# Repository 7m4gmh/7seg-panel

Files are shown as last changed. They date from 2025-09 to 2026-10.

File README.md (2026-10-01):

# 7-Segment LED Panel Video Player

A series of tools for playing videos on a custom display panel composed of I2C-connected 7-segment LED modules.

i2cで駆動する自作の7セグメントLEDパネルで、動画を再生するプロジェクト。

---

Note (platform): Developed and tested primarily on Raspberry Pi 3 and Radxa ROCK 5B. It also works on Raspberry Pi 4/5 if I2C is enabled and dependencies are installed (bus numbers/device names may differ).

**macOS Support**: The project includes emulator mode for macOS development and testing. Physical LED panels are automatically simulated with accurate segment rendering and audio synchronization.

注記（プラットフォーム）: 本プロジェクトは主に Raspberry Pi 3 および Radxa ROCK 5B 向けに作成・検証しています。I2C を有効化し依存関係を整えれば Raspberry Pi 4/5 でも動作します（バス番号やデバイス名が異なる場合があります）。

**macOS対応**: 本プロジェクトはmacOSでの開発・テスト用にエミュレータモードを搭載しています。物理的なLEDパネルを自動的にシミュレートし、正確なセグメント描画と音声同期を実現します。

**Languages:**

[**English**](README.en.md) | [**日本語**](README.ja.md) | [**繁體中文**](README.zh-TW.md)

---

**Module Mapping (モジュールマッピング)**

You can define per-module physical mappings in `config.json` to accommodate different wiring or digit order of hardware modules. Use a simple column-reversal flag (`module_column_reverse`) or an explicit logical→physical index map (`module_index_map`). See `docs/module-mapping.md` for details and examples.

ハードウェア毎に桁順や配線が異なる場合、`config.json` でモジュール単位のマッピングを定義できます。簡易的に列方向を反転する `module_column_reverse`（真偽値）を使うか、論理インデックス（左上から行優先）からモジュール内の物理インデックスへ明示的に変換する `module_index_map`（配列）を定義してください。優先順位は `module_index_map` → `module_column_reverse` → 既定順（row-major）です。詳しい書き方とテスト手順は `docs/module-mapping.md` を参照してください。

実機縮退モデルでのデモ動画

実機縮退モデルでのデモ動画 (https://www.instagram.com/reel/DOIo3QTEZs0/?utm_source=ig_web_button_share_sheet)

[エミュレータでの実行例](https://x.com/HijiriUmemoto/status/2095140881489899897?s=20)

---

## Hardware (KiCad)

- PCB projects live under `hardware/`. See: [hardware/README.md](hardware/README.md)
- Current folders (subject to change):
	- `hardware/7seg-led` — LED panel PCB
	- `hardware/7seg-control` — main controller PCB
	- `hardware/7seg-hat` — Raspberry Pi HAT
	- `hardware/7seg-power` — power board
	- Shared libs: `hardware/lib`
	- Legacy/migration folders may also exist (e.g., `hardware/led-panel`, `controller`, `rpi-hat`, `power`).

---
## Build

Prerequisites
- C++17-capable compiler (g++)
- make
- OpenCV 4 (dev package)
- SDL2 (dev package)
- GStreamer 1.0 (for RTP/HTTP streaming tools)

How to build
- By default, running `make` without arguments shows help and does not build anything.
- Use the grouped targets below as needed.

Common targets

```bash

# Show available targets (default)

make core

# GStreamer-based tools: http-streamer / rtp-player
make gst

# Individual targets
make rtp        # 7seg-rtp-player
# (http-streamerは削除済み)

# Everything
make all

# Cleanup
### macOS Emulator Support
The project includes macOS emulator support for development and testing without physical hardware:
- Automatically detects macOS and uses emulator mode
- Physical LED panel simulation with accurate segment shapes
- Optimized performance with pre-cached layouts
- Audio synchronization for smooth playback

**macOSでのビルド:**
```bash
# OpenCVのインストール
brew install opencv

# ビルド
make core

# エミュレータでのテスト
./7seg-file-player test.mp4 emulator-24x4
```

## Recent changes (video scaling behavior)

This project recently received fixes and improvements to the video scaling modes so behavior is consistent across orientations (horizontal/vertical) and between the real-device and emulator playback paths.

- FIT (default): the entire video is scaled to fit inside the display's physical aspect ratio. Black padding (letterboxing/pillarboxing) will be added on the shorter axis. Internally we compute a display-shaped ROI based on the configured module layout and physical character dimensions, scale the source to fit into that ROI, and pass only the ROI downstream for sampling. This prevents accidental cropping or distortion.

- CROP: the video is center-cropped to match the display's physical aspect ratio while preserving the source aspect ratio. After cropping the ROI is passed downstream without forcing a full W×H canvas resize, so the sampled region keeps correct proportions.

- STRETCH: the video is resized non-uniformly to fill the display-shaped ROI (i.e. aspect ratio is not preserved). This intentionally distorts the video to use the full display area.

These changes make the three modes behave predictably for combinations like horizontal video on vertical displays (FIT will letterbox, CROP will center-crop, STRETCH will distort to fill).

## Debug logging

A new runtime flag is available to enable extra debug output for scaling and ROI calculation.

Usage:
```bash
# Enable debug output
./bin/darwin-arm64/7seg-file-player <video> <config> --fit --debug

# Short form
./bin/darwin-arm64/7seg-file-player <video> <config> --fit -d
```

When enabled the player prints per-frame messages like:

- [FIT] source_aspect=... display_aspect=... roi=(x,y,w,h) dst=(w,h)
- [STRETCH] source_aspect=... display_aspect=... roi=(x,y,w,h)

The debug flag is off by default so normal runs are quiet.

## Notes for reviewers / maintainers

- The playback code now avoids forcing a W×H resize for FIT/CROP/STRETCH; we pass an appropriately-shaped ROI to the sampling logic so `frame_to_grid` sees the correct proportions.
- Debug prints are gated by the `--debug`/`-d` switch.
- Some small cleanups were applied (unused variables removed, minor refactor of logging points).

Tip
- For streaming, we recommend the net player with OBS via FLV/TCP:
	- [README.en.md](README.en.md) → "Send directly from OBS (FLV/TCP)"
	- [README.ja.md](README.ja.md) → 「OBSから直接送信（FLV/TCP）」
	- [README.zh-TW.md](README.zh-TW.md) → 「從 OBS 直接傳送（FLV/TCP）」
- Alternatively, the RTP player is available. See usage and sender examples:
	- [README.en.md](README.en.md) → "RTP Player (Recommended)"
	- [README.ja.md](README.ja.md) → 「RTPプレイヤー（推奨）」
	- [README.zh-TW.md](README.zh-TW.md) → 「RTP 播放器（建議）」
- macOS camera sender script included: `send_rtp_cam_gst.sh`
 - For browser-based control and uploads, use the HTTP player/streamer. See:
	 - [README.en.md](README.en.md) → "HTTP Player"
	 - [README.ja.md](README.ja.md) → 「HTTPプレイヤー」
	 - [README.zh-TW.md](README.zh-TW.md) → 「HTTP 播放器」
 - To play a local video file quickly, use the File Player. See:
	 - [README.en.md](README.en.md) → "File Player"
	 - [README.ja.md](README.ja.md) → 「ファイルプレイヤー」
	 - [README.zh-TW.md](README.zh-TW.md) → 「檔案播放器」

- **macOS Emulator**: For testing and development on macOS without physical hardware. See:
	 - [README.emulator.md](README.emulator.md) → "7-Segment LED Panel Emulator"
	 - 物理的なLEDパネルの正確なシミュレーション
	 - 動画ファイルからの再生と音声同期

- Tetris on the LED panel (Python):
	- [README.tetris.en.md](README.tetris.en.md)
	- [README.tetris.md](README.tetris.md)（日本語）
	- [README.tetris.zh-TW.md](README.tetris.zh-TW.md)

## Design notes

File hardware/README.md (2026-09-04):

# Hardware projects

基板ごとに独立した KiCad プロジェクトとして、世代・構成別のフォルダに配置しています。

This folder contains independent KiCad projects grouped by hardware generation and configuration.

## Directory structure

### 040 series

- `040/`
    - `7seg-panel-control-040/`
    - `7seg-panel-control-040-dual/`
    - `7seg-panel-control-040-single/`
    - `7seg-panel-control-04in/`
    - `7seg-panel-display-040-dual/`
    - `7seg-panel-display-040-dual-24x16/`
    - `7seg-panel-expand-040/`
    - `7seg-panel-power-040/`
    - `7seg-panel-single-04in/`
- `040-sparse/`
    - `7seg-panel-040-display-dual-wide/`
    - `7seg-panel-040-dual-combined-sparse/`

### 056 series

- `056/`
    - `7seg-control/`
    - `7seg-led/`
    - `7seg-panel-4digit/`
    - `7seg-panel-single-digit/`
    - `7seg-power/`
- `056-sparse/`
    - `7-seg-panel-0560dual combined-sparse/`
    - `7seg-panel-056-display-wide/`
    - `7seg-panel-056-single-combined-sparse/`
- `056-HT1635D/`
    - `056-ht1635d-driver/`

### Raspberry Pi HAT

- `7seg-hat/`
    - `7seg-hat.kicad_pro`, `7seg-hat.kicad_sch`, `7seg-hat.kicad_pcb`
    - `7seg-hat-backups/`
    - `20250729-7seg-led-panel-hat-backups/`
    - `20250815-7seg-led-panel-hat-backups/`
    - `bom/`
    - `production/`

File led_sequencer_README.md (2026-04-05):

# led_sequencer

`led_sequencer.py` はリポジトリ内の `config.json` を読み、7セグメント表示の点灯シーケンスを実行する簡易スクリプトです。

## 概要
- 各桁について、セグメント A → G を順に 0.5 秒おきに点灯します。
- その後、各桁ごとにその桁のみ全セグメントを 0.5 秒間点灯（他桁は消灯）します。
- 最後の桁が終わると最初に戻り、ループします。

## 必要条件
- Python 3.8+（型注釈の互換性のため）
- `config.json` がスクリプトと同じディレクトリに配置されていること（本リポジトリのルート `7seg-panel/config.json` を参照します）。

## 使い方

```bash
# デフォルト（delay=0.5s, 自動でエミュレータ構成を選択）
python3 led_sequencer.py

# レイアウトを指定する例（config.json のキー名を指定）
python3 led_sequencer.py --layout emulator-24x4

# ディレイを変更する例（秒単位）
python3 led_sequencer.py --delay 0.3
```

## 出力
- 実行中は標準出力にどの桁／セグメントを点灯したかがタイムスタンプ付きで表示されます。実機やエミュレータに接続する場合は、この部分を適宜置き換えてハード制御コードを追加してください。

## 統合のヒント
- エミュレータや実機制御が既にある場合、`print()` 部分をハードウェア駆動 API の呼び出しに差し替えてください。
- 複数プロセスや非同期での制御を行う場合は `asyncio` やスレッドを検討してください。

## ファイル
- スクリプト: `led_sequencer.py`
- 設定: `config.json` (同ディレクトリ)

---
作成者: リポジトリ補助スクリプト（自動生成）

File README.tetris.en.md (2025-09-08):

# Tetris (tetris.py) Run Guide

Instructions to prepare the environment and run the Python script `tetris.py` that drives the 7‑segment LED panel.

## Overview
- Operate the game in your terminal (curses) while rendering the board on an I2C 7‑segment LED panel.
- Supports both a setup with the TCA9548A I2C multiplexer and a direct (no‑mux) setup. See `config.json`.

## Requirements
- OS: Linux
- Python 3.8+
- pip (Python package manager)
- I2C enabled and a device node present (e.g., `/dev/i2c-0` or `/dev/i2c-1`)
- Python package: `smbus2`
- (Optional) I2C tools: `i2c-tools` (`i2cdetect` to verify devices)

## Enable and verify I2C
1) Enable I2C (use your board's config tool / device tree as appropriate)
2) Check device nodes
   ```bash
   ls -l /dev/i2c*
   # e.g. if /dev/i2c-0 exists use bus=0, if /dev/i2c-1 exists use bus=1
   ```
3) (Optional) I2C scan
   ```bash
   sudo apt-get update
   sudo apt-get install -y i2c-tools
   i2cdetect -l           # list available buses
   i2cdetect -y 0         # scan bus 0 (change number to your bus)
   ```

> Note: `tetris.py` uses I2C bus 0 by default (`SMBus(0)`). If your system uses `/dev/i2c-1`, change `SMBus(0)` to `SMBus(1)` in `tetris.py`.

## Setup (recommended: virtualenv)
```bash
# From repo root
python3 -m venv venv
source venv/bin/activate
pip install --upgrade pip
pip install smbus2
```

Permissions
- If you cannot access `/dev/i2c-*`, either:
  - Run with sudo temporarily, or
  - Add your user to the `i2c` group and re‑login:
    ```bash
    sudo usermod -aG i2c $USER
    # log out and back in to apply
    ```

## How to run
- Basic:
  ```bash
  python tetris.py --config 16x12
  ```
- `--config` is one of the names under `configurations` in `config.json`.
  - Examples: `24x4`, `12x8`, `16x8`, `16x12`, `48x4`, `12x8-direct`
- The board size is defined by the chosen config (e.g., `16x12` → 16×12 digits).

## Controls
- Left / Right: move horizontally
- Down: soft‑drop one cell (resets auto‑drop timer)
- Up or Space: rotate
- q: quit

## Config file (config.json) notes
- Pick a configuration name from `configurations` and pass it via `--config`.
- Addresses are hex strings (e.g., `"0x70"`) and are converted to integers in the script.
- With TCA9548A, set `tca9548a_address` to a hex string (e.g., `"0x77"`).
- For direct setups, set `tca9548a_address: null` and use `-1` as the key in `channel_grids`.
- Example: `16x12` uses 4×4‑digit modules arranged 4 (wide) × 3 (high) → total 16×12 digits.

## Troubleshooting
- I2C bus not found (`I2C bus device not found`)
  - Check that `/dev/i2c-*` exists. If your bus is 1, change to `SMBus(1)`.
  - Ensure I2C is enabled in the system.
- I/O errors (`I2C Write Error` or init failures)
  - Verify wiring, power, addresses (with `i2cdetect`), and TCA9548A channel selection.
  - Ensure `channel_grids` in `config.json` matches the actual wiring.
- Terminal issues (black/garbled output)
  - Ensure the terminal has enough width; otherwise visible ASCII render will wrap.
- Display not cleared on exit
  - In rare exceptions cleanup may fail; running the script again typically clears the display.

## Notes
- Auto‑drop speed increases with score (see constants near the top of the file to tune).
- Board rendering uses `'*'` and `'#'` (mapping to 7‑segment via `digit_map`).

---
Minimal example (16x12, bus 0)
```bash
# First‑time deps
python3 -m venv venv
source venv/bin/activate
pip install smbus2

# Run
python tetris.py --config 16x12
```

Bus 1 environment (requires code edit)
```text
# In tetris.py
- bus = SMBus(0)
+ bus = SMBus(1)
```

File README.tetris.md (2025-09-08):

# テトリス（tetris.py）実行ガイド

7セグパネル上でテトリスを動かす Python スクリプト `tetris.py` の環境整備と実行手順です。

## 概要
- 端末（curses）で操作しつつ、I2C接続の7セグパネルに盤面を描画します。
- I2Cマルチプレクサ TCA9548A を使う構成／使わない直結構成の両方に対応します（`config.json` 参照）。

## 必要環境
- OS: Linux
- Python 3.8+
- pip（Pythonパッケージ管理）
- I2Cが有効化されたカーネルとデバイスノード（例: `/dev/i2c-0` もしくは `/dev/i2c-1`）
- Pythonパッケージ: `smbus2`
- (任意) I2Cツール: `i2c-tools`（`i2cdetect` でデバイス確認）

## I2Cの有効化と確認
1) I2Cを有効化（ボードごとの手順に従って設定ツールやDTを有効化）
2) デバイスノード確認
   ```bash
   ls -l /dev/i2c*
   # 例: /dev/i2c-0 があれば bus=0、/dev/i2c-1 があれば bus=1
   ```
3) (任意) I2Cスキャナ
   ```bash
   sudo apt-get update
   sudo apt-get install -y i2c-tools
   i2cdetect -l           # 利用可能なバス一覧
   i2cdetect -y 0         # 0番バスのデバイスを走査（環境に合わせて番号変更）
   ```

> 注意: `tetris.py` は既定で I2C バス番号 0 を使用します（`SMBus(0)`）。環境が `/dev/i2c-1` の場合は、`tetris.py` 内の `SMBus(0)` を `SMBus(1)` に変更してください。

## セットアップ手順（推奨: 仮想環境）
```bash
# リポジトリ直下で
python3 -m venv venv
source venv/bin/activate
pip install --upgrade pip
pip install smbus2
```

権限まわり
- `/dev/i2c-*` へアクセスできない場合は、次のいずれかを実施
  - 一時的に sudo で実行する
  - ユーザーを `i2c` グループへ追加し、再ログイン
    ```bash
    sudo usermod -aG i2c $USER
    # 反映のため一度ログアウト/ログイン
    ```

## 実行方法
- 基本:
  ```bash
  python tetris.py --config 16x12
  ```
- `--config` は `config.json` の `configurations` に定義された名前を指定します。
  - 例: `24x4`, `12x8`, `16x8`, `16x12`, `48x4`, `12x8-direct`
- 盤面サイズは設定により決まります（例: `16x12` は 16桁×12桁）。

## 操作方法（キーバインド）
- ← / →: 水平移動
- ↓: 1マス落下（自動落下タイマーをリセット）
- ↑ または Space: 回転
- q: 終了

## 設定ファイル（config.json）の要点
- `configurations` から構成名を選びます（`--config` で指定）。
- アドレス表記は 16進文字列（例: `"0x70"`）。スクリプト側で数値へ変換されます。
- TCA9548A を使う場合は `tca9548a_address` に 16進文字列（例: `"0x77"`）を設定。
- 直結構成は `tca9548a_address: null` とし、`channel_grids` のキーに `-1` を用います。
- 例: `16x12` 構成は 4桁×4桁モジュールを横4×縦3で合計 16×12 桁。

## トラブルシューティング
- I2C バスが見つからない（`I2C bus device not found`）
  - `/dev/i2c-*` の存在を確認。バス番号が 1 なら `SMBus(1)` に変更。
  - I2C を有効化したか確認。
- I/O エラー（`I2C Write Error` や 初期化失敗）
  - 配線、電源、アドレス（`i2cdetect` で確認）、TCA9548A のチャンネル切替を確認。
  - `config.json` の `channel_grids` と実配線が一致しているか確認。
- 端末が真っ黒／文字化け
  - リモート端末の幅が狭いと可視表示が折り返すことがあります。端末幅を確保。
- 終了時に表示が消えない
  - 例外時に消去できないケースがあります。再実行すると最終化処理で消去されます。

## 補足
- 既定の落下速度はスコアに応じて速くなります（ファイル先頭の定数で調整可能）。
- 描画は `'*'` と `'#'` を使っています（7セグ表示器へのマッピングは `digit_map` に定義）。

---
最小構成の実行例（16x12, バスが 0 の場合）
```bash
# 依存インストール（初回のみ）
python3 -m venv venv
source venv/bin/activate
pip install smbus2

# 実行
python tetris.py --config 16x12
```

バスが 1 の環境例（コード修正の必要あり）
```text
# tetris.py の該当行
- bus = SMBus(0)
+ bus = SMBus(1)
```

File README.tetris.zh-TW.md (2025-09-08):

# 俄羅斯方塊（tetris.py）執行指南

本文件說明如何準備環境並執行 `tetris.py`，在 7 段顯示器 LED 面板上運行俄羅斯方塊。

## 概述
- 透過終端機（curses）操作，同步在 I2C 連接的 7 段顯示器面板上繪製棋盤。
- 同時支援使用 TCA9548A I2C 多工器的組態與不使用多工器的直連組態（見 `config.json`）。

## 系統需求
- OS: Linux
- Python 3.8+
- pip（Python 套件管理）
- 已啟用 I2C 並存在裝置節點（例如 `/dev/i2c-0` 或 `/dev/i2c-1`）
- Python 套件：`smbus2`
- （選用）I2C 工具：`i2c-tools`（用 `i2cdetect` 驗證裝置）

## 啟用並確認 I2C
1) 啟用 I2C（依您的開發板設定工具 / DT 流程）
2) 檢查裝置節點
   ```bash
   ls -l /dev/i2c*
   # 範例：若存在 /dev/i2c-0 則 bus=0；若存在 /dev/i2c-1 則 bus=1
   ```
3) （選用）I2C 掃描
   ```bash
   sudo apt-get update
   sudo apt-get install -y i2c-tools
   i2cdetect -l           # 列出可用的匯流排
   i2cdetect -y 0         # 掃描 0 號匯流排（依環境修改編號）
   ```

> 注意：`tetris.py` 預設使用 I2C 匯流排 0（`SMBus(0)`）。若系統使用 `/dev/i2c-1`，請將 `tetris.py` 內的 `SMBus(0)` 改為 `SMBus(1)`。

## 安裝步驟（建議：虛擬環境）
```bash
# 於倉庫根目錄
python3 -m venv venv
source venv/bin/activate
pip install --upgrade pip
pip install smbus2
```

權限
- 若無法存取 `/dev/i2c-*`，請：
  - 暫時以 sudo 執行，或
  - 將使用者加入 `i2c` 群組並重新登入：
    ```bash
    sudo usermod -aG i2c $USER
    # 重新登入以套用
    ```

## 執行方式
- 基本：
  ```bash
  python tetris.py --config 16x12
  ```
- `--config` 需為 `config.json` 之 `configurations` 下的名稱。
  - 範例：`24x4`, `12x8`, `16x8`, `16x12`, `48x4`, `12x8-direct`
- 棋盤尺寸由設定決定（例如 `16x12` → 16×12 位數）。

## 操作方式（快捷鍵）
- ← / →：水平移動
- ↓：下降一格（重設自動下落計時）
- ↑ 或 Space：旋轉
- q：結束

## 設定檔（config.json）重點
- 從 `configurations` 中選擇組態名稱，並以 `--config` 指定。
- 位址以十六進位字串表示（例如 `"0x70"`），腳本內會轉為數值。
- 使用 TCA9548A 時，`tca9548a_address` 請填十六進位字串（例如 `"0x77"`）。
- 直連組態請設 `tca9548a_address: null`，並在 `channel_grids` 中使用 `-1` 作為鍵。
- 例：`16x12` 使用 4×4 位數模組，橫向 4、縱向 3，合計 16×12 位數。

## 疑難排解
- 找不到 I2C 匯流排（`I2C bus device not found`）
  - 確認 `/dev/i2c-*` 存在。若為匯流排 1，請改成 `SMBus(1)`。
  - 確認系統已啟用 I2C。
- I/O 錯誤（`I2C Write Error` 或初始化失敗）
  - 檢查接線、電源、位址（用 `i2cdetect`）、TCA9548A 通道切換。
  - `config.json` 的 `channel_grids` 是否與實際接線相符。
- 終端機畫面全黑或亂碼
  - 若寬度不足，ASCII 繪圖會換行；請確保足夠寬度。
- 結束時面板未清除
  - 少數例外狀況清理可能失敗；再次執行通常會清除。

## 補充
- 自動下落速度會隨分數提升（可於檔案開頭的常數調整）。
- 棋盤繪圖使用 `'*'` 與 `'#'`（對應 7 段顯示器的 `digit_map`）。

---
最小範例（16x12，匯流排 0）
```bash
# 第一次安裝依賴
python3 -m venv venv
source venv/bin/activate
pip install smbus2

# 執行
python tetris.py --config 16x12
```

匯流排 1（需修改程式碼）
```text
# 於 tetris.py
- bus = SMBus(0)
+ bus = SMBus(1)
```

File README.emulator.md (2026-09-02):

# 7-Segment LED Panel Emulator

macOS上で7セグメントLEDパネルの動作をエミュレートするソフトウェアです。物理的なLEDパネルの正確な外観と動作をシミュレートします。

## 概要

このエミュレータは、i2cで動作する物理的な7セグメントLEDパネルを、macOS環境で視覚的に再現するためのツールです。OpenCVを使用して物理的なLEDの形状、傾き、配置を正確にシミュレートします。

## 主な特徴

### 🎯 正確な物理シミュレーション
- **7セグメントLED**: 物理的な7セグメントLEDの形状を正確に再現
- **スケール調整**: 8倍スケールで視認性を確保しつつ物理比率を維持

### ⚡ 高性能最適化
- **プリキャッシュ**: 起動時に全セグメントの座標を計算してメモリに格納
- **音声同期**: 動画再生時の音声との同期を最適化

### 🎮 使いやすいインターフェース
- **自動モード検出**: config.jsonから自動的にエミュレータモードを検出
- **リアルタイム表示**: OpenCVウィンドウでリアルタイムにLED表示
- **キーボード制御**: ESCキーで再生停止

## 必要条件

### システム要件
- **macOS** (10.15以上推奨)
- **C++17** 対応コンパイラ
- **OpenCV 4** (Homebrewでインストール)

### 依存関係のインストール
```bash
# HomebrewでOpenCVをインストール
brew install opencv

# SDL2もインストール（音声再生用）
brew install sdl2
```

## ビルド方法

### 完全ビルド
```bash
# すべてのターゲットをビルド
make all
```

### エミュレータ専用ビルド
```bash
# コアプレイヤーのみビルド（エミュレータを含む）
make core
```

## 使用方法

### 基本的な使い方

1. **設定ファイルの準備**
   ```json
   {
     "type": "emulator",
     "total_width": 24,
     "total_height": 4,
     "configurations": {
       "emulator-24x4": {
         "total_width": 24,
         "total_height": 4
       }
     }
   }
   ```

2. **動画ファイルの再生**
   ```bash
   # 設定ファイルで指定した構成で再生
   ./7seg-file-player video.mp4 emulator-24x4

   # または直接設定
   ./7seg-file-player video.mp4 emulator-20x20

  # 設定ファイルのパスを明示的に指定
  ./7seg-file-player video.mp4 emulator-36x16 --config-file ./config.json
   ```

### 設定オプション

#### ディスプレイサイズ
- `emulator-24x4`: 24桁 × 4行（標準サイズ）
- `emulator-20x20`: 20桁 × 20行（大画面）
- カスタムサイズも指定可能

#### 設定ファイル (config.json)
```json
{
  "type": "emulator",
  "total_width": 24,
  "total_height": 4,
  "configurations": {
    "emulator-24x4": {
      "total_width": 24,
      "total_height": 4
    }
  }
}
```

### 再生制御

- **ESCキー**: 再生停止
- **Ctrl+C**: プログラム終了

### MP4への録画

エミュレータ画面をそのまま MP4 に保存できます。録画時は音声も同時に記録され、通常のエミュレータ再生と同じ同期ロジックで出力されます。

```bash
./7seg-file-player video.mp4 emulator-24x4 --record-mp4 output.mp4
```

設定ファイルを別パスに置いている場合は、`--config-file` を併用できます。

```bash
./7seg-file-player video.mp4 emulator-36x16 --config-file ./config.json --record-mp4 output.mp4
```

録画先を指定すると、表示されるエミュレータ画面をそのまま書き出します。

## アーキテクチャ

### セグメント描画アルゴリズム

エミュレータは物理的な7セグメントLEDの正確な形状を再現するために、以下の計算を行っています：

1. **六角形セグメント生成**
   ```cpp
   // 横セグメントの六角形形状
   std::vector<cv::Point> horizontal_segment(double x, double y) {
       // 六角形の頂点座標を計算
   }
   ```

2. **縦セグメントの回転**
   ```cpp
   // 横セグメントを90±10度回転
   std::vector<cv::Point> vertical_segment(double x, double y, double tilt_deg)
   ```

3. **レイアウト計算**
   ```cpp
   // 全セグメントの最終位置を計算
   SegmentLayout make_layout(int digit_idx, double package_center_x, double package_center_y)
   ```

### パフォーマンス最適化

#### プリキャッシュシステム
```cpp
struct CachedDisplayLayout {
    std::vector<std::vector<std::vector<cv::Point>>> all_segs; // 全桁のセグメント
    std::vector<cv::Point> all_dp_centers; // 小数点位置
    std::vector<int> all_dp_radii; // 小数点半径
    std::vector<std::pair<double, double>> package_centers; // パッケージ中心座標
};
```

#### 音声同期
- 動画フレームの理想タイミングを計算
- 遅延が発生した場合のフレームスキップ処理
- 音声再生との同期維持

## 技術仕様

### 物理パラメータ
- **パッケージ幅**: 12.7mm
- **パッケージ高**: 19.05mm
- **セグメント長**: 6.0mm
- **セグメント幅**: 2.0mm
- **傾き角度**: 10度
- **表示スケール**: 8倍

### 色設定
- **点灯セグメント**: 赤 (BGR: 0, 0, 255)
- **消灯セグメント**: 灰色 (BGR: 80, 80, 80)
- **背景**: 黒 (BGR: 0, 0, 0)

## トラブルシューティング

### ビルドエラー
```bash
# OpenCVが見つからない場合
brew install opencv

# パスが通っていない場合
export PKG_CONFIG_PATH="/opt/homebrew/lib/pkgconfig:$PKG_CONFIG_PATH"
```

### 実行時エラー
```bash
# 動画ファイルが見つからない
ls -la video.mp4

# 設定ファイルの確認
cat config.json
```

### パフォーマンス問題
- **遅延が大きい**: ディスプレイサイズを小さくする
- **CPU使用率が高い**: より高性能なマシンを使用
- **メモリ不足**: ディスプレイサイズを調整

## 開発情報

### ソースコード構造
```
src/
├── playback.cpp          # メイン再生ロジック
├── emulator_display.cpp  # エミュレータ表示クラス（オリジナル）
└── common.h             # 共通定義
```

### 主要関数
- `play_video_stream_emulator()`: エミュレータ再生メイン関数
- `create_cached_layout()`: レイアウトプリキャッシュ関数
- `make_layout()`: 個別セグメントレイアウト計算
- `horizontal_segment()`: 横セグメント形状生成
- `vertical_segment()`: 縦セグメント形状生成

## 関連リンク

- [メインREADME](README.md)
- [英語版README](README.en.md)
- [日本語版README](README.ja.md)
- [テトリス版README](README.tetris.md)

## ライセンス

ライセンスについては考え中。ひとまず留保します。個人的に使っていただく分には自由です。

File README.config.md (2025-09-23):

# config.json の説明

## 概要

`config.json` は、7seg-panel のディスプレイ構成を定義する設定ファイルです。このファイルでは、LED パネルの物理的な接続構成を JSON 形式で記述します。主に TCA9548A I2C マルチプレクサを使用した複雑な接続をサポートしています。

## 基本構造

```json
{
  "comment_char_dimensions": "LED character dimensions in mm",
  "char_width_mm": 12.7,
  "char_height_mm": 19.2,

  "comment_configs": "Display panel configurations",
  "configurations": {
    "config_name": {
      "name": "Display Name",
      "buses": {
        "bus_id": {
          "tca9548as": [
            {
              "address": "0x77",
              "channels": {
                "channel_id": [
                  ["0x70", "0x71"],
                  ["0x72", "0x73"]
                ]
              }
            }
          ]
        }
      },
      "module_digits_width": 4,
      "module_digits_height": 4,
      "total_width": 8,
      "total_height": 8
    }
  }
}
```

## フィールドの詳細

### ルートレベル

- `char_width_mm`: 7セグメントLEDのパッケージの幅 (mm)
- `char_height_mm`: L7セグメントLEDのパッケージの高さ (mm)
- `configurations`: 各構成の定義

### configurations の各エントリ

- `name`: 構成の表示名
- `type`: 構成のタイプ ("physical" または "emulator") - オプション、デフォルトは "physical"
- `buses`: Bus の定義 (オブジェクト)
- `module_digits_width`: 各モジュールの桁数 (幅)
- `module_digits_height`: 各モジュールの桁数 (高さ)
- `total_width`: 全体の桁数 (幅)
- `total_height`: 全体の桁数 (高さ)

### buses

Bus ID をキーとするオブジェクト。各 Bus は以下の構造を持ちます：

- `tca9548as`: TCA9548A の配列

### tca9548as の各エントリ

- `address`: TCA9548A の I2C アドレス (16進数文字列、例: "0x77") または null (直接接続)
- `channels`: チャンネルの定義 (オブジェクト)
- `rows`: 行ベースのレイアウト定義 (オブジェクト、オプション)

### channels

チャンネル ID をキーとするオブジェクト。各チャンネルは LED モジュールのグリッド (2D 配列) を値とします。

- グリッドは行の配列
- 各行はモジュールアドレスの配列 (16進数文字列)

### rows (48x8 構成用)

行 ID をキーとするオブジェクト。各行は以下の構造を持ちます：

- `channel`: 使用する TCA9548A チャンネル ID
- `row_offset`: 行のオフセット (桁単位)
- `col_offset`: 列のオフセット (桁単位)

この設定は、異なるチャンネルが同じ行に配置される複雑なレイアウトで使用します。

## 例

### 単純な構成 (24x4)

```json
{
  "configurations": {
    "24x4": {
      "name": "24x4 Horizontal",
      "buses": {
        "0": {
          "tca9548as": [
            {
              "address": "0x77",
              "channels": {
                "0": [
                  ["0x70", "0x71", "0x72", "0x73", "0x74", "0x75"]
                ]
              }
            }
          ]
        }
      },
      "module_digits_width": 4,
      "module_digits_height": 4,
      "total_width": 24,
      "total_height": 4
    }
  }
}
```

### 複数の TCA9548A を使用した構成

```json
{
  "configurations": {
    "12x8": {
      "name": "12x8 Expanded",
      "buses": {
        "0": {
          "tca9548as": [
            {
              "address": "0x77",
              "channels": {
                "0": [
                  ["0x70", "0x71", "0x72"]
                ]
              }
            },
            {
              "address": "0x76",
              "channels": {
                "0": [
                  ["0x70", "0x71", "0x72"]
                ]
              }
            }
          ]
        }
      },
      "module_digits_width": 4,
      "module_digits_height": 4,
      "total_width": 12,
      "total_height": 8
    }
  }
}
```

### 直接接続の構成

```json
{
  "configurations": {
    "12x8-direct": {
      "name": "12x8 Direct",
      "buses": {
        "0": {
          "tca9548as": [
            {
              "address": null,
              "channels": {
                "-1": [
                  ["0x70", "0x71", "0x72"],
                  ["0x73", "0x74", "0x75"]
                ]
              }
            }
          ]
        }
      },
      "module_digits_width": 4,
      "module_digits_height": 4,
      "total_width": 12,
      "total_height": 8
    }
  }
}
```

### 48x8 行ベース構成 (rows 使用)

```json
{
  "configurations": {
    "48x8": {
      "name": "48x8 Expanded (4 channels with row-based layout)",
      "buses": {
        "1": {
          "tca9548as": [
            {
              "address": "0x77",
              "channels": {
                "0": [
                  ["0x70", "0x71", "0x72", "0x73", "0x74", "0x75"]
                ],
                "1": [
                  ["0x70", "0x71", "0x72", "0x73", "0x74", "0x75"]
                ],
                "2": [
                  ["0x70", "0x71", "0x72", "0x73", "0x74", "0x75"]
                ],
                "3": [
                  ["0x70", "0x71", "0x72", "0x73", "0x74", "0x75"]
                ]
              },
              "rows": {
                "0": {"channel": 0, "row_offset": 0, "col_offset": 0},
                "1": {"channel": 2, "row_offset": 0, "col_offset": 24},
                "2": {"channel": 1, "row_offset": 4, "col_offset": 0},
                "3": {"channel": 3, "row_offset": 4, "col_offset": 24}
              }
            }
          ]
        }
      },
      "module_digits_width": 4,
      "module_digits_height": 4,
      "total_width": 48,
      "total_height": 8
    }
  }
}
```

この構成では、4つの TCA9548A チャンネルが使用され、rows 設定により異なるチャンネルが同じ行に配置されます：
- 行0: チャンネル0 (左半分) と チャンネル2 (右半分) が同じ行に配置
- 行1: チャンネル1 (左半分) と チャンネル3 (右半分) が同じ行に配置

## 注意点

- アドレスは 16進数文字列で指定 (例: "0x70")
- 直接接続の場合、`address` を `null` に設定し、`channels` のキーを "-1" にする
- エミュレータの場合、`buses` を空オブジェクト `{}` に設定
- グリッドのサイズは `total_width` と `total_height` と一致するようにする
- TCA9548A のチャンネルは 0-7 の範囲を使用可能 (8チャンネル対応)

## 変更履歴

- 初期バージョン: 古い `tca9548a_address` と `channel_grids` 構造
- 現在のバージョン: `buses` 構造で複数の TCA9548A と Bus をサポート
- 48x8 対応: `rows` 構造で異なるチャンネルが同じ行に配置されるレイアウトをサポート</content>
<parameter name="filePath">/home/hijiri/7seg-panel/README.config.md

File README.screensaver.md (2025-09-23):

# LED Screensaver

7セグメントLEDパネル用のスクリーンセーバープログラムです。複数のアニメーションモードを備えています。

## 機能

- **IPアドレス表示**: 現在のIPアドレスをセンタリングして表示
- **Breakoutゲーム**: パドルでボールを跳ね返し、ブロックを破壊するゲーム
- **Invadersゲーム**: 砲台から弾を発射して敵を倒すゲーム
- **Miyajimaモード**: カウントアップアニメーション
- **Miyajima2モード**: カウントアップ + スクロールアニメーション
- **Clockモード**: 現在の時刻を表示

## インストール

依存パッケージのインストール:
```bash
pip install smbus2
```

## 実行方法

基本的な実行:
```bash
python screensaver.py
```

### コマンドラインオプション

- `--config CONFIG`: 設定ファイルの名前 (デフォルト: 16x12)
- `--mode MODE`: 固定モードで実行 (ip, breakout, invaders, miyajima, miyajima2, clock)
- `--test`: テスト表示モード

### 使用例

特定のモードで実行:
```bash
python screensaver.py --mode breakout
```

設定ファイルを指定:
```bash
python screensaver.py --config 48x8 --mode clock
```

テスト表示:
```bash
python screensaver.py --test
```

## 各モードの説明

### IPモード
現在のネットワークIPアドレスを取得して、ディスプレイの中央に表示します。

### Breakoutモード
古典的なブロック崩しゲームです：
- パドルが自動で左右に移動
- ボールが跳ね返る
- ブロックをすべて壊すとリセット

### Invadersモード
インベーダーゲーム風：
- 上部に敵が配置
- 下部に砲台があり、自動で弾を発射
- 敵をすべて倒すとリセット

### Miyajimaモード
カウントアップアニメーションを表示します。

### Miyajima2モード
カウントアップとスクロールアニメーションを組み合わせた表示です。

### Clockモード
現在の時刻をHH:MM:SS形式で表示します。

## 設定

`config.json`ファイルでディスプレイの構成を定義します。設定名を`--config`オプションで指定してください。

## システム要件

- Python 3.x
- smbus2ライブラリ
- I2C対応の7セグメントLEDパネル
- Raspberry PiなどのLinux環境

## ライセンス

このプロジェクトのライセンス情報を確認してください。

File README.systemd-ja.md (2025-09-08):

# 7seg-net-player を systemd サービスとして動かす手順

本書は 7seg-net-player（FLV/TCP または TS/UDP の受信再生）を systemd サービスとして常時運用するためのセットアップ手順です。

## 前提
- 本リポジトリを /home/radxa/7seg-panel に配置
- バイナリをビルド済み
  - `make net`
- 受信モード:
  - FLV/TCP: `./7seg-net-player flv <config> <port>`
  - TS/UDP : `./7seg-net-player ts  <config> <port>`
- デフォルト動作は EOS/ERROR で即終了（EXIT_ON_EOF=1 相当）

## 導入手順（root 権限）
1. ユニットと環境ファイルを配置
```bash
sudo install -m 644 systemd/7seg-net-player.service /etc/systemd/system/7seg-net-player.service
sudo install -m 644 systemd/7seg-net-player.env /etc/default/7seg-net-player
```

2. 環境ファイルを編集（モード/解像度/ポート等）
```bash
sudo editor /etc/default/7seg-net-player
# 例:
# WORKDIR=/home/radxa/7seg-panel
# MODE=flv
# CONFIG=16x12
# PORT=5004
# EXIT_ON_EOF=1
```

3. 起動・有効化
```bash
sudo systemctl daemon-reload
sudo systemctl enable --now 7seg-net-player.service
```

4. 状態/ログ
```bash
systemctl status 7seg-net-player.service
journalctl -u 7seg-net-player -f
```

## OBS/送信側の設定（FLV/TCP）
- OBS: 録画 → カスタム出力(FFmpeg)
  - コンテナ: flv
  - 出力URL: `tcp://<受信機IP>:<PORT>`
  - 映像: H.264 / 音声: AAC

## 運用メモ
- 本体は EOS/ERROR で即終了 → systemd が自動再起動し、常に待ち受けに戻ります。
- 終了させたくない場合は `/etc/default/7seg-net-player` の `EXIT_ON_EOF=0` に設定してください。
- `User`/`Group` は環境に合わせて `/etc/systemd/system/7seg-net-player.service` を編集してください。
- TS/UDP 運用に切替える場合は `MODE=ts` とし、送信側は MPEG-TS(UDP) を指定してください。

## アンインストール
```bash
sudo systemctl disable --now 7seg-net-player.service
sudo rm -f /etc/systemd/system/7seg-net-player.service
sudo rm -f /etc/default/7seg-net-player
sudo systemctl daemon-reload
```

---
補足: リポジトリ内の `stream.sh` でも同等の起動が可能です（常駐運用には systemd を推奨）。

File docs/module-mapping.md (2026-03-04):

**Module Mapping (モジュールマッピング)**

簡潔: パネルごとの物理的な桁・セグメント配置を `config.json` で定義できます。

**サマリ**:
- **目的**: ハードウェアごとに桁順や配線が違う場合に、プログラムを修正せず設定だけで対応する。
- **形式**: `module_column_reverse`（真偽値）または `module_index_map`（明示的なインデックス配列）を使用します。

**設定場所**:
- ファイル: [config.json](config.json)

**優先順位（フォールバック）**:
1. `module_index_map` が存在すればそれを使用（論理 -> 物理インデックスの完全マップ）
2. `module_column_reverse` が true なら列（横方向）を反転して適用
3. 上記が無ければ既定の行優先（row-major）順序を使用

**キーのルール**:
- モジュールのアドレスは文字列で指定します（例: `"0x70"`）。
- `module_index_map` の配列長は `module_digits_width * module_digits_height` と一致させてください。

**例: 列反転 (簡易)**
```
"module_column_reverse": {
  "0x70": true,
  "0x71": true
}
```

この場合、該当モジュール内の列順が左右反転されます（モジュールが左右逆に配線されているときに有効）。

**例: 明示的なインデックスマップ（推奨・柔軟）**
```
"module_index_map": {
  "0x70": [6,7,4,5,2,3,0,1,14,15,12,13,10,11,8,9],
  "0x71": [6,7,4,5,2,3,0,1,14,15,12,13,10,11,8,9]
}
```
配列インデックスの意味: 配列の位置 `i` が「論理インデックス」（左上から行優先で i=0..N-1）で、配列の値 `module_index_map[ i ]` がその論理位置に書き込むべき物理インデックス（モジュール内部の配線インデックス）です。

具体例: `module_digits_width=8, module_digits_height=2` の場合、論理インデックスは
```
 0 1 2 3 4 5 6 7
 8 9 A B C D E F
```
で表され、上記マップは各論理位置がどの物理位置に当たるかを指定します。

**コード側の振る舞い（参照用）**
- JSON 読み込み: [src/config_loader.hpp](src/config_loader.hpp) で `module_column_reverse` / `module_index_map` を読み込みます。
- マッピング適用: [src/led.cpp](src/led.cpp) の表示更新処理が、`module_index_map` を最優先で使い、無ければ `module_column_reverse` を参照します。

**テスト方法**
- 既存のテスト設定を使う:
  - `8x2-direct-map` / `8x4-direct-rev` はサンプルです。
- ビルドと起動:
```
make core
sudo ./bin/*/7seg-udp-player 5000 8x4-direct-rev
```
- マッピング確認用スクリプト:
  - `scripts/test_mapping.py --name <config> --live` で各文字位置を順に点灯できます（`smbus2` が必要）。

**実践的なアドバイス**
- まず `module_index_map` を作って小さな範囲で試すと確実です。
- モジュールごとに異なる配線がある場合は、各アドレスに対して個別に `module_index_map` を指定します。

**参考ファイル**:
- JSON 読み込み: [src/config_loader.hpp](src/config_loader.hpp)
- マッピング適用: [src/led.cpp](src/led.cpp)
- 例設定: [config.json](config.json)

---

必要があればこのドキュメントに図や追加例（4x4 の例、8x2 の物理配線図）を追加します。どの例を足しましょうか？

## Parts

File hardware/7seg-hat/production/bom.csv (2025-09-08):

Designator | Footprint | Quantity | Value | LCSC Part #
C101 | CP_EIA-3528-21_Kemet-B | 1 | 22uF
C103 | 0603 | 1 | 22uF 6V
J101, J104 | JST_XH_S2B-XH-A-1_1x02_P2.50mm_Horizontal | 2 | i2c
J102 | RPI_Hat_B+ | 1 | Raspberry_Pi_4
J103 | JST_XH_S2B-XH-A-1_1x02_P2.50mm_Horizontal | 1 | GND-VDD
Q101, Q102 | SOT-23_Handsoldering | 2 | BSS138
R101, R102, R103, R104 | 0603 | 4 | 4k7R
U101 | TO-220-3_Vertical | 1 | K7805M-2000

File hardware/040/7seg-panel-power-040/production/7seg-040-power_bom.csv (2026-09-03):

Designator | Footprint | Quantity | Value | LCSC Part #
C101 | CP_EIA-3528-21_Kemet-B | 1 | 22uF
C102 | 0805 | 1 | 4700pF (472)
C104 | 0603 | 1 | 22uF 6V
C106 | CP_Radial_D6.3mm_P2.50mm | 1 | 220uF
C108 | 0805 | 1 | 1uF
F102 | 2920 | 1 | Polyfuse 4A
J101, J104 | Generic_XH_S2B-XH-A-1_1x02_P2.50mm_Horizontal | 2 | +35V GND
J102 | USB_C_Receptacle_HRO_TYPE-C-31-M-17 | 1 | USB_C_Receptacle_PowerOnly_6P
J103 | Generic_XH_S2B-XH-A-1_1x02_P2.50mm_Horizontal | 1 | +5V GND
J201, J202 | BarrelJack_Singatron_2DC-0415D200-SMT_Horizontal | 2 | Barrel_Jack_Switch
R104 | 0805 | 1 | 1MR
R105, R106 | 0805 | 2 | 5k1R
R107 | 0805 | 1 | 200kR
R108 | 1210 | 1 | 1kR
U101 | TO-220-3_Vertical | 1 | K7805M-2000
U103 | TSOT-23-6_HandSoldering | 1 | CH221K

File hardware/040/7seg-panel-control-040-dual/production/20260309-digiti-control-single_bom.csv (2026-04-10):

Designator | Footprint | Quantity | Value | LCSC Part #
C102, C105 | 0603 | 2 | 22uF
C104, C107 | 0603 | 2 | 0.1uF
D102, D103 | D_SOD-123 | 2 | 1N4148W
J102, J105, J108, J112, J115, J118 | PinSocket_2x04_P2.54mm_Vertical | 6 | Conn_02x04_Odd_Even
J107, J117 | Generic_XH_S2B-XH-A-1_1x02_P2.50mm_Horizontal | 2 | I2C
J110, J120 | PinHeader_2x03_P2.54mm_Vertical | 2 | Conn_02x03_Odd_Even
J113, J114 | Generic_XH_S2B-XH-A-1_1x02_P2.50mm_Horizontal | 2 | +5V
R102, R103, R104, R105, R106, R107 | 0603 | 6 | 39kR
U102, U103 | SOP-28_8.4x18.16mm_P1.27mm | 2 | HT16K33-28-SOPA

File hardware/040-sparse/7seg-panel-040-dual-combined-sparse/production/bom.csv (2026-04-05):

Designator | Footprint | Quantity | Value | LCSC Part #
C103 | 0603 | 1 | 22uF
C106, C107 | 0603 | 2 | 0.1uF
D102, D103 | D_SOD-123 | 2 | 1N4148W
J114, J115 | JST_XH_B2B-XH-AM_1x02_P2.50mm_Vertical | 2 | +5V
J116, J117 | PinHeader_2x03_P2.54mm_Vertical | 2 | Conn_02x03_Odd_Even
J118, J121 | JST_XH_B2B-XH-AM_1x02_P2.50mm_Vertical | 2 | I2C
R124, R125, R126, R127, R128, R129 | 0603 | 6 | 39kR
U100, U101, U102, U103, U104, U105, U106, U107, U108, U109, U110, U111, U112, U113, U114, U115 | YH-2E20402-12P | 16 | YH-2E20402-IK
U116, U117 | SSOP-28_3.9x9.9mm_P0.635mm | 2 | HT16K33-28-SSOPA

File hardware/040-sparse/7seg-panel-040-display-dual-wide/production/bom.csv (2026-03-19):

Designator | Footprint | Quantity | Value | LCSC Part #
J100, J101, J102, J103, J104, J105 | PinHeader_2x04_P2.54mm_Vertical | 6 | Conn_02x04_Odd_Even
U100, U101, U102, U103, U104, U105, U106, U107, U108, U109, U110, U111, U112, U113, U114, U115 | YH-2E20402-12P | 16 | YH-2E20402-IK

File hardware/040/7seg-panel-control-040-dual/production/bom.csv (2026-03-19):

Designator | Footprint | Quantity | Value | LCSC Part #
C103 | 0603 | 1 | 22uF
C106 | 0603 | 1 | 0.1uF
D102 | D_SOD-123 | 1 | 1N4148W
J108, J110, J112 | PinSocket_2x04_P2.54mm_Vertical | 3 | Conn_02x04_Odd_Even
J114, J115 | JST_XH_S2B-XH-A_1x02_P2.50mm_Horizontal | 2 | +5V
J116 | PinHeader_2x03_P2.54mm_Vertical | 1 | Conn_02x03_Odd_Even
J118, J121 | JST_XH_S2B-XH-A_1x02_P2.50mm_Horizontal | 2 | I2C
R124, R125, R126 | 0603 | 3 | 39kR
U103 | SOP-28_8.4x18.16mm_P1.27mm | 1 | HT16K33-28-SOPA

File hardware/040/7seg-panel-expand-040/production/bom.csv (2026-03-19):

Designator | Footprint | Quantity | Value | LCSC Part #
C102 | 0603 | 1 | 22uF
C105 | 0603 | 1 | 0.1uF
J101 | Generic_XH_S2B-XH-A-1_1x02_P2.50mm_Horizontal | 1 | CH1
J102, J104 | JST_XH_B2B-XH-AM_1x02_P2.50mm_Vertical | 2 | I2C
J103 | Generic_XH_S2B-XH-A-1_1x02_P2.50mm_Horizontal | 1 | CH2
J105 | Generic_XH_S2B-XH-A-1_1x02_P2.50mm_Horizontal | 1 | CH3
J106 | Generic_XH_S2B-XH-A-1_1x02_P2.50mm_Horizontal | 1 | CH4
J107 | Generic_XH_S2B-XH-A-1_1x02_P2.50mm_Horizontal | 1 | CH6
J109 | Generic_XH_S2B-XH-A-1_1x02_P2.50mm_Horizontal | 1 | CH7
J111 | Generic_XH_S2B-XH-A-1_1x02_P2.50mm_Horizontal | 1 | CH8
J113 | Generic_XH_S2B-XH-A-1_1x02_P2.50mm_Horizontal | 1 | CH5
J117 | PinHeader_2x03_P2.54mm_Vertical | 1 | Conn_02x03_Odd_Even
J119, J120 | JST_XH_B2B-XH-AM_1x02_P2.50mm_Vertical | 2 | +5V
JP101 | PinHeader_1x03_P2.54mm_Vertical | 1 | A2
R107, R108, R109, R110, R111, R112, R113, R114, R115, R116, R117, R118, R119, R120, R121, R122, R123 | 0603 | 17 | 4.7kR
U102 | TSSOP-24_4.4x7.8mm_P0.65mm | 1 | TCA9548APWR

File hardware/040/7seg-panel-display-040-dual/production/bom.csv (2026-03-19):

Designator | Footprint | Quantity | Value | LCSC Part #
J100_12, J100_11, J100_10, J100_9, J100_8, J100_7, J100_6, J100_5, J100_4, J100_3, J100_2, J100, J101_12, J101_11, J101_10, J101_9, J101_8, J101_7, J101_6, J101_5, J101_4, J101_3, J101_2, J101, J102_12, J102_11, J102_10, J102_9, J102_8, J102_7, J102_6, J102_5, J102_4, J102_3, J102_2, J102, J103_12, J103_11, J103_10, J103_9, J103_8, J103_7, J103_6, J103_5, J103_4, J103_3, J103_2, J103, J104_12, J104_11, J104_10, J104_9, J104_8, J104_7, J104_6, J104_5, J104_4, J104_3, J104_2, J104, J105_12, J105_11, J105_10, J105_9, J105_8, J105_7, J105_6, J105_5, J105_4, J105_3, J105_2, J105 | PinHeader_2x04_P2.54mm_Vertical | 72 | Conn_02x04_Odd_Even
U100_12, U100_11, U100_10, U100_9, U100_8, U100_7, U100_6, U100_5, U100_4, U100_3, U100_2, U100, U101_12, U101_11, U101_10, U101_9, U101_8, U101_7, U101_6, U101_5, U101_4, U101_3, U101_2, U101, U102_12, U102_11, U102_10, U102_9, U102_8, U102_7, U102_6, U102_5, U102_4, U102_3, U102_2, U102, U103_12, U103_11, U103_10, U103_9, U103_8, U103_7, U103_6, U103_5, U103_4, U103_3, U103_2, U103, U104_12, U104_11, U104_10, U104_9, U104_8, U104_7, U104_6, U104_5, U104_4, U104_3, U104_2, U104, U105_12, U105_11, U105_10, U105_9, U105_8, U105_7, U105_6, U105_5, U105_4, U105_3, U105_2, U105, U106_12, U106_11, U106_10, U106_9, U106_8, U106_7, U106_6, U106_5, U106_4, U106_3, U106_2, U106, U107_12, U107_11, U107_10, U107_9, U107_8, U107_7, U107_6, U107_5, U107_4, U107_3, U107_2, U107, U108_12, U108_11, U108_10, U108_9, U108_8, U108_7, U108_6, U108_5, U108_4, U108_3, U108_2, U108, U109_12, U109_11, U109_10, U109_9, U109_8, U109_7, U109_6, U109_5, U109_4, U109_3, U109_2, U109, U110_12, U110_11, U110_10, U110_9, U110_8, U110_7, U110_6, U110_5, U110_4, U110_3, U110_2, U110, U111_12, U111_11, U111_10, U111_9, U111_8, U111_7, U111_6, U111_5, U111_4, U111_3, U111_2, U111, U112_12, U112_11, U112_10, U112_9, U112_8, U112_7, U112_6, U112_5, U112_4, U112_3, U112_2, U112, U113_12, U113_11, U113_10, U113_9, U113_8, U113_7, U113_6, U113_5, U113_4, U113_3, U113_2, U113, U114_12, U114_11, U114_10, U114_9, U114_8, U114_7, U114_6, U114_5, U114_4, U114_3, U114_2, U114, U115_12, U115_11, U115_10, U115_9, U115_8, 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 | YH02E20402-12P | 192 | YH-2E20402-IK

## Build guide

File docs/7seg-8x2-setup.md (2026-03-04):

# 7セグLEDパネル（横8桁×縦2桁）設定ガイド

このドキュメントは、横8桁×縦2桁（合計16桁）の7セグLEDパネルを動作させるための設定手順・配線例・config.json のサンプル・テスト方法をまとめたものです。

## 概要
- パネル構成: 横8桁 × 縦2桁（合計16桁）
- 表示方式: ドライバ（MAX7219, HT16K33 等）を使うか、GPIOによるマルチプレックスで直接駆動するか

## 基本ルール
- セグメントビット順は統一する（例: `a,b,c,d,e,f,g,dp` を bit0..bit7 に割当）
- 桁インデックスは row-major（上段左→右: 0..7、下段左→右: 8..15）を推奨

## ハードウェア選択の指針
- MAX7219 (SPI): 複数デバイスをチェーン可能。扱いやすく小規模7セグに最適。
- HT16K33 (I2C): I2Cバスで複数アドレスを扱える。
- GPIO マルチプレックス: 外部トランジスタ等で16桁のコモン駆動が必要。制御は高頻度スキャン（例: 500–1000Hz）。

## 配線要点（代表例）

### MAX7219（SPI）
- `DIN` → MCU `MOSI`
- `CLK` → MCU `SCLK`
- `CS`  → MCU `CE`（/CS）
- VCC/GND を共通に。MCUが3.3VでMAX7219が5Vの場合はレベル変換が必要。

### HT16K33（I2C）
- `SDA`, `SCL` を I2C バスへ接続（プルアップ抵抗を確認）
- 電源・GNDを共通に

### GPIO（マルチプレックス）
- セグメントライン（a..g, dp）を全桁で共通接続（8本）
- 各桁のコモン（digit select）を個別トランジスタで駆動（16本）
- トランジスタのベースに現在制限抵抗、コモン側に電源を正しく接続
- スキャン周波数（refresh_hz）を 500–1000Hz 程度に設定

## 推奨 `config.json` フィールド
- `panel`:
  - `cols`: 8
  - `rows`: 2
  - `digits`: 16（自動計算でも可）
  - `orientation`: 0 | 90 | 180 | 270
- `driver`:
  - `type`: "max7219" | "ht16k33" | "gpio"
  - ドライバ固有の設定項目（下記サンプル参照）
- `segment_map`（オプション）: セグメントビットのマップ
- `scan_order`: "row-major"（または "col-major"）

## 設定例 — MAX7219 用
```json
{
  "panel": { "cols": 8, "rows": 2, "digits": 16, "orientation": 0 },
  "driver": {
    "type": "max7219",
    "spi_bus": 0,
    "cs_pin": 0,
    "num_devices": 2,
    "brightness": 8
  },
  "segment_map": { "bit_order": ["a","b","c","d","e","f","g","dp"] },
  "scan_order": "row-major"
}
```

### 設定例 — GPIO（マルチプレックス）概念
```json
{
  "panel": { "cols": 8, "rows": 2, "digits": 16 },
  "driver": {
    "type": "gpio",
    "segment_pins": [17,18,27,22,23,24,25,4],
    "digit_pins": [5,6,13,19,26,12,16,20,21,7,8,9,10,11,14,15],
    "active_low": true,
    "refresh_hz": 800
  },
  "segment_map": { "bit_order": ["a","b","c","d","e","f","g","dp"] }
}
```

> 注: ピン番号はサンプルです。実際は使用するボード（Raspberry Pi 等）のGPIO番号に合わせてください。

## セグメントビットマップ（推奨）
- 1バイト（8ビット）で1桁を表現する方式を推奨
  - bit0 = a
  - bit1 = b
  - bit2 = c
  - bit3 = d
  - bit4 = e
  - bit5 = f
  - bit6 = g
  - bit7 = dp

- 例: 数字 0 = a+b+c+d+e+f -> 0b00111111 (0x3F)

## 桁インデックス割当（row-major）
- 上段（row 0）: index 0..7（左→右）
- 下段（row 1）: index 8..15（左→右）

視覚イメージ:

上段: [0] [1] [2] [3] [4] [5] [6] [7]

下段: [8] [9] [10] [11] [12] [13] [14] [15]

## テスト手順（簡易）
1. ドライバ接続確認
   - MAX7219: SPI が通っているか確認（`spidev` 等）
   - HT16K33: `i2cdetect -y 1` でアドレス確認
2. エミュレータで表示確認
   - リポジトリに含まれる `7seg_emulator.py` を使って表示を確認できます。
   - 例:
```bash
python3 7seg_emulator.py --config config.json
```
  （スクリプトの引数は実装に依存します。`--help` を参照してください）
3. 実機での段階的チェック
   - 全セグ点灯パターン（0xFF）を各桁に出力し、配線・短絡の確認
   - 各桁に 0..9 の数字を順に表示させる

## トラブルシューティング
- 片桁だけ点灯しない: 桁選択（コモン）配線やトランジスタを確認
- 全桁同一パターン: セグメント共通配線の短絡を疑う
- ちらつき・点滅: `refresh_hz` を上げる／ソフトウェア側でのスキャンタイミングを見直す
- 文字順がずれる: `orientation` や `scan_order`、`segment_map` を確認

## リポジトリ内の参考ファイル
- エミュレータ: `7seg_emulator.py`
- 既存設定: `config.json`

## 次の推奨作業
- 実際にお使いのハード（MAX7219 / HT16K33 / GPIO）を指定してください。指定いただければ具体的な配線図（GPIO番号）と `config.json` の実機向けサンプルを作成します。

## 物理配線と I2C（Raspberry Pi 向け注意点）
以下は `8x2` を TCA/エクスパンダなしで **直接 I2C モジュール（アドレス 0x70）** として接続する場合の注意点と配線例です。

- 電源: モジュールの VCC が **3.3V** か **5V** かを確認してください。Raspberry Pi の I2C は 3.3V ロジックなので、モジュールが5Vロジックならレベルシフタを必須で使用してください。
- SDA/SCL: モジュールの `SDA` を Pi の `SDA`、`SCL` を Pi の `SCL` に接続します（Raspberry Pi の GPIO ピンはモデルにより異なりますが、一般的にはピン3=SDA, ピン5=SCL）。
- GND: Pi とモジュールの GND を必ず共通接続してください。
- プルアップ: 多くの I2C モジュールは基板上にプルアップ抵抗を搭載しています。ない場合は 3.3V 側に 2.2k–10kΩ のプルアップ抵抗を追加してください。
- アドレス確認: 接続後に Pi で `i2cdetect -y 1` を実行して `0x70` が見えることを確認してください。

配線例（Raspberry Pi GPIO ヘッダ、3.3V ロジック）:

- Pi 3.3V (pin 1) -> モジュール VCC (if module requires 3.3V)
- Pi GND (pin 6) -> モジュール GND
- Pi SDA (pin 3, GPIO2) -> モジュール SDA
- Pi SCL (pin 5, GPIO3) -> モジュール SCL

チェックリスト（トラブルシュート順）:
- `i2cdetect -y 1` で `0x70` が表示されない場合:
  - 配線の向き（SDA/SCL/GND/VCC）を再確認
  - 電源電圧がモジュール仕様に合っているか確認
  - 別の I2C バス（`/dev/i2c-0` など）を試す（Pi の機種や設定でバス番号が異なることがある）
  - モジュールに 3.3V プルアップがない場合は手動で追加
- 初期化エラーが出る場合（`initialize_displays` が失敗）:
  - `config.json` の該当エントリに `"buses": { "0": { ... } }` が正しく設定されているか
  - モジュールアドレスを 0x70 として `"0x70"` で指定しているか（JSON 内は文字列で16進表記）

実行例（エミュレータではなく実機で動かす）:
```bash
./7seg-file-player ./videos/my_video.mp4 8x2-direct
```

注: 実機で動かす際は `config.json` の `8x2-direct` の `buses` が適切な I2C バス番号（通常 `0` または `1`）を指しているかを確認してください。

---
作成者: 7seg-panel ドキュメント自動生成

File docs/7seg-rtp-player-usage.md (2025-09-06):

# 7seg-rtp-player の使い方

## 1. ビルド（ワンライナー）
既存の Makefile を触らず試験する場合は、以下のコマンドで `7seg-rtp-player` をビルドできます。

```bash
g++ -std=c++17 -O2 \
  -Iinclude -Isrc \
  src/rtp_player.cpp src/common.cpp src/led.cpp src/video.cpp src/audio.cpp src/playback.cpp \
  -o 7seg-rtp-player \
  $(pkg-config --cflags --libs gstreamer-1.0 gstreamer-app-1.0 opencv4 sdl2)
```

- 依存が足りない場合（例: `pkg-config` エラー）は `libgstreamer1.0-dev gstreamer1.0-plugins-base libgstreamer-plugins-base1.0-dev libopencv-dev libsdl2-dev` 等を導入してください。

## 2. 起動
```bash
# 例: config.json 内の 16x16_expanded を使い、Video:5004, Audio:5006 を受信
./7seg-rtp-player 16x16_expanded 5004 5006
```

## 3. 送信テスト
別マシン、または同一マシンから以下を実行して映像/音声を送信してください。

### テストパターン（カラーバー + 440Hz）
```bash
chmod +x tools/send_rtp_test_gst.sh
./tools/send_rtp_test_gst.sh <RECEIVER_IP> 5004 5006
```

### 動画ファイル送出
```bash
chmod +x tools/send_rtp_from_file_gst.sh
./tools/send_rtp_from_file_gst.sh <RECEIVER_IP> ./video.mp4 5004 5006
```

## 4. チューニング
- `rtpjitterbuffer latency` を 30–120ms で調整（Wi‑Fi では大きめ）
- `x264enc` の `bitrate` と `key-int-max`（キーフレーム間隔）を環境に合わせて調整
- LED 側の画素に合わせて、受信後のリサイズや減色は `video_thread` 内で既存処理を流用

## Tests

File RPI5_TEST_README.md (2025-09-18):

# RPi5でのテスト手順

このドキュメントでは、差分レンダリング最適化を実装した7-Segment LED PanelソフトウェアをRaspberry Pi 5でテストする方法を説明します。

## 前提条件

- Raspberry Pi 5 (RPi5)
- Raspberry Pi OS (64-bit) がインストール済み
- SSH接続が可能
- インターネット接続が可能

## テスト手順

### 1. ソースコードの転送

macOSからRPi5へソースコードを転送します：

```bash
# macOS側で圧縮
cd "/Users/hijiri/Library/Mobile Documents/com~apple~CloudDocs/0000 prototyping/20250821-7seg-led-panel-software/7seg-panel"
tar -czf 7seg-panel.tar.gz .

# RPi5へ転送 (RPi5のIPアドレスに合わせて変更してください)
scp 7seg-panel.tar.gz pi@192.168.1.xxx:~
```

### 2. RPi5での展開とビルド

RPi5上で以下のコマンドを実行：

```bash
# ファイルの展開
tar -xzf 7seg-panel.tar.gz
cd 7seg-panel

# ビルドスクリプトの実行
./build_rpi5.sh
```

### 3. テスト結果の確認

ビルドスクリプトは以下のテストを自動的に実行します：

1. **パフォーマンスベンチマーク**
   - 1000フレームのレンダリング時間を測定
   - FPSと平均フレーム時間を表示

2. **エミュレータモードテスト**
   - ファイルプレイヤーをエミュレータモードで実行
   - 10秒間テスト（タイムアウト）

## 期待される結果

### パフォーマンス比較

現在の最適化版（差分レンダリング）:
- **FPS: ~60.86** (macOSでの測定)
- **フレーム時間: ~16.43ms**

RPi5での期待値:
- FPS: 50-70程度（ハードウェア性能による）
- 差分レンダリングにより、毎回全セグメント再描画する場合より大幅に高速

### テスト成功の兆候

1. ビルドが成功し、バイナリが生成される
2. ベンチマークが正常に実行され、FPSが表示される
3. エミュレータモードでウィンドウが表示される（GUI環境の場合）

## トラブルシューティング

### 依存関係のインストールエラー

```bash
# パッケージリストの更新
sudo apt update

# 個別インストール
sudo apt install libopencv-dev
sudo apt install libsdl2-dev
sudo apt install libgstreamer1.0-dev
```

### コンパイルエラー

```bash
# メモリ不足の場合
make -j1  # 並列ビルドを無効化

# 詳細なエラー確認
make 2>&1 | tee build.log
```

### GUI表示の問題

RPi5でGUIが表示されない場合：

```bash
# X11フォワーディングの確認
echo $DISPLAY

# またはヘッドレスモードでテスト
export DISPLAY=:0
```

## 結果の報告

テスト結果を以下の形式で報告してください：

```
=== RPi5 Test Results ===

Build: SUCCESS/FAILED
Benchmark FPS: XX.XX
Benchmark Frame Time: XX.XX ms
Emulator Test: SUCCESS/FAILED

Hardware: Raspberry Pi 5
OS: Raspberry Pi OS 64-bit
OpenCV Version: X.X.X
SDL Version: X.X.X

Additional Notes:
- [テスト時の特記事項]
```

## 次のステップ

1. RPi5でのテストが成功したら、物理的なLEDパネルでのテスト
2. 必要に応じてさらなる最適化
3. 実世界でのビデオ再生テスト

---

**注意**: このテストはエミュレータモードのみを対象としています。物理的なLEDパネルを使用する場合は、別途I2C設定とハードウェア接続が必要です。

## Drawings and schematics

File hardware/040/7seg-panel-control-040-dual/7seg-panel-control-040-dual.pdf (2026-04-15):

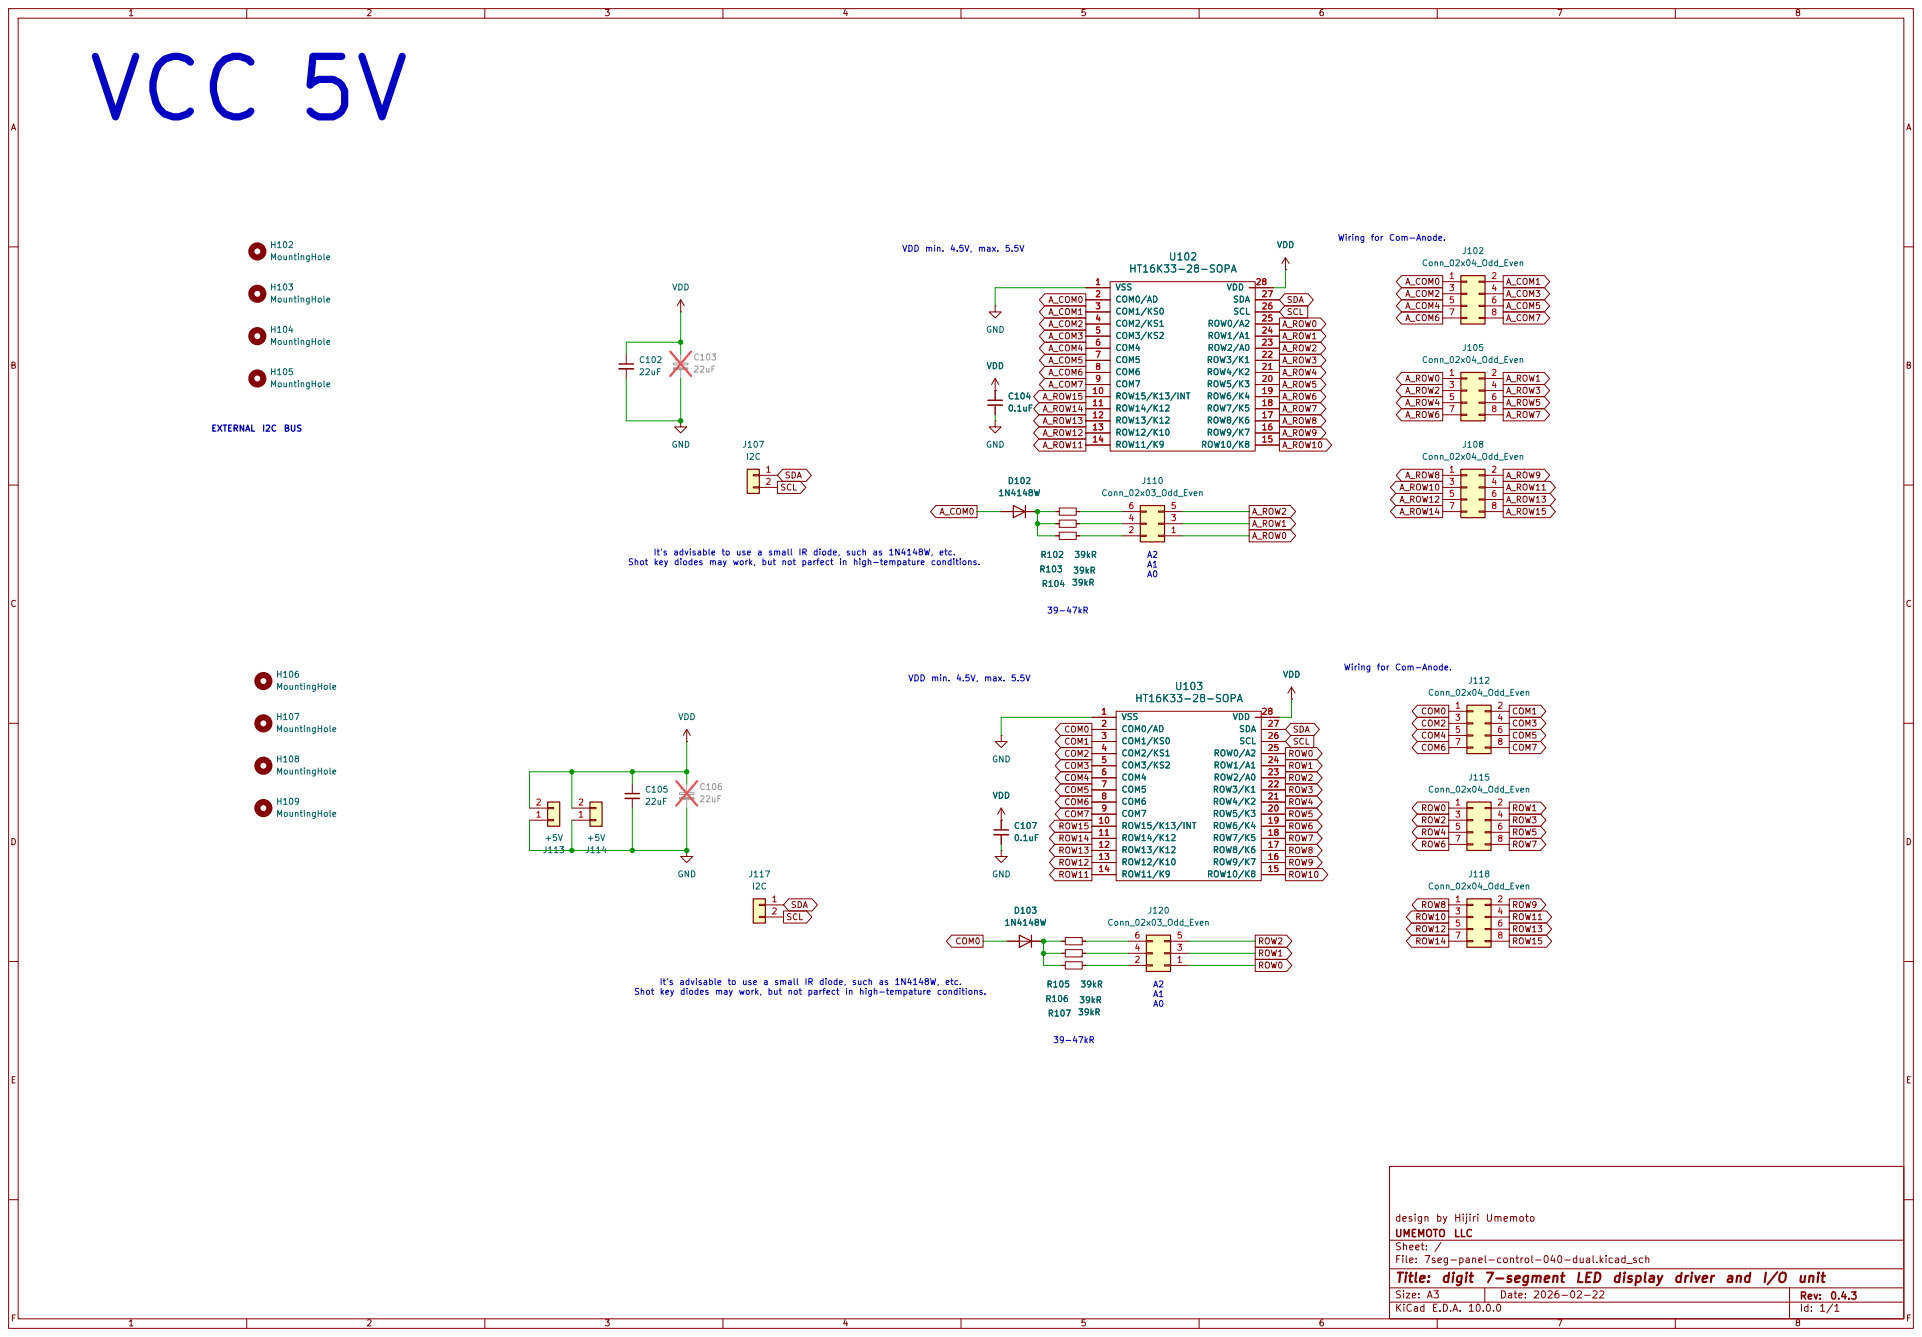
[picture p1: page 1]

It's advisable to use a small IR diode, such as 1N4148W, etc. Shot key diodes may work, but not parfect in high-tempature conditions. VDD min. 4.5V, max. 5.5V

design by Hijiri Umemoto
UMEMOTO LLC
Sheet: /

File: 7seg-panel-control-040-dual.kicad_sch
Title: digit 7-segment LED display driver and I/O unit

Size: A3 | Rev: 0.4.3 | F Date: 2026-02-22 KiCad E.D.A. 10.0.0

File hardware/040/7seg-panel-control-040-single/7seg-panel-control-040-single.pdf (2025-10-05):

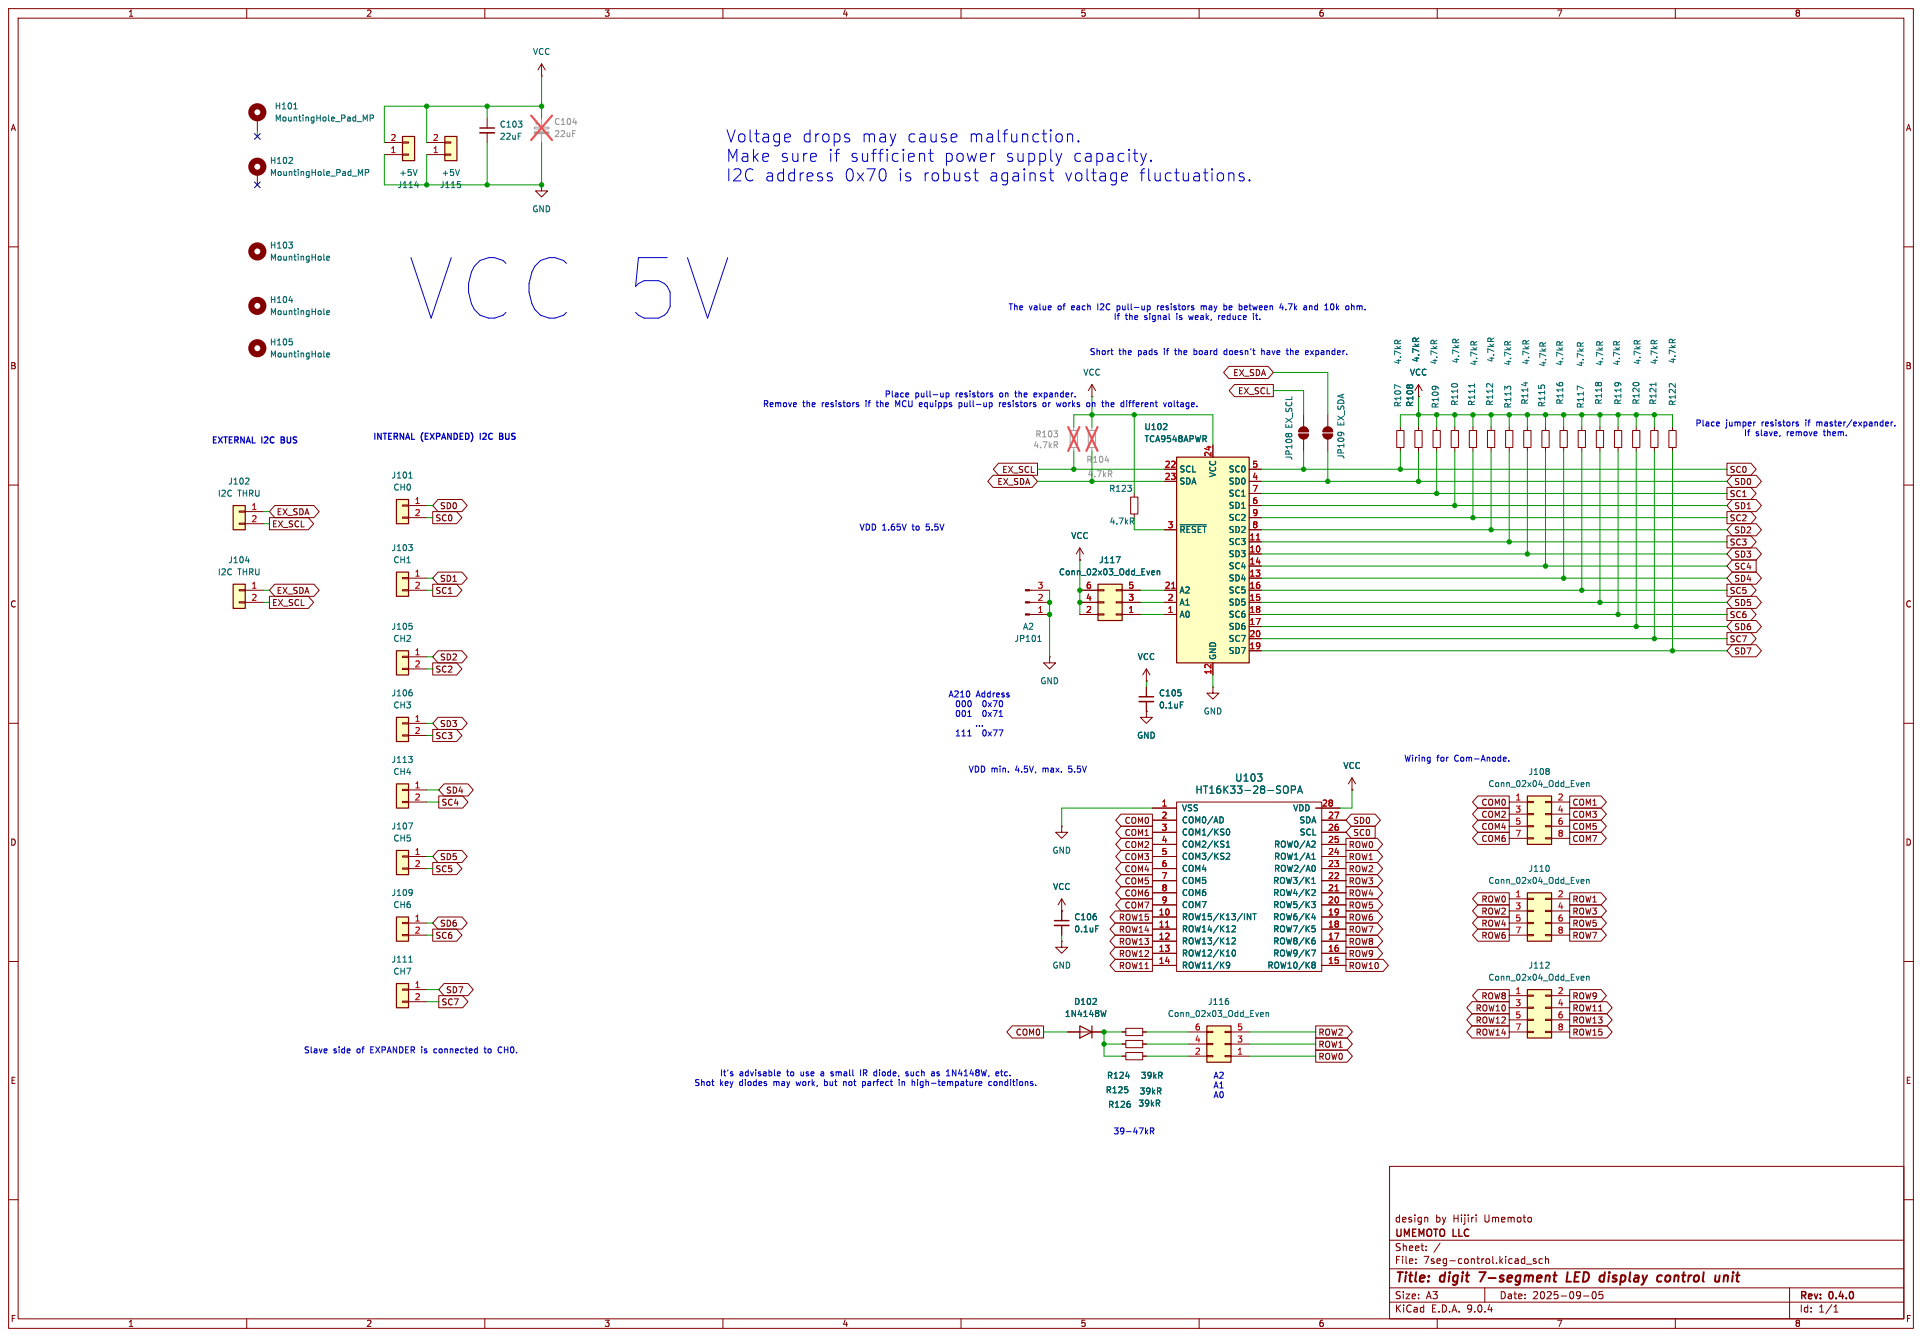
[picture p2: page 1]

INTERNAL (EXPANDED) I2C BUS VCC 5V

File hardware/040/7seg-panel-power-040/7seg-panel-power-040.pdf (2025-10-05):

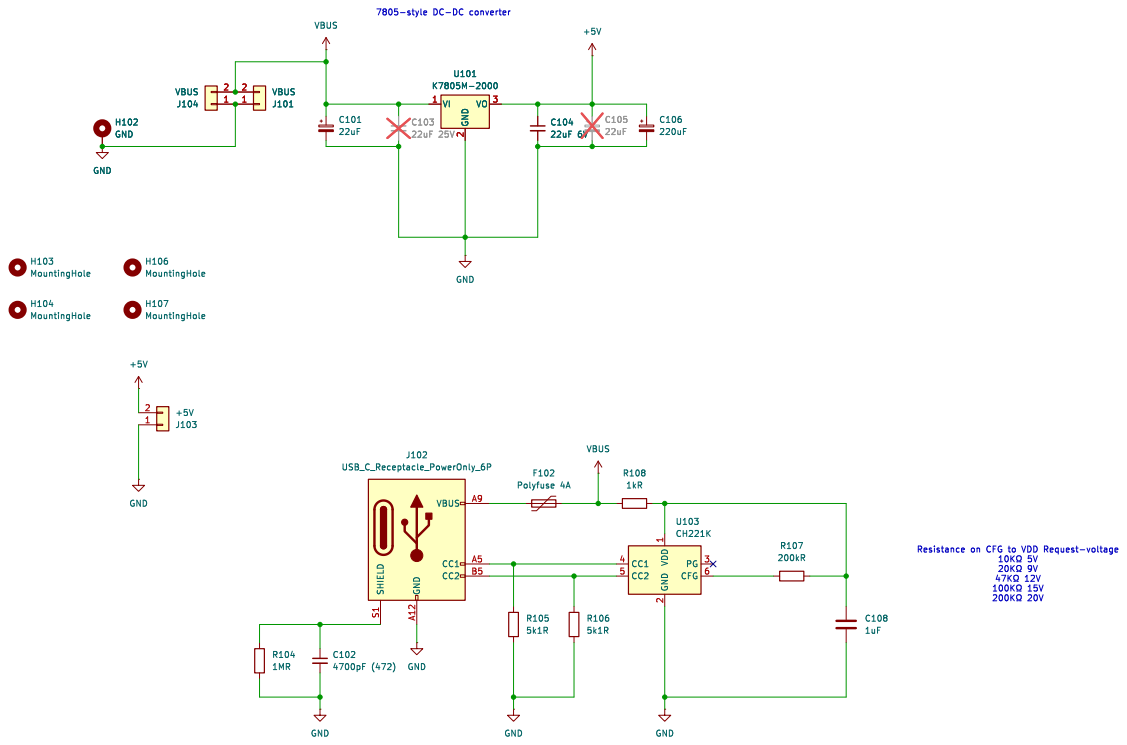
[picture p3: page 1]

2 VO 3 U101 K7805M-2000 Resistance on CFG to VDD Request-voltage

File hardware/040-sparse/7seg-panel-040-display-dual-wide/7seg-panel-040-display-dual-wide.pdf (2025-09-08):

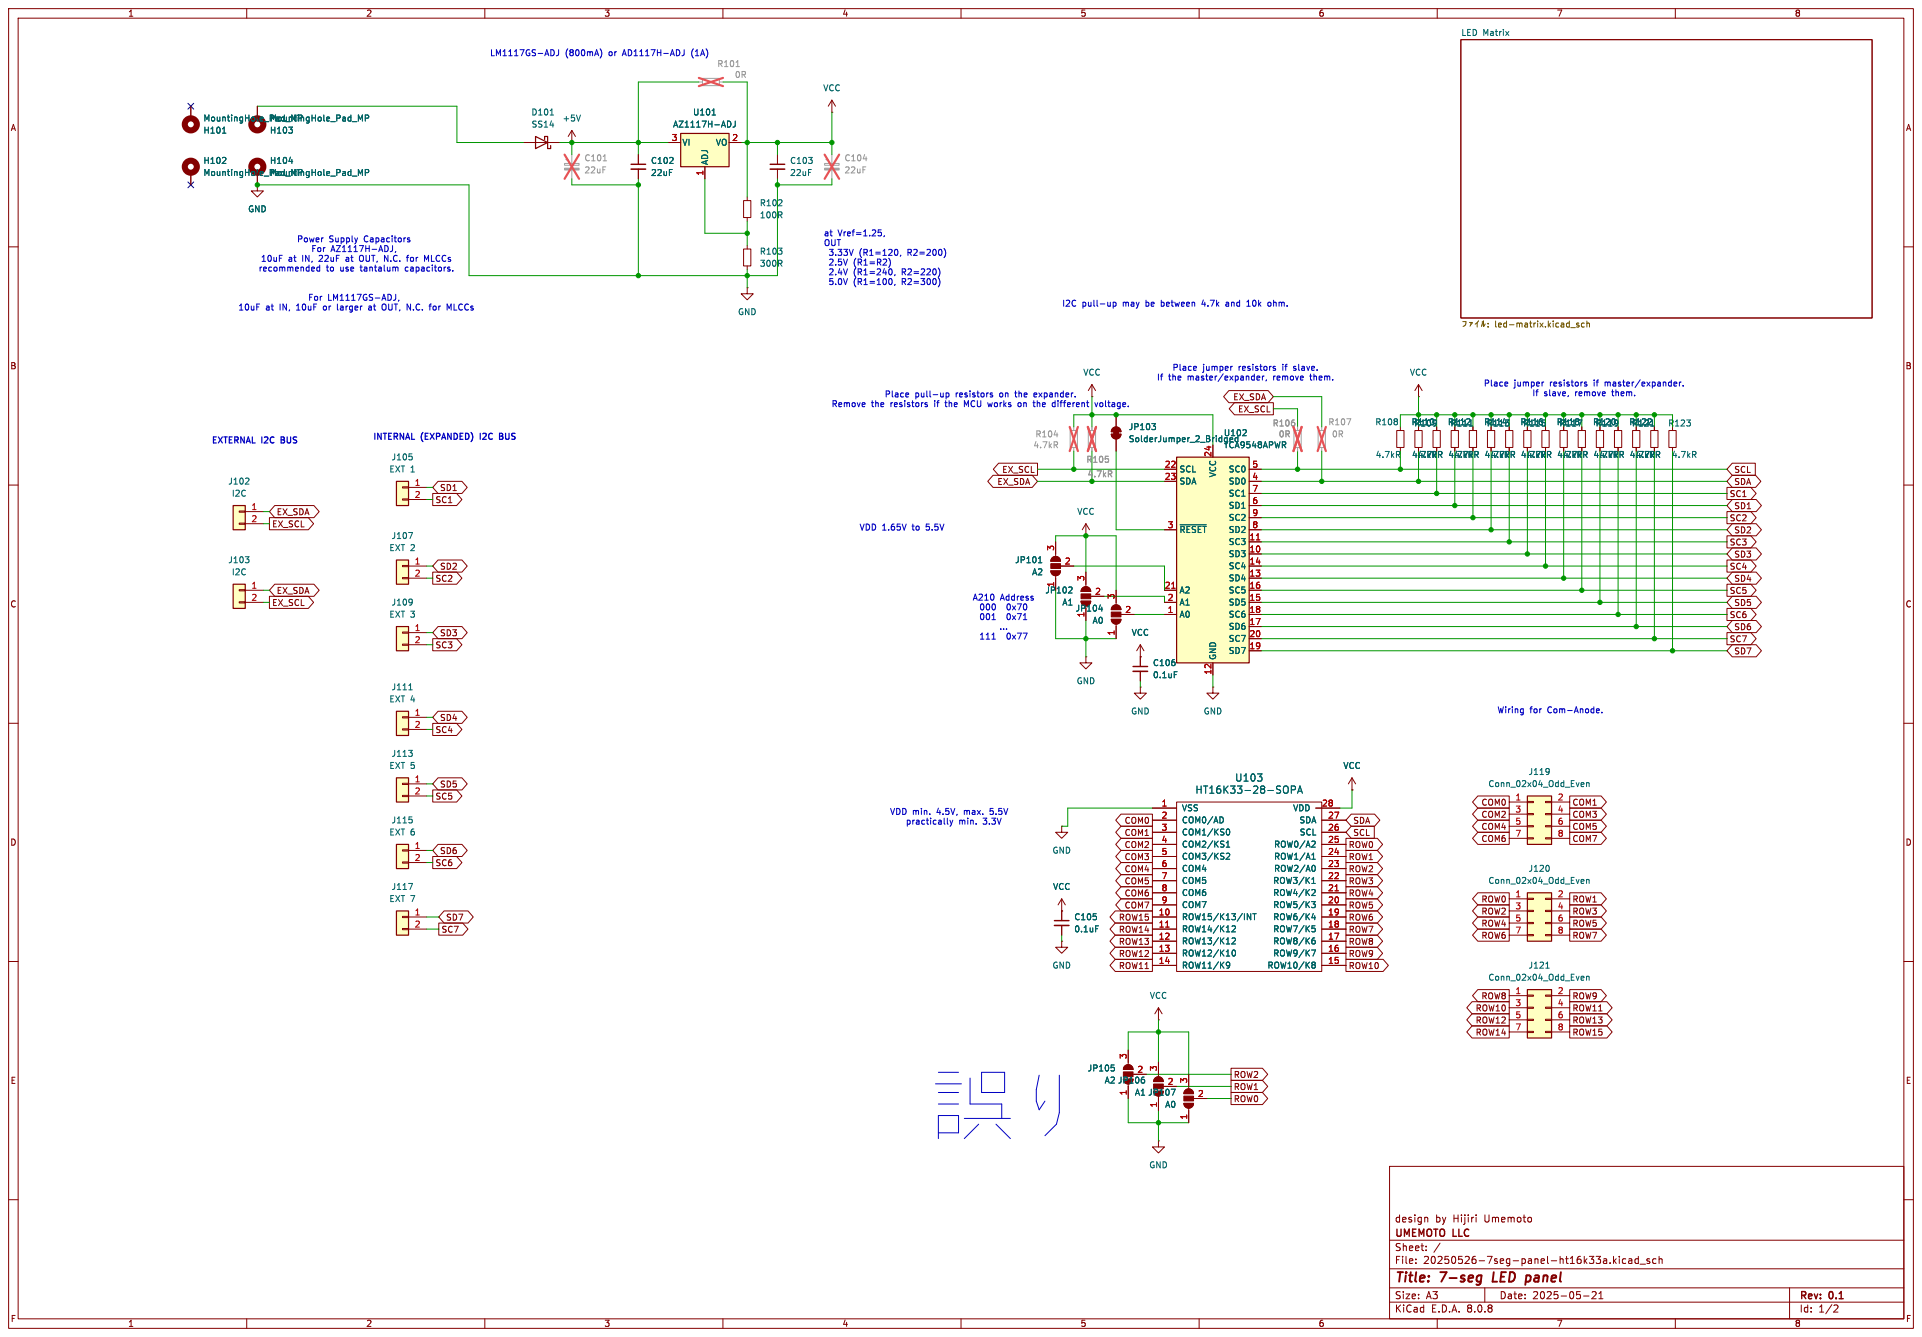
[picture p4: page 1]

LED Matrix þÿ0Õ0¡0¤0ë: led-matrix.kicad_sch VCC

Power Supply Capacitors For AZ1117H-ADJ, 10uF at IN, 22uF at OUT, N.C. for MLCCs

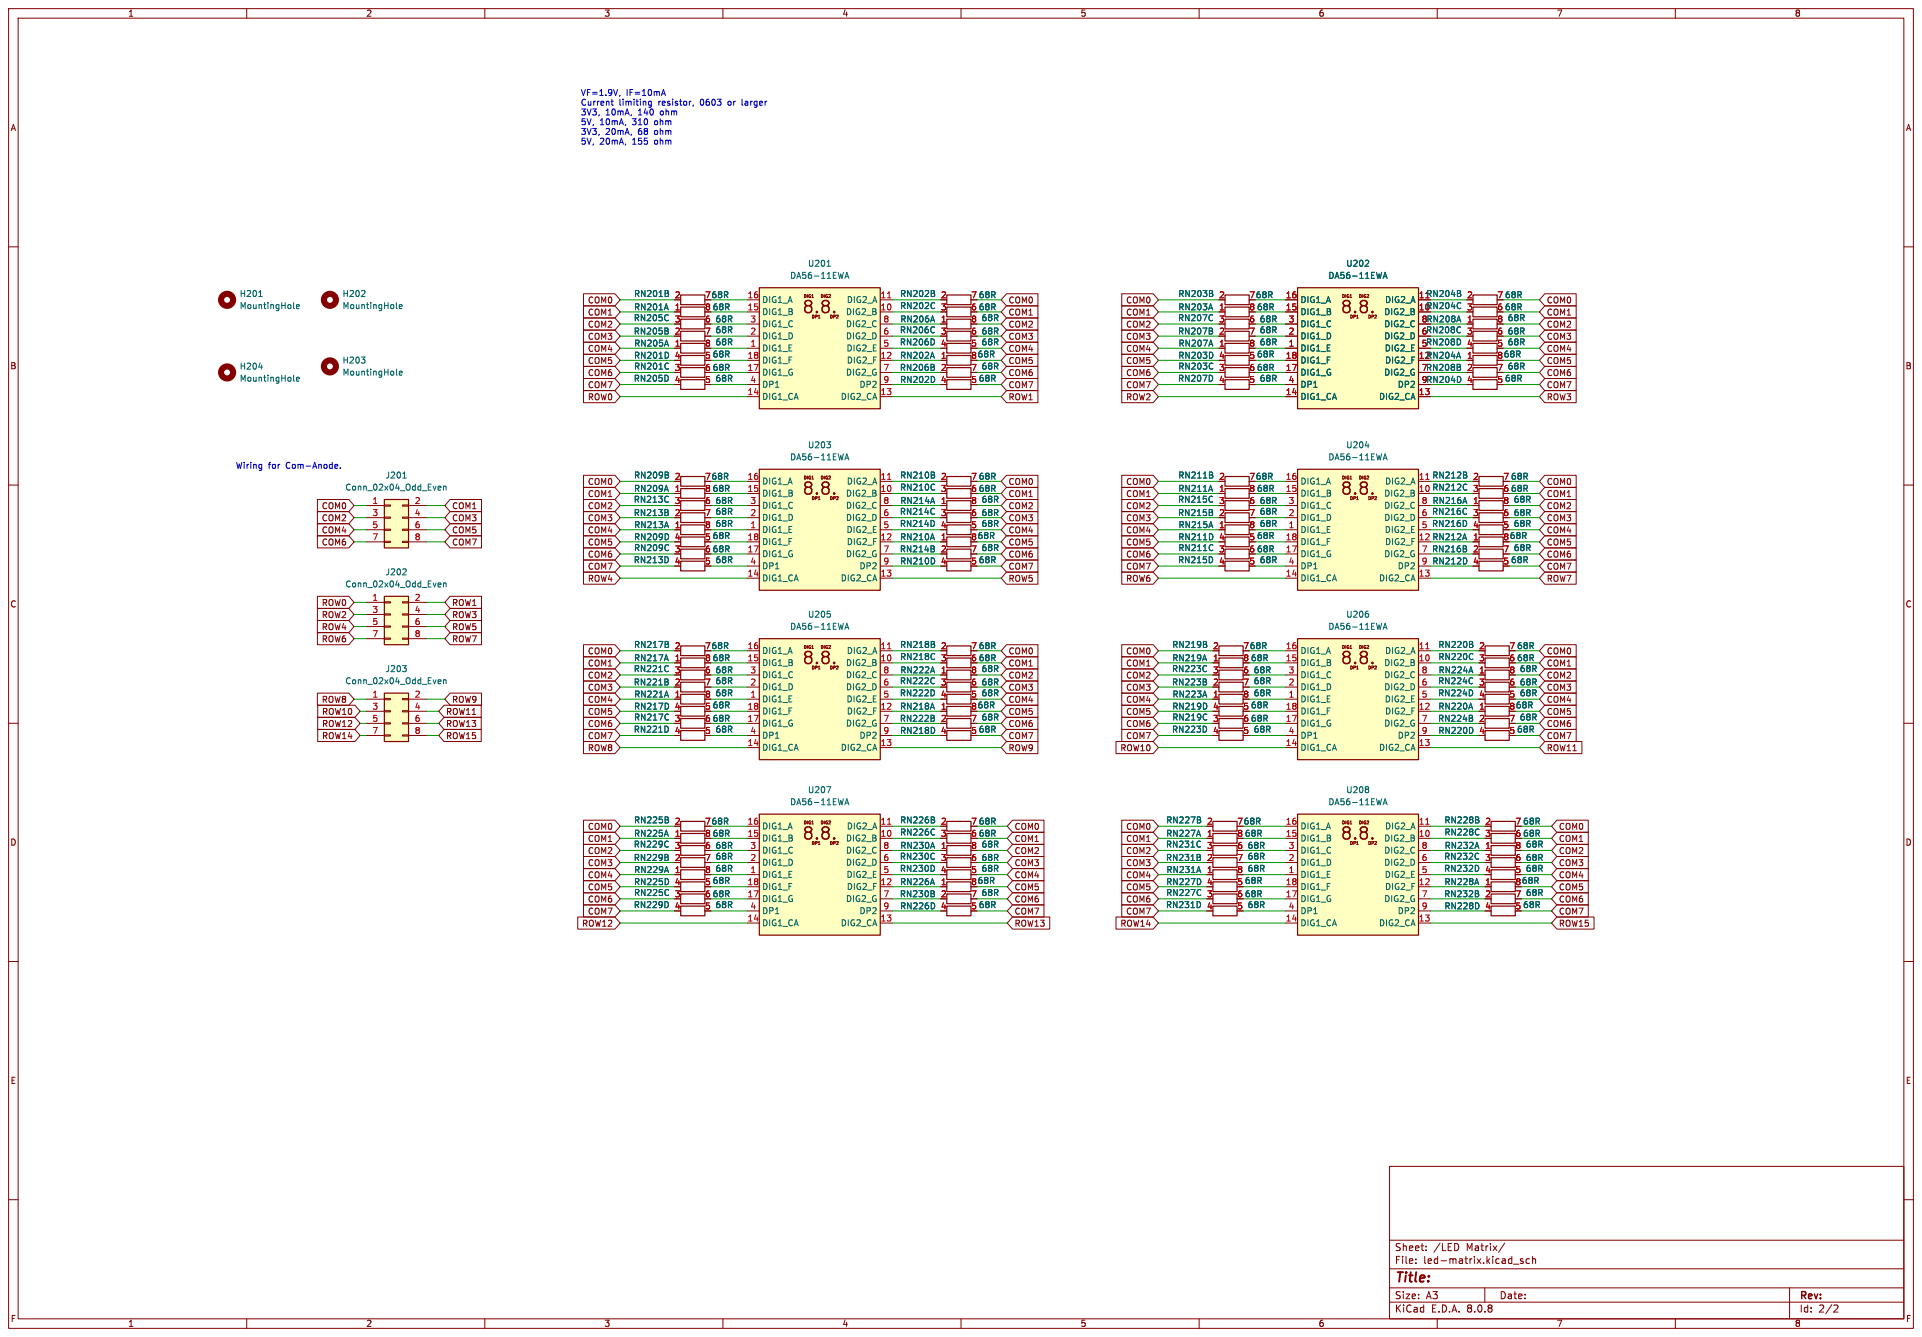
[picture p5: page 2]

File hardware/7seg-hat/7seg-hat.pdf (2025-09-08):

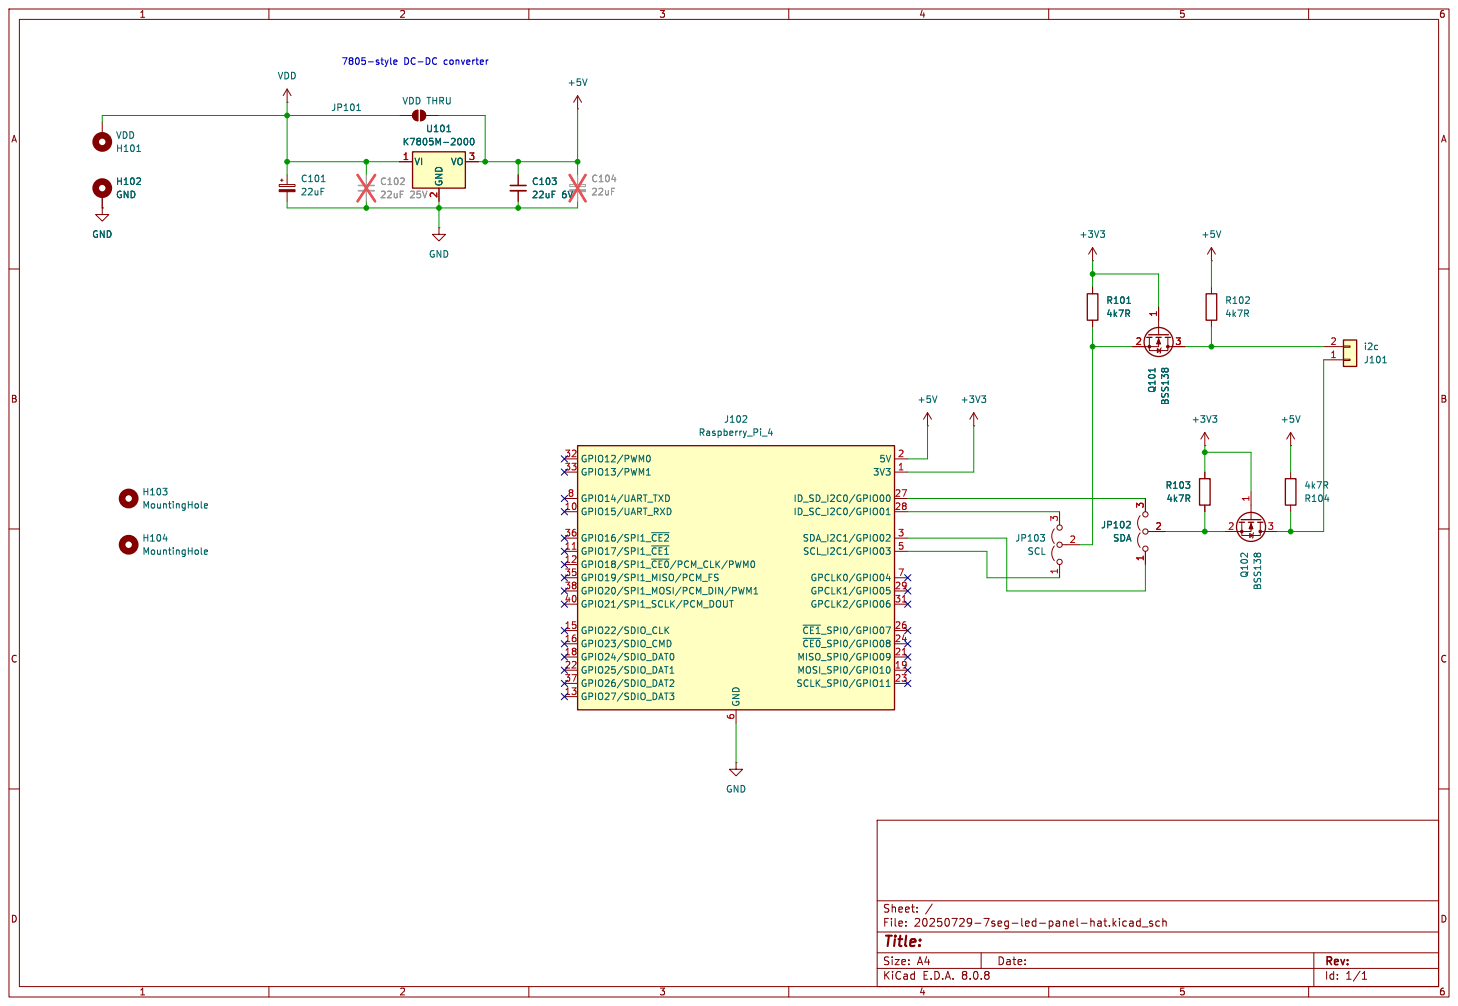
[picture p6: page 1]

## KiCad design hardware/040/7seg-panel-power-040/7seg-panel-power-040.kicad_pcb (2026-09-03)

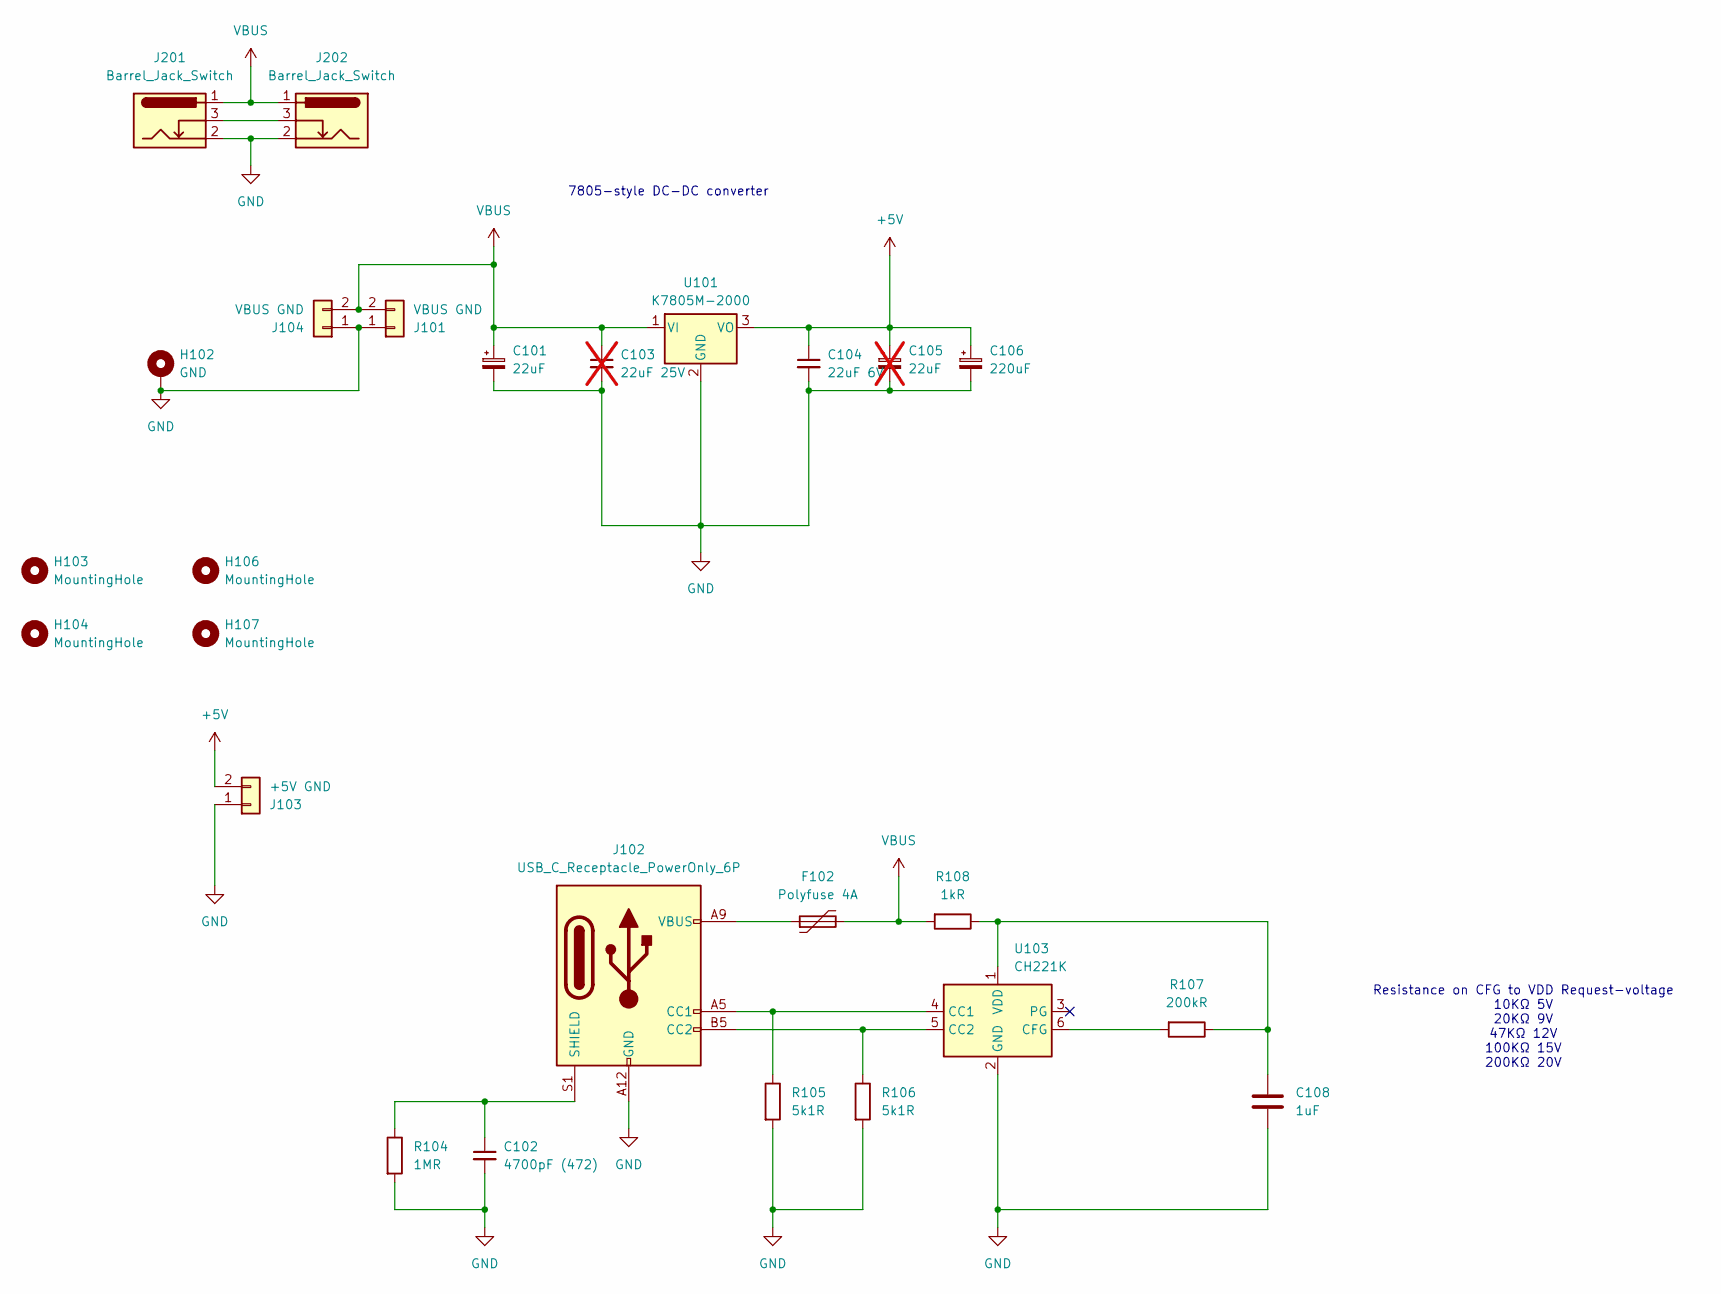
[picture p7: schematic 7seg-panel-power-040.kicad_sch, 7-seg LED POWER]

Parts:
C101: 22uF; CP_EIA-3528-21_Kemet-B
C102: 4700pF (472); C_0805_2012Metric_Pad1.18x1.45mm_HandSolder
C103: 22uF 25V; C_0603_1608Metric_Pad1.08x0.95mm_HandSolder; not fitted
C104: 22uF 6V; C_0603_1608Metric_Pad1.08x0.95mm_HandSolder
C105: 22uF; CP_EIA-3528-21_Kemet-B; not fitted
C106: 220uF; CP_Radial_D6.3mm_P2.50mm
C108: 1uF; C_0805_2012Metric_Pad1.18x1.45mm_HandSolder
F102: Polyfuse 4A; Fuse_2920_7451Metric_Pad2.10x5.45mm_HandSolder
H102: GND; MountingHole_3.2mm_M3_DIN965_Pad
H103, H104, H106, H107: MountingHole; MountingHole_3.2mm_M3
J101, J104: VBUS GND; Generic_XH_S2B-XH-A-1_1x02_P2.50mm_Horizontal
J102: USB_C_Receptacle_PowerOnly_6P; USB_C_Receptacle_HRO_TYPE-C-31-M-17
J103: +5V GND; Generic_XH_S2B-XH-A-1_1x02_P2.50mm_Horizontal
J201, J202: Barrel_Jack_Switch; BarrelJack_Singatron_2DC-0415D200-SMT_Horizontal
R104: 1MR; R_0805_2012Metric_Pad1.20x1.40mm_HandSolder
R105, R106: 5k1R; R_0805_2012Metric_Pad1.20x1.40mm_HandSolder
R107: 200kR; R_0805_2012Metric_Pad1.20x1.40mm_HandSolder
R108: 1kR; R_1210_3225Metric_Pad1.30x2.65mm_HandSolder
U101: K7805M-2000; TO-220-3_Vertical
U103: CH221K; TSOT-23-6_HandSoldering

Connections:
+5V: C104.1, C105.1, C106.1, J103.2, U101.3 (VO)
GND: C101.2, C102.2, C103.2, C104.2, C105.2, C106.2, C108.2, H102.1 (MP_1), J101.1, J102.A12 (GND), J102.B12 (GND), J103.1, J104.1, J201.2, J202.2, R104.2, R105.2, R106.2, U101.2 (GND), U103.2 (GND)
unnamed: F102.1, J102.A9 (VBUS), J102.B9 (VBUS)
unnamed: J102.A5 (CC1), R105.1, U103.4 (CC1)
unnamed: J102.B5 (CC2), R106.1, U103.5 (CC2)
unnamed: C102.1, J102.S1 (SHIELD), R104.1
unnamed: J201.3, J202.3
unnamed: R107.2, U103.6 (CFG)
unnamed: C108.1, R107.1, R108.1, U103.1 (VDD)
VBUS: C101.1, C103.1, F102.2, J101.2, J104.2, J201.1, J202.1, R108.2, U101.1 (VI)

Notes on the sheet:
7805-style DC-DC converter
Resistance on CFG to VDD Request-voltage 10KΩ 5V 20KΩ 9V 47KΩ 12V 100KΩ 15V 200KΩ 20V

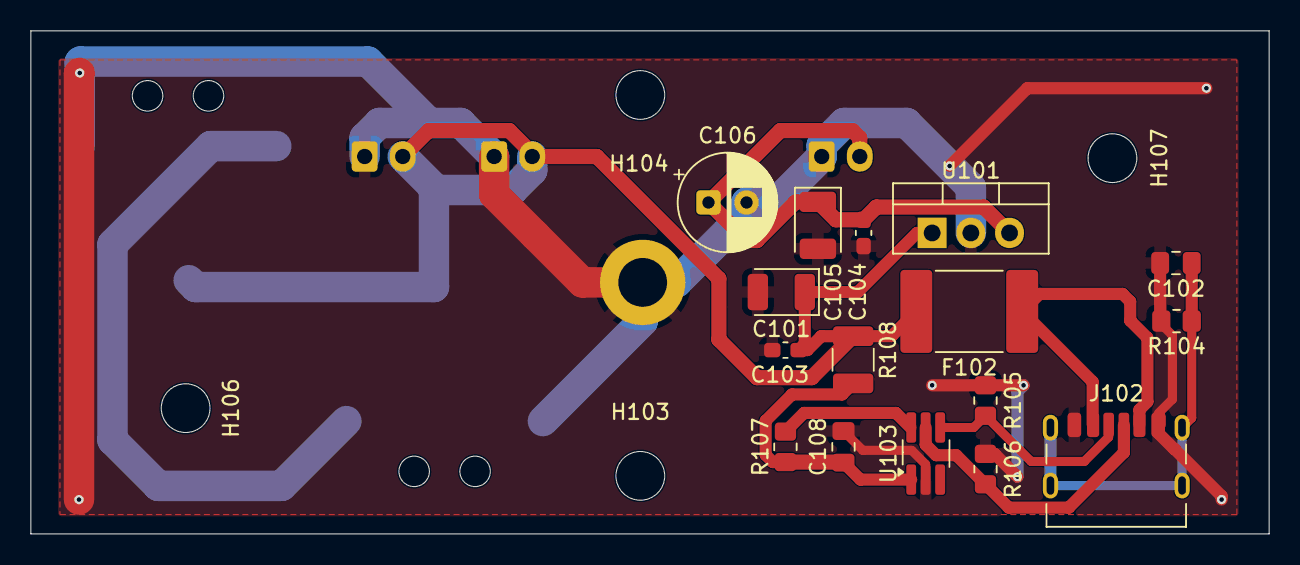
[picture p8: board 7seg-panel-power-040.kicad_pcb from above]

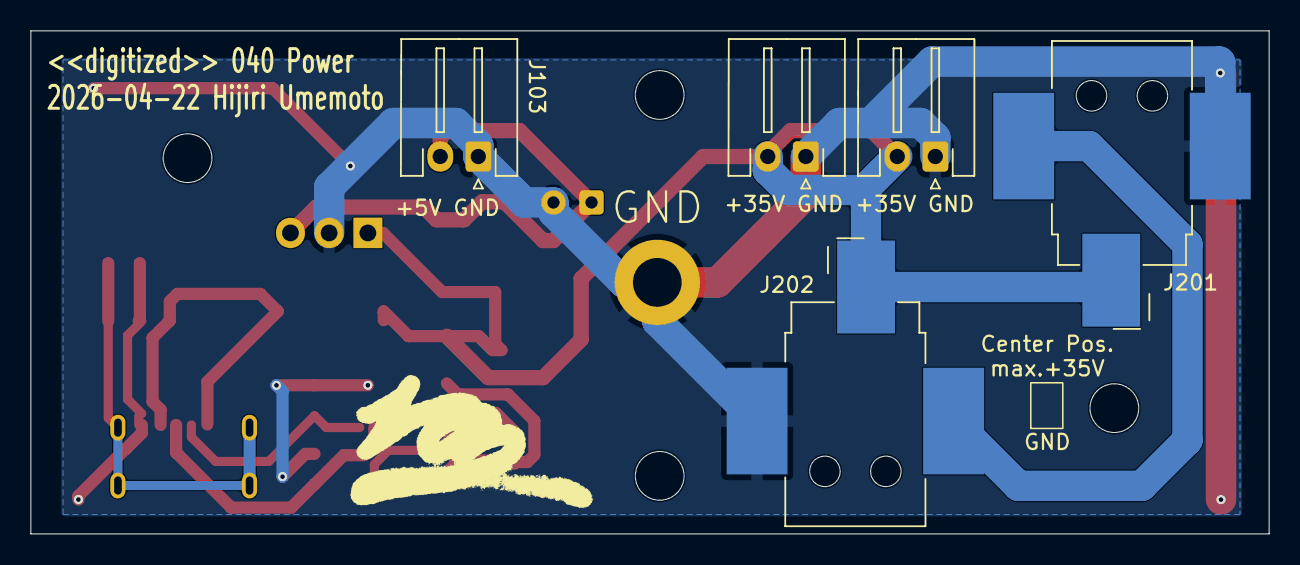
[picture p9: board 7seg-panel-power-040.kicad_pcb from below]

Board: 2 copper layers, 81.3 x 33.0 mm, 26 parts (5 on the bottom side), 10 nets.

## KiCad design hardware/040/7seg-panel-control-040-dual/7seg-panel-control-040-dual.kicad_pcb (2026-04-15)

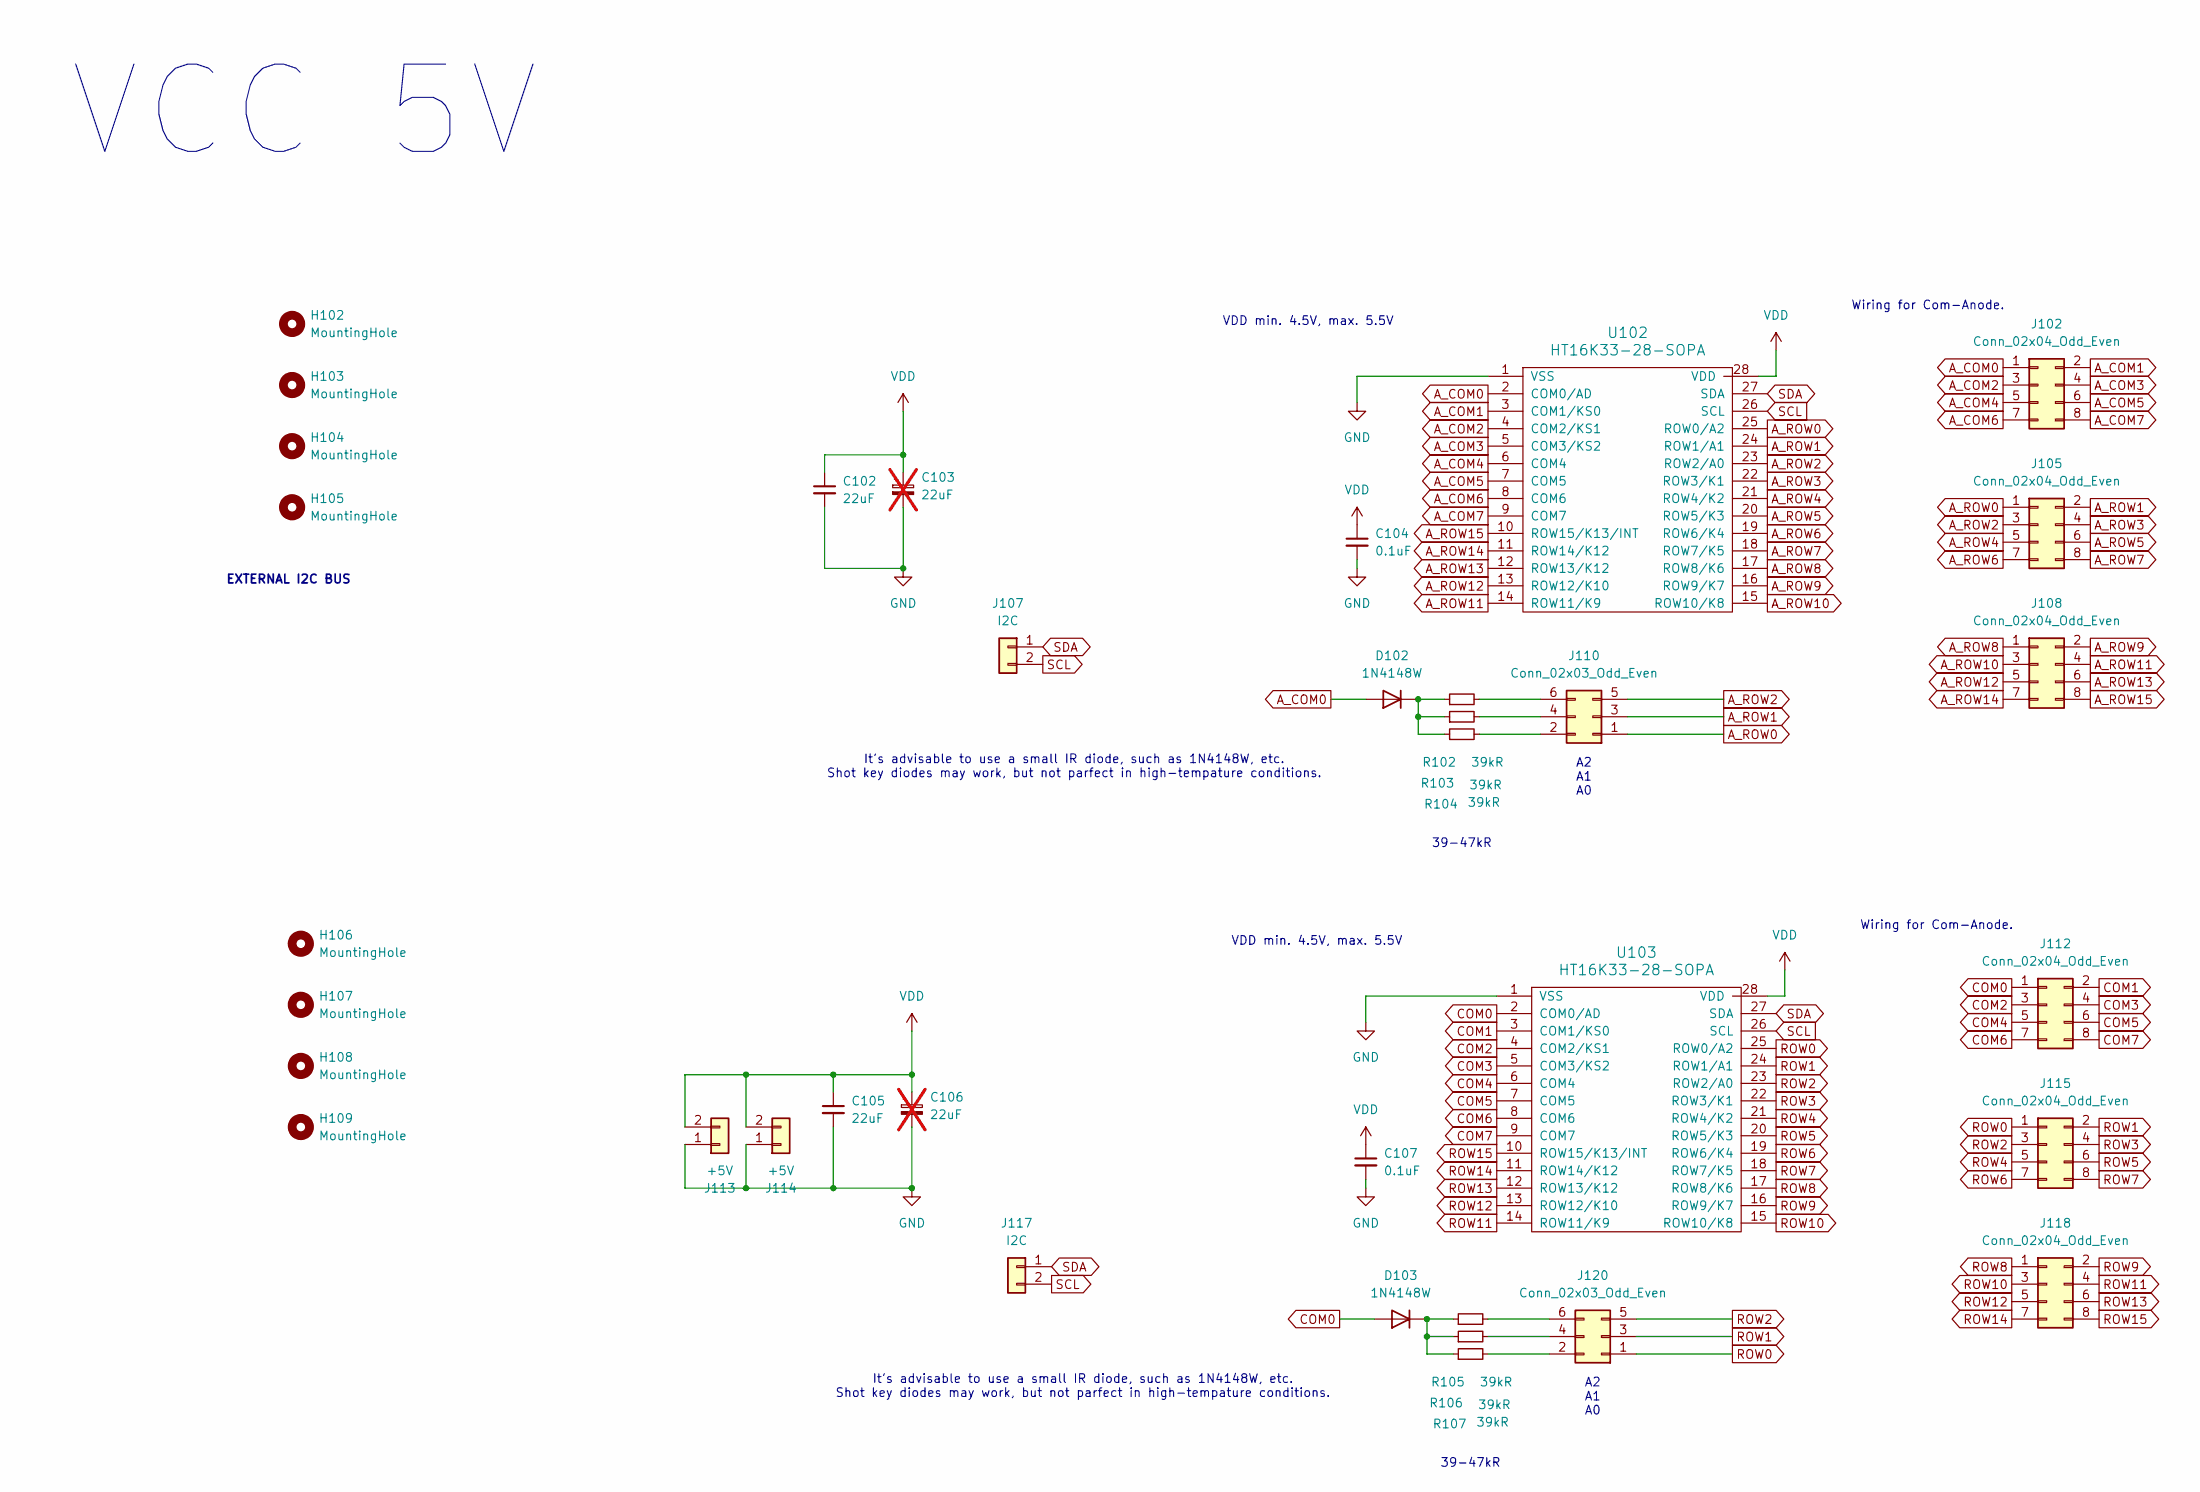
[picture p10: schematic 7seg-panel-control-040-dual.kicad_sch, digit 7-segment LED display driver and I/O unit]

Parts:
C102, C105: 22uF; C_0603_1608Metric
C103, C106: 22uF; CP_EIA-3528-21_Kemet-B_HandSolder; not fitted
C104, C107: 0.1uF; C_0603_1608Metric_Pad1.08x0.95mm_HandSolder
D102, D103: 1N4148W; D_SOD-123
H102, H103, H104, H105, H106, H107, H108, H109: MountingHole; MountingHole_3.2mm_M3
J102, J105, J108, J112, J115, J118: Conn_02x04_Odd_Even; PinSocket_2x04_P2.54mm_Vertical
J107, J117: I2C; Generic_XH_S2B-XH-A-1_1x02_P2.50mm_Horizontal
J110, J120: Conn_02x03_Odd_Even; PinHeader_2x03_P2.54mm_Vertical
J113, J114: +5V; Generic_XH_S2B-XH-A-1_1x02_P2.50mm_Horizontal
R102, R103, R104, R105, R106, R107: 39kR; R_0603_1608Metric_Pad0.98x0.95mm_HandSolder
U102, U103: HT16K33-28-SOPA; SOP-28_8.4x18.16mm_P1.27mm

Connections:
A_COM0: D102.2 (A), J102.1, U102.2 (COM0/AD)
A_COM1: J102.2, U102.3 (COM1/KS0)
A_COM2: J102.3, U102.4 (COM2/KS1)
A_COM3: J102.4, U102.5 (COM3/KS2)
A_COM4: J102.5, U102.6 (COM4)
A_COM5: J102.6, U102.7 (COM5)
A_COM6: J102.7, U102.8 (COM6)
A_COM7: J102.8, U102.9 (COM7)
A_ROW0: J105.1, J110.1, U102.25 (ROW0/A2)
A_ROW1: J105.2, J110.3, U102.24 (ROW1/A1)
A_ROW2: J105.3, J110.5, U102.23 (ROW2/A0)
A_ROW3: J105.4, U102.22 (ROW3/K1)
A_ROW4: J105.5, U102.21 (ROW4/K2)
A_ROW5: J105.6, U102.20 (ROW5/K3)
A_ROW6: J105.7, U102.19 (ROW6/K4)
A_ROW7: J105.8, U102.18 (ROW7/K5)
A_ROW8: J108.1, U102.17 (ROW8/K6)
A_ROW9: J108.2, U102.16 (ROW9/K7)
A_ROW10: J108.3, U102.15 (ROW10/K8)
A_ROW11: J108.4, U102.14 (ROW11/K9)
A_ROW12: J108.5, U102.13 (ROW12/K10)
A_ROW13: J108.6, U102.12 (ROW13/K12)
A_ROW14: J108.7, U102.11 (ROW14/K12)
A_ROW15: J108.8, U102.10 (ROW15/K13/INT)
COM0: D103.2 (A), J112.1, U103.2 (COM0/AD)
COM1: J112.2, U103.3 (COM1/KS0)
COM2: J112.3, U103.4 (COM2/KS1)
COM3: J112.4, U103.5 (COM3/KS2)
COM4: J112.5, U103.6 (COM4)
COM5: J112.6, U103.7 (COM5)
COM6: J112.7, U103.8 (COM6)
COM7: J112.8, U103.9 (COM7)
GND: C102.2, C103.2, C104.2, C105.2, C106.2, C107.2, J113.1, J114.1, U102.1 (VSS), U103.1 (VSS)
unnamed: D102.1 (K), R102.1, R103.1, R104.1
unnamed: D103.1 (K), R105.1, R106.1, R107.1
unnamed: J110.2, R104.2
unnamed: J110.4, R103.2
unnamed: J110.6, R102.2
unnamed: J120.2, R107.2
unnamed: J120.4, R106.2
unnamed: J120.6, R105.2
ROW0: J115.1, J120.1, U103.25 (ROW0/A2)
ROW1: J115.2, J120.3, U103.24 (ROW1/A1)
ROW2: J115.3, J120.5, U103.23 (ROW2/A0)
ROW3: J115.4, U103.22 (ROW3/K1)
ROW4: J115.5, U103.21 (ROW4/K2)
ROW5: J115.6, U103.20 (ROW5/K3)
ROW6: J115.7, U103.19 (ROW6/K4)
ROW7: J115.8, U103.18 (ROW7/K5)
ROW8: J118.1, U103.17 (ROW8/K6)
ROW9: J118.2, U103.16 (ROW9/K7)
ROW10: J118.3, U103.15 (ROW10/K8)
ROW11: J118.4, U103.14 (ROW11/K9)
ROW12: J118.5, U103.13 (ROW12/K10)
ROW13: J118.6, U103.12 (ROW13/K12)
ROW14: J118.7, U103.11 (ROW14/K12)
ROW15: J118.8, U103.10 (ROW15/K13/INT)
SCL: J107.2, J117.2, U102.26 (SCL), U103.26 (SCL)
SDA: J107.1, J117.1, U102.27 (SDA), U103.27 (SDA)
VDD: C102.1, C103.1, C104.1, C105.1, C106.1, C107.1, J113.2, J114.2, U102.28 (VDD), U103.28 (VDD)

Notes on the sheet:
VDD min. 4.5V, max. 5.5V
Wiring for Com-Anode.
39-47kR
It's advisable to use a small IR diode, such as 1N4148W, etc. Shot key diodes may work, but not parfect in high-tempature conditions.
A2 A1 A0
VCC 5V
EXTERNAL I2C BUS

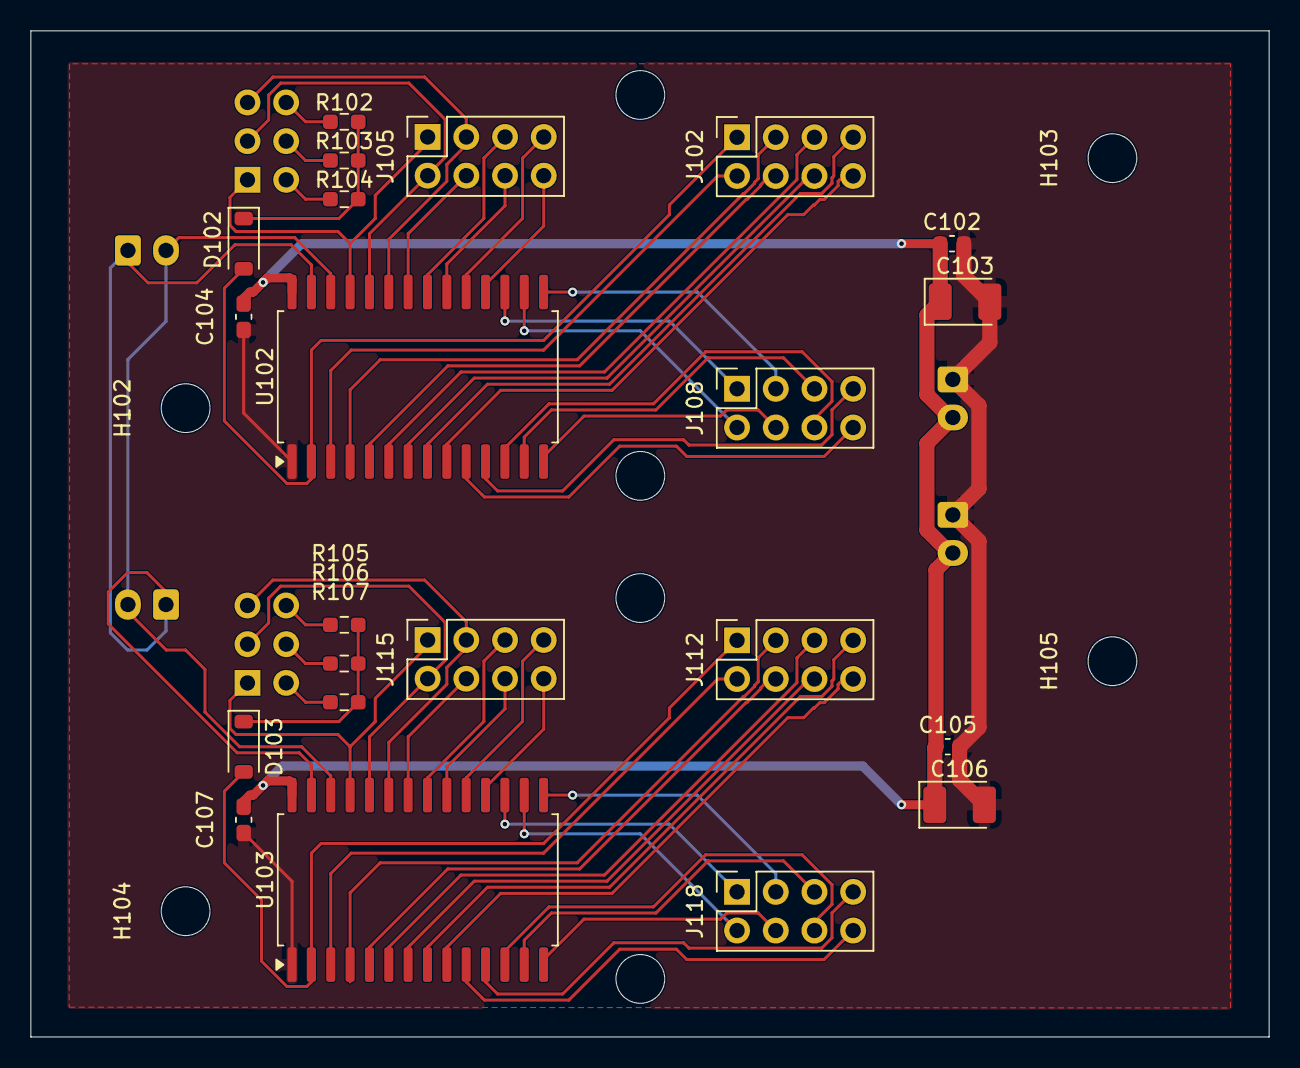
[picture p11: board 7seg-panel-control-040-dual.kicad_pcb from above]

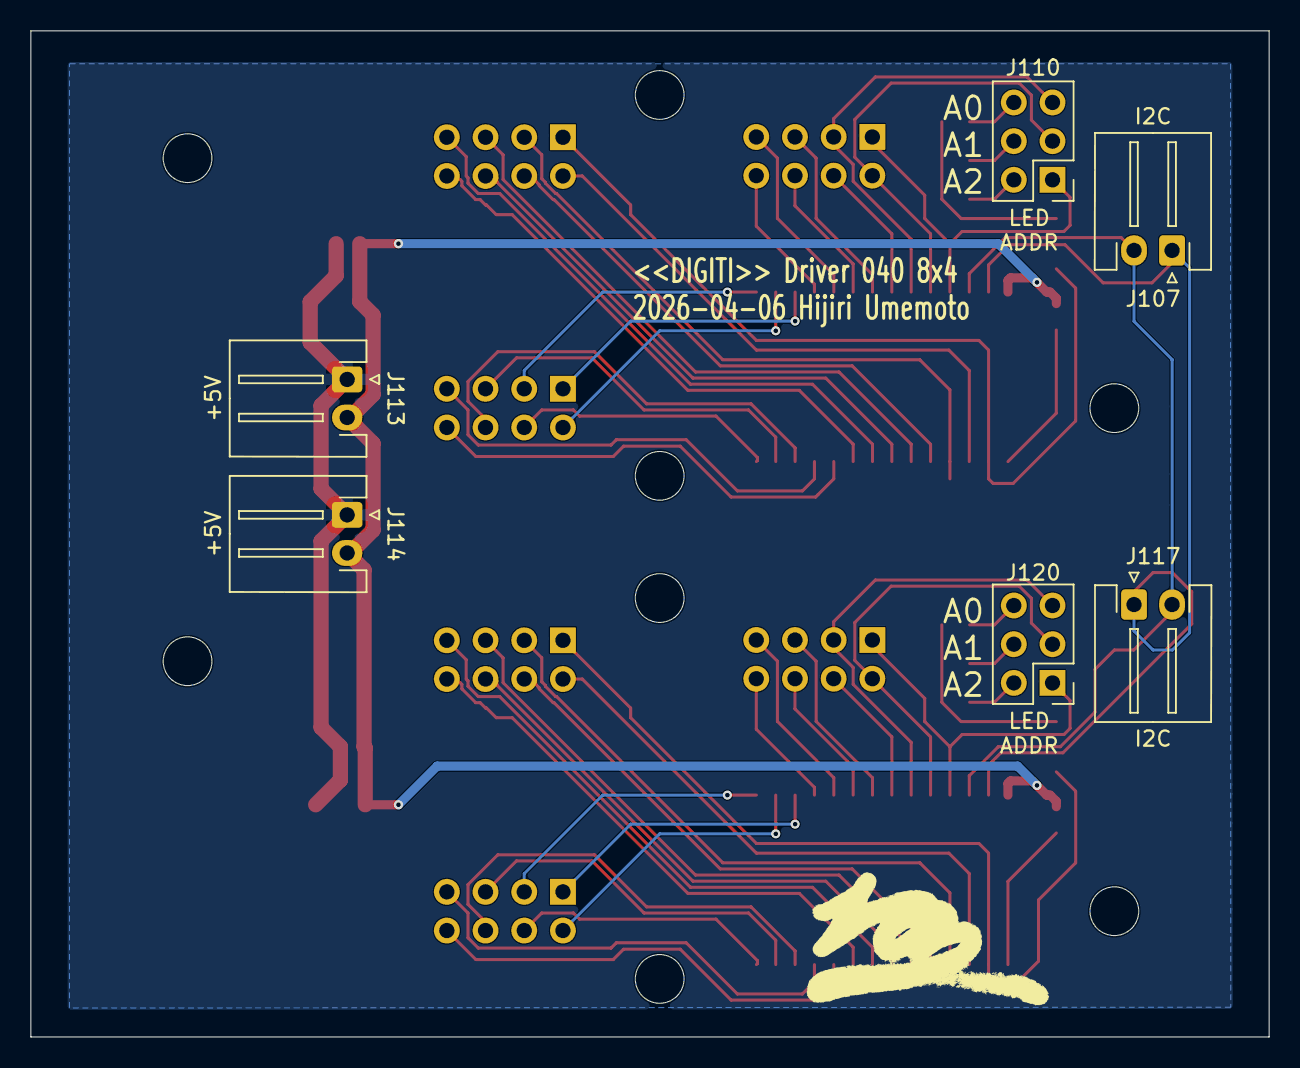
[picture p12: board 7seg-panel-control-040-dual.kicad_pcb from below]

Board: 2 copper layers, 81.3 x 66.0 mm, 36 parts (6 on the bottom side), 60 nets.

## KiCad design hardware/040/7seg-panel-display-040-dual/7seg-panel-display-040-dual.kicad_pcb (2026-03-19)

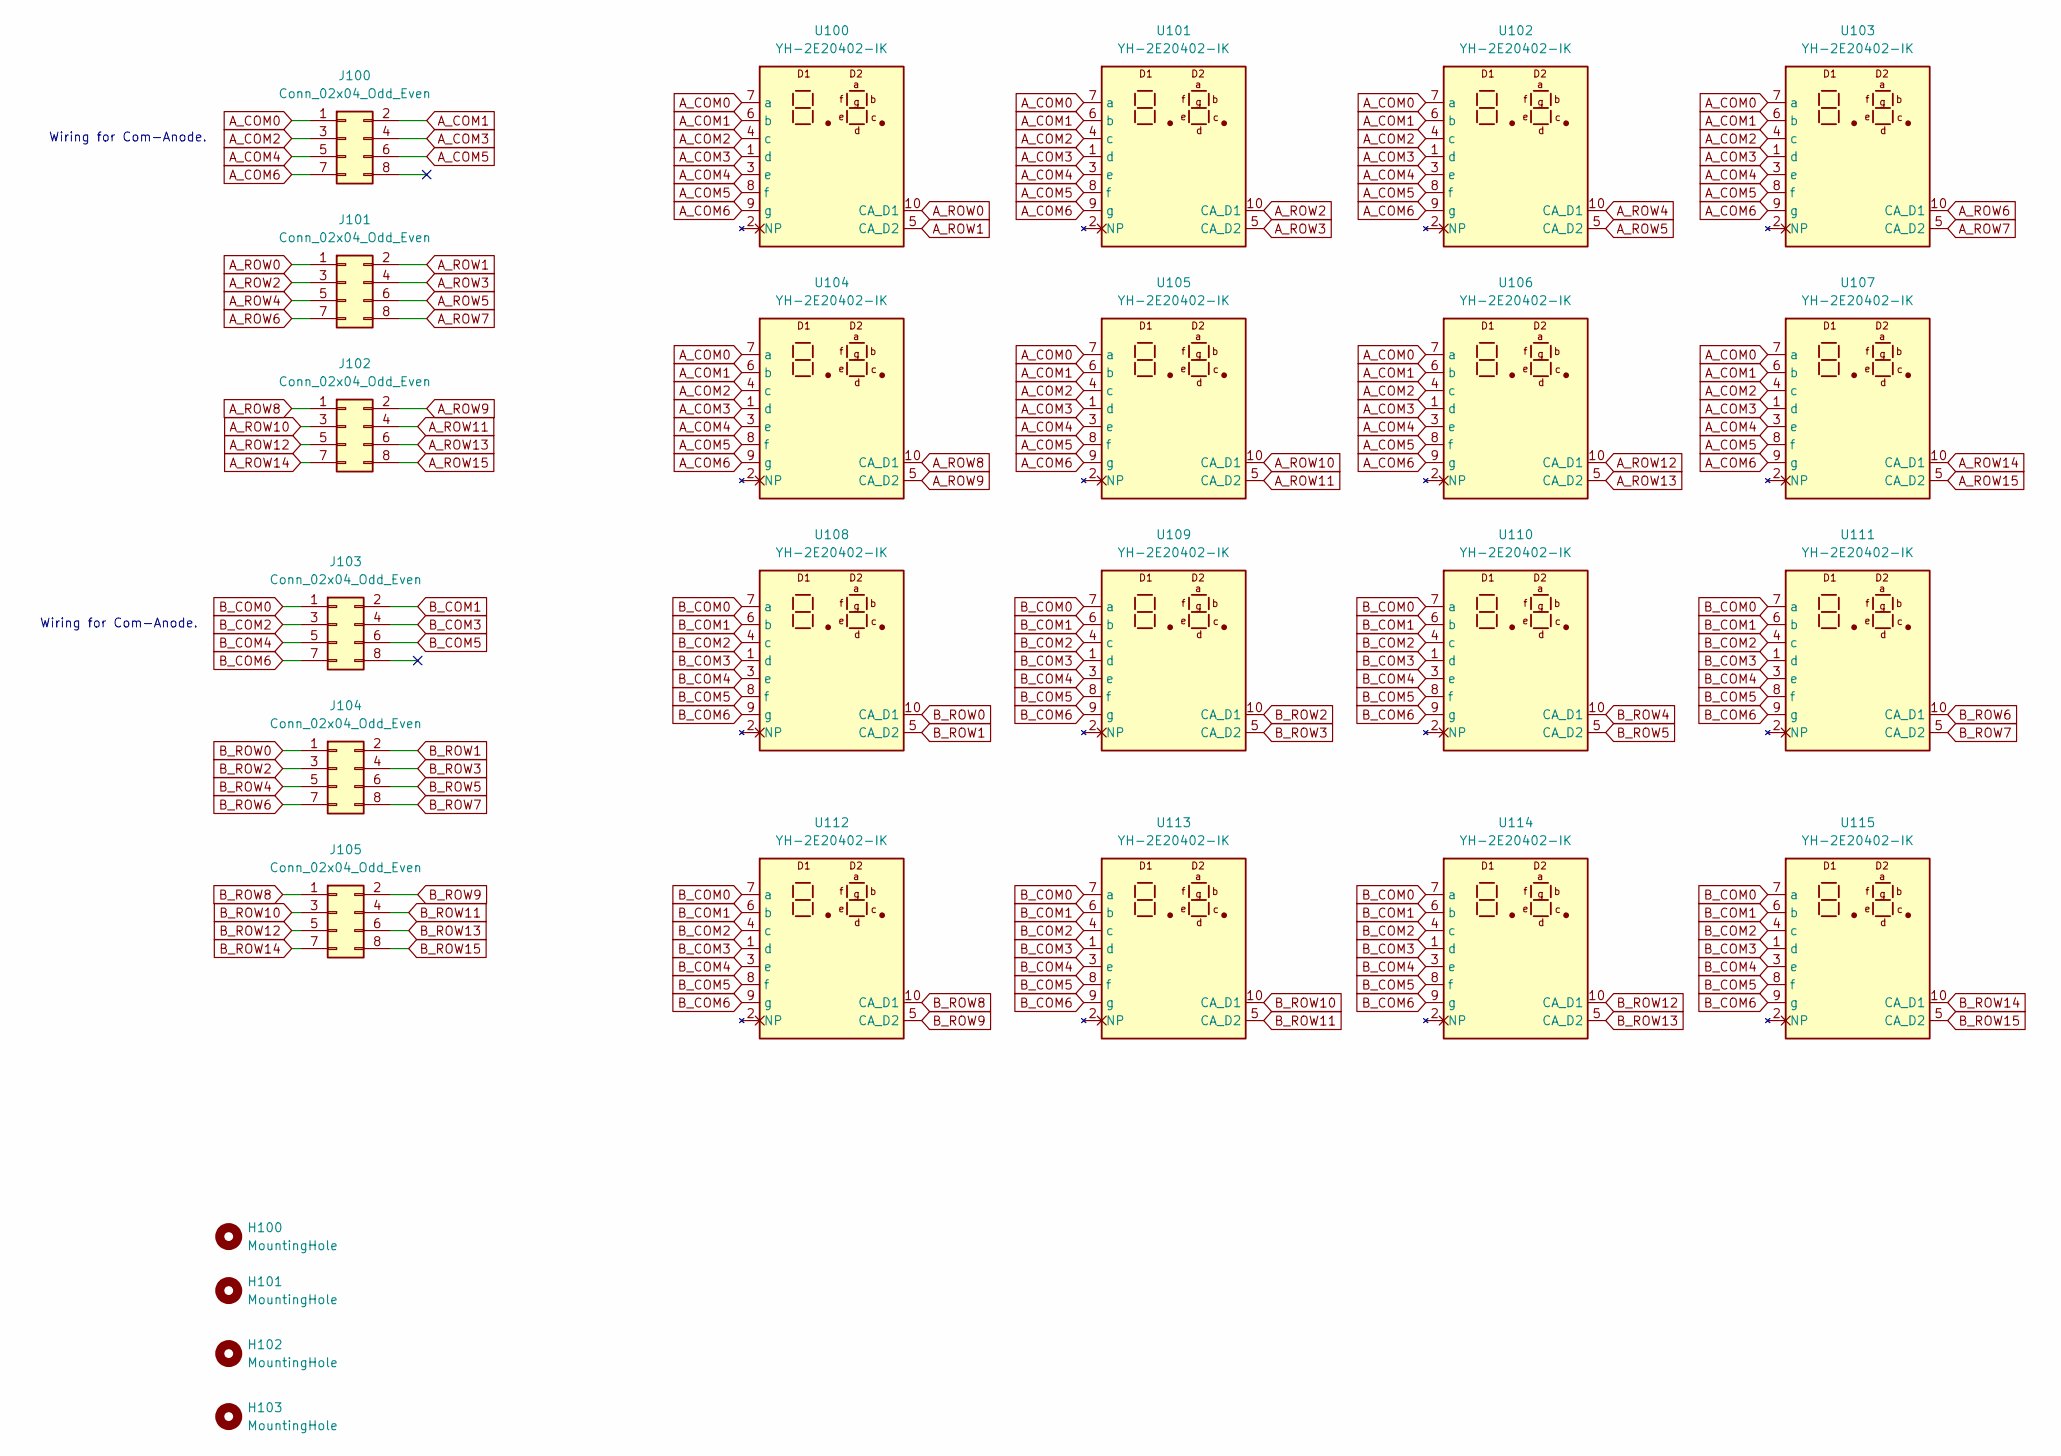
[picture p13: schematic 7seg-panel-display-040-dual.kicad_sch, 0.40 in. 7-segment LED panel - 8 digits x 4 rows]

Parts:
H100, H101, H102, H103: MountingHole; MountingHole_3.2mm_M3
J100, J101, J102, J103, J104, J105: Conn_02x04_Odd_Even; PinHeader_2x04_P2.54mm_Vertical
U100, U101, U102, U103, U104, U105, U106, U107, U108, U109, U110, U111, U112, U113, U114, U115: YH-2E20402-IK; YH-2E20402-12P

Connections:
A_COM0: J100.1, U100.7 (a), U101.7 (a), U102.7 (a), U103.7 (a), U104.7 (a), U105.7 (a), U106.7 (a), U107.7 (a)
A_COM1: J100.2, U100.6 (b), U101.6 (b), U102.6 (b), U103.6 (b), U104.6 (b), U105.6 (b), U106.6 (b), U107.6 (b)
A_COM2: J100.3, U100.4 (c), U101.4 (c), U102.4 (c), U103.4 (c), U104.4 (c), U105.4 (c), U106.4 (c), U107.4 (c)
A_COM3: J100.4, U100.1 (d), U101.1 (d), U102.1 (d), U103.1 (d), U104.1 (d), U105.1 (d), U106.1 (d), U107.1 (d)
A_COM4: J100.5, U100.3 (e), U101.3 (e), U102.3 (e), U103.3 (e), U104.3 (e), U105.3 (e), U106.3 (e), U107.3 (e)
A_COM5: J100.6, U100.8 (f), U101.8 (f), U102.8 (f), U103.8 (f), U104.8 (f), U105.8 (f), U106.8 (f), U107.8 (f)
A_COM6: J100.7, U100.9 (g), U101.9 (g), U102.9 (g), U103.9 (g), U104.9 (g), U105.9 (g), U106.9 (g), U107.9 (g)
A_ROW0: J101.1, U100.10 (CA_D1)
A_ROW1: J101.2, U100.5 (CA_D2)
A_ROW2: J101.3, U101.10 (CA_D1)
A_ROW3: J101.4, U101.5 (CA_D2)
A_ROW4: J101.5, U102.10 (CA_D1)
A_ROW5: J101.6, U102.5 (CA_D2)
A_ROW6: J101.7, U103.10 (CA_D1)
A_ROW7: J101.8, U103.5 (CA_D2)
A_ROW8: J102.1, U104.10 (CA_D1)
A_ROW9: J102.2, U104.5 (CA_D2)
A_ROW10: J102.3, U105.10 (CA_D1)
A_ROW11: J102.4, U105.5 (CA_D2)
A_ROW12: J102.5, U106.10 (CA_D1)
A_ROW13: J102.6, U106.5 (CA_D2)
A_ROW14: J102.7, U107.10 (CA_D1)
A_ROW15: J102.8, U107.5 (CA_D2)
B_COM0: J103.1, U108.7 (a), U109.7 (a), U110.7 (a), U111.7 (a), U112.7 (a), U113.7 (a), U114.7 (a), U115.7 (a)
B_COM1: J103.2, U108.6 (b), U109.6 (b), U110.6 (b), U111.6 (b), U112.6 (b), U113.6 (b), U114.6 (b), U115.6 (b)
B_COM2: J103.3, U108.4 (c), U109.4 (c), U110.4 (c), U111.4 (c), U112.4 (c), U113.4 (c), U114.4 (c), U115.4 (c)
B_COM3: J103.4, U108.1 (d), U109.1 (d), U110.1 (d), U111.1 (d), U112.1 (d), U113.1 (d), U114.1 (d), U115.1 (d)
B_COM4: J103.5, U108.3 (e), U109.3 (e), U110.3 (e), U111.3 (e), U112.3 (e), U113.3 (e), U114.3 (e), U115.3 (e)
B_COM5: J103.6, U108.8 (f), U109.8 (f), U110.8 (f), U111.8 (f), U112.8 (f), U113.8 (f), U114.8 (f), U115.8 (f)
B_COM6: J103.7, U108.9 (g), U109.9 (g), U110.9 (g), U111.9 (g), U112.9 (g), U113.9 (g), U114.9 (g), U115.9 (g)
B_ROW0: J104.1, U108.10 (CA_D1)
B_ROW1: J104.2, U108.5 (CA_D2)
B_ROW2: J104.3, U109.10 (CA_D1)
B_ROW3: J104.4, U109.5 (CA_D2)
B_ROW4: J104.5, U110.10 (CA_D1)
B_ROW5: J104.6, U110.5 (CA_D2)
B_ROW6: J104.7, U111.10 (CA_D1)
B_ROW7: J104.8, U111.5 (CA_D2)
B_ROW8: J105.1, U112.10 (CA_D1)
B_ROW9: J105.2, U112.5 (CA_D2)
B_ROW10: J105.3, U113.10 (CA_D1)
B_ROW11: J105.4, U113.5 (CA_D2)
B_ROW12: J105.5, U114.10 (CA_D1)
B_ROW13: J105.6, U114.5 (CA_D2)
B_ROW14: J105.7, U115.10 (CA_D1)
B_ROW15: J105.8, U115.5 (CA_D2)

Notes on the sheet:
Wiring for Com-Anode.

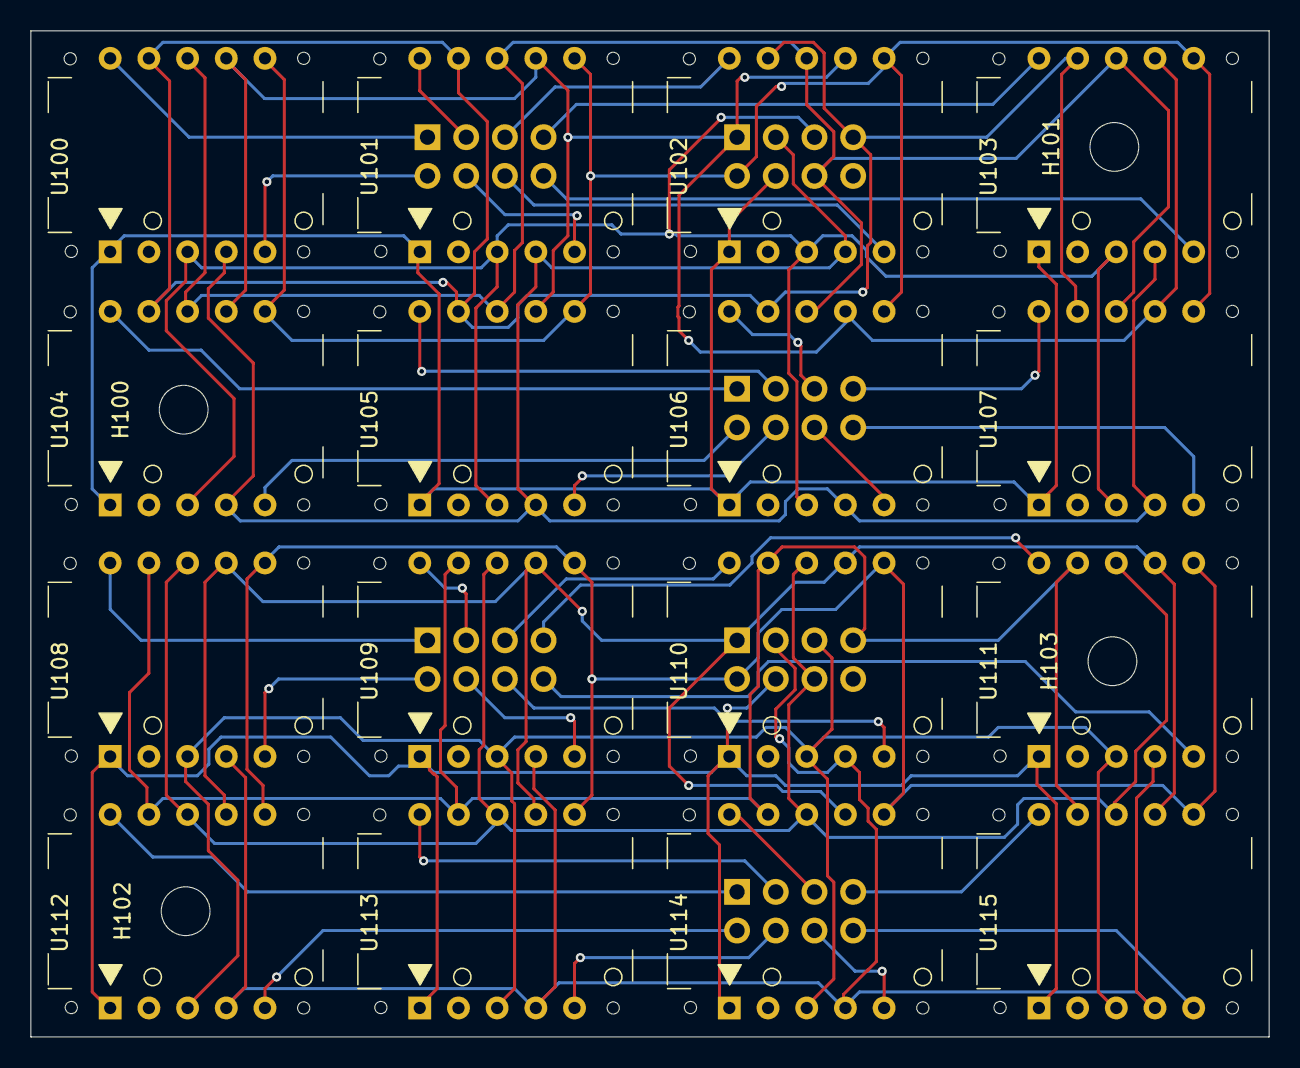
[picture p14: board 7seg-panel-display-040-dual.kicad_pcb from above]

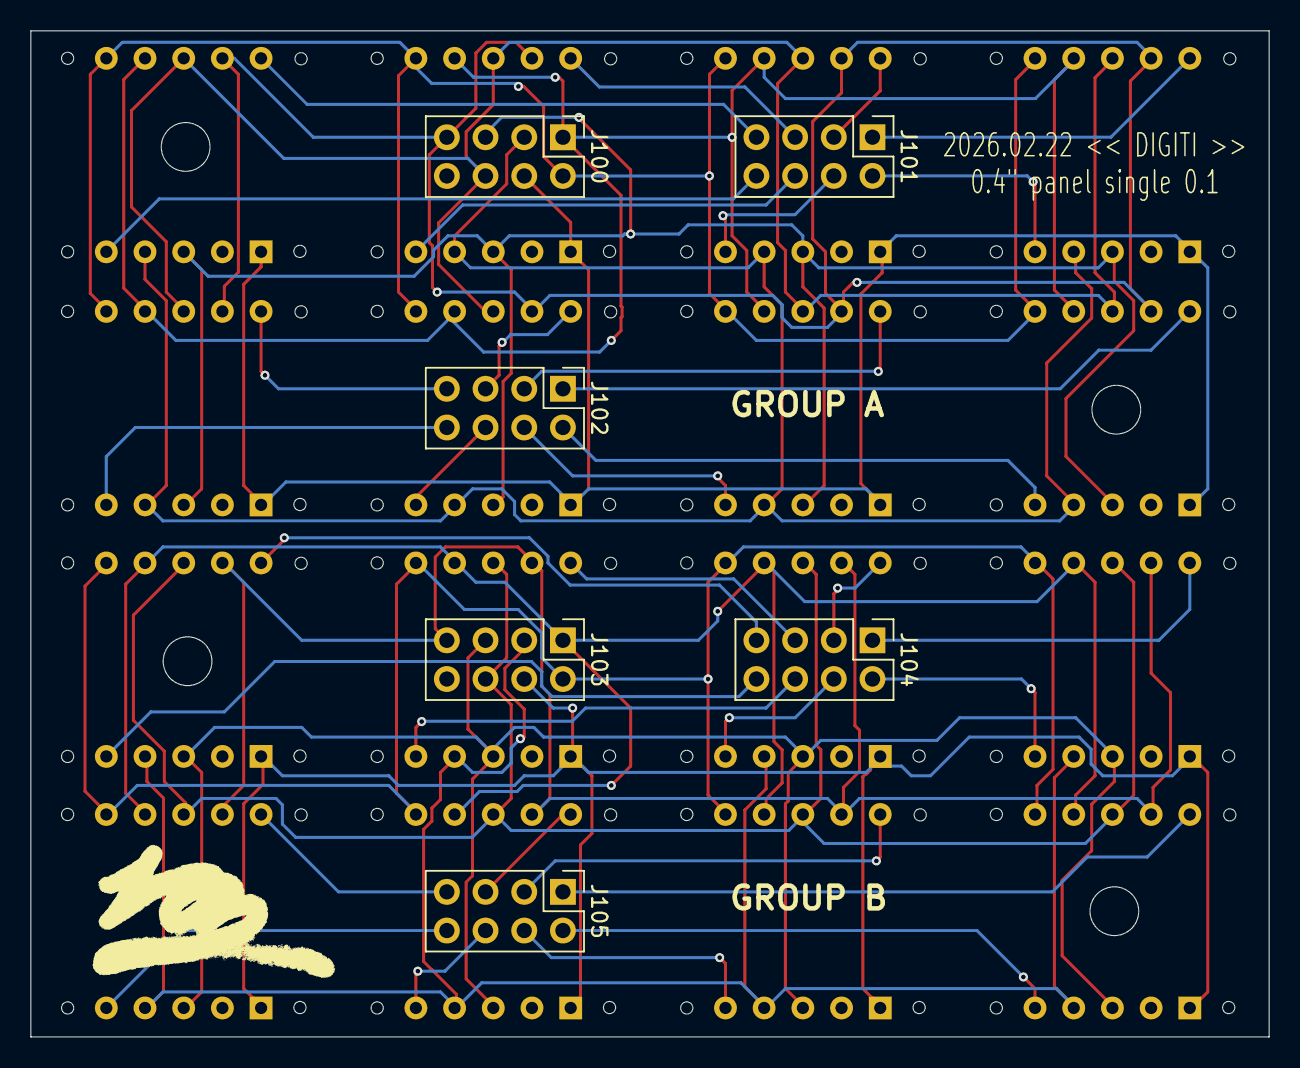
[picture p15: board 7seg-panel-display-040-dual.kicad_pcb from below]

Board: 2 copper layers, 81.3 x 66.0 mm, 26 parts (6 on the bottom side), 46 nets.

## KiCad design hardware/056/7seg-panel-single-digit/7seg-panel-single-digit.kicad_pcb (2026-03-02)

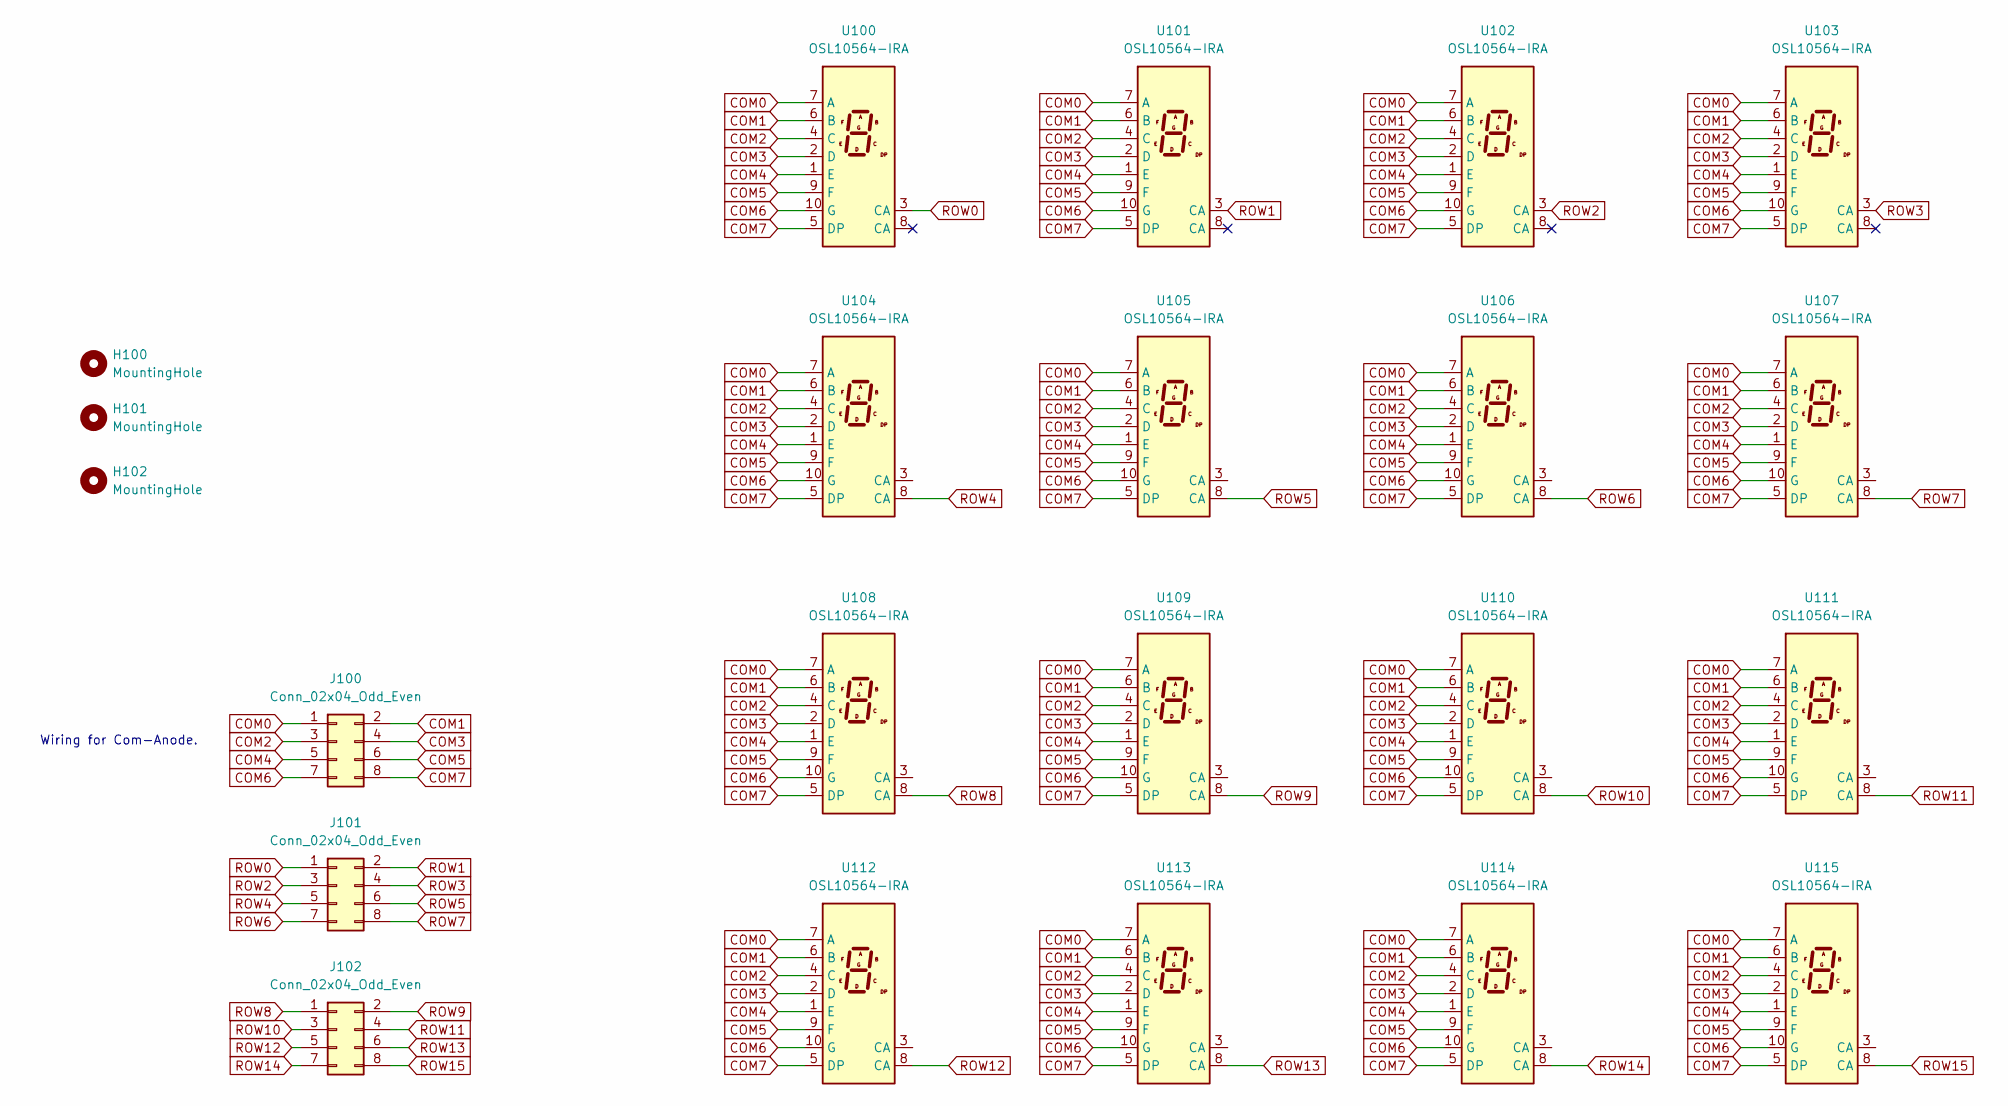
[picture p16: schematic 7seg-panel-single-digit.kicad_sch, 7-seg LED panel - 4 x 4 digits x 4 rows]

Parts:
H100, H101, H102: MountingHole; MountingHole_3.2mm_M3
J100, J101, J102: Conn_02x04_Odd_Even; PinHeader_2x04_P2.54mm_Vertical
U100, U101, U102, U103, U104, U105, U106, U107, U108, U109, U110, U111, U112, U113, U114, U115: OSL10564-IRA; 7SegmentLED_OSL10564

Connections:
COM0: J100.1, U100.7 (A), U101.7 (A), U102.7 (A), U103.7 (A), U104.7 (A), U105.7 (A), U106.7 (A), U107.7 (A), U108.7 (A), U109.7 (A), U110.7 (A), U111.7 (A), U112.7 (A), U113.7 (A), U114.7 (A), U115.7 (A)
COM1: J100.2, U100.6 (B), U101.6 (B), U102.6 (B), U103.6 (B), U104.6 (B), U105.6 (B), U106.6 (B), U107.6 (B), U108.6 (B), U109.6 (B), U110.6 (B), U111.6 (B), U112.6 (B), U113.6 (B), U114.6 (B), U115.6 (B)
COM2: J100.3, U100.4 (C), U101.4 (C), U102.4 (C), U103.4 (C), U104.4 (C), U105.4 (C), U106.4 (C), U107.4 (C), U108.4 (C), U109.4 (C), U110.4 (C), U111.4 (C), U112.4 (C), U113.4 (C), U114.4 (C), U115.4 (C)
COM3: J100.4, U100.2 (D), U101.2 (D), U102.2 (D), U103.2 (D), U104.2 (D), U105.2 (D), U106.2 (D), U107.2 (D), U108.2 (D), U109.2 (D), U110.2 (D), U111.2 (D), U112.2 (D), U113.2 (D), U114.2 (D), U115.2 (D)
COM4: J100.5, U100.1 (E), U101.1 (E), U102.1 (E), U103.1 (E), U104.1 (E), U105.1 (E), U106.1 (E), U107.1 (E), U108.1 (E), U109.1 (E), U110.1 (E), U111.1 (E), U112.1 (E), U113.1 (E), U114.1 (E), U115.1 (E)
COM5: J100.6, U100.9 (F), U101.9 (F), U102.9 (F), U103.9 (F), U104.9 (F), U105.9 (F), U106.9 (F), U107.9 (F), U108.9 (F), U109.9 (F), U110.9 (F), U111.9 (F), U112.9 (F), U113.9 (F), U114.9 (F), U115.9 (F)
COM6: J100.7, U100.10 (G), U101.10 (G), U102.10 (G), U103.10 (G), U104.10 (G), U105.10 (G), U106.10 (G), U107.10 (G), U108.10 (G), U109.10 (G), U110.10 (G), U111.10 (G), U112.10 (G), U113.10 (G), U114.10 (G), U115.10 (G)
COM7: J100.8, U100.5 (DP), U101.5 (DP), U102.5 (DP), U103.5 (DP), U104.5 (DP), U105.5 (DP), U106.5 (DP), U107.5 (DP), U108.5 (DP), U109.5 (DP), U110.5 (DP), U111.5 (DP), U112.5 (DP), U113.5 (DP), U114.5 (DP), U115.5 (DP)
ROW0: J101.1, U100.3 (CA)
ROW1: J101.2, U101.3 (CA)
ROW2: J101.3, U102.3 (CA)
ROW3: J101.4, U103.3 (CA)
ROW4: J101.5, U104.8 (CA)
ROW5: J101.6, U105.8 (CA)
ROW6: J101.7, U106.8 (CA)
ROW7: J101.8, U107.8 (CA)
ROW8: J102.1, U108.8 (CA)
ROW9: J102.2, U109.8 (CA)
ROW10: J102.3, U110.8 (CA)
ROW11: J102.4, U111.8 (CA)
ROW12: J102.5, U112.8 (CA)
ROW13: J102.6, U113.8 (CA)
ROW14: J102.7, U114.8 (CA)
ROW15: J102.8, U115.8 (CA)

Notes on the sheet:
Wiring for Com-Anode.

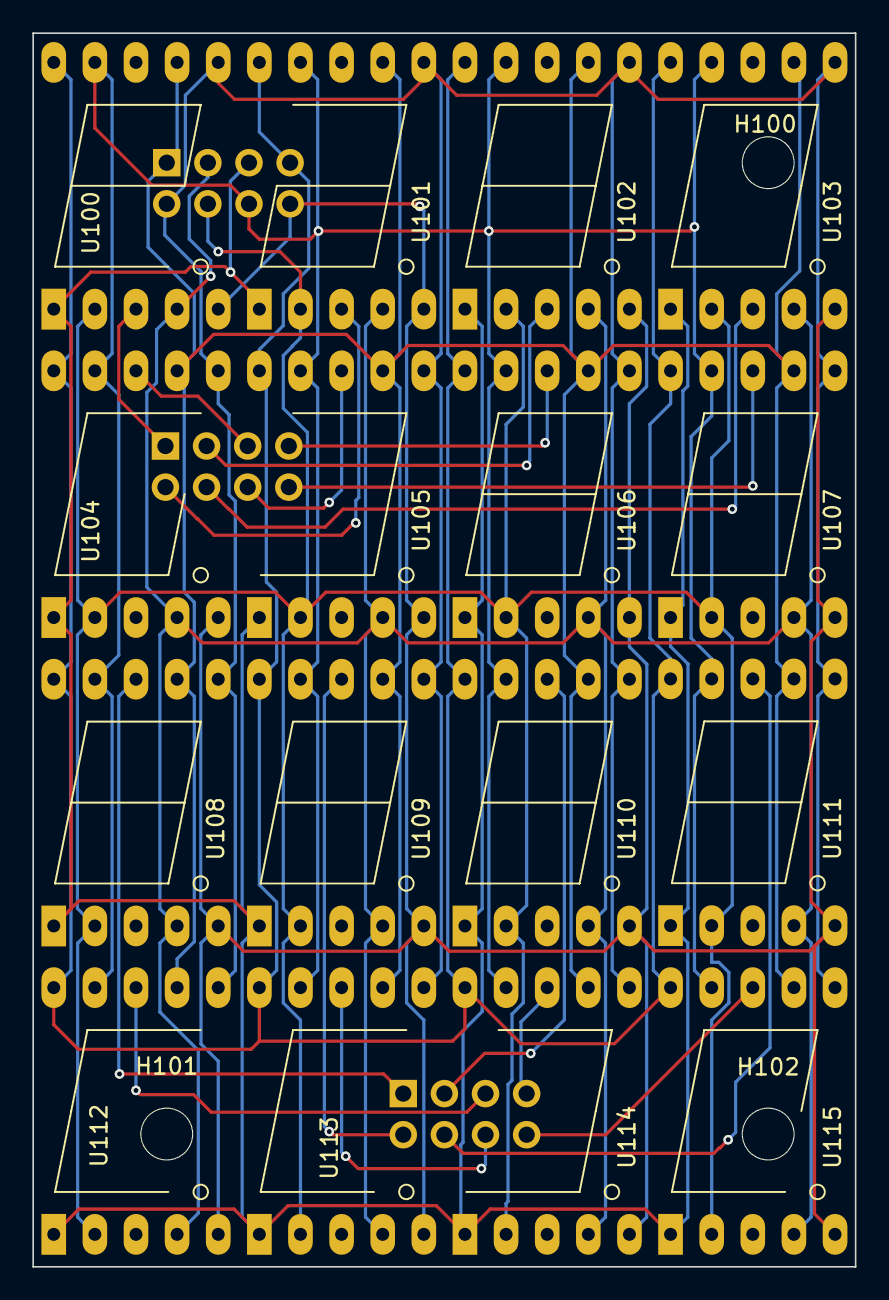
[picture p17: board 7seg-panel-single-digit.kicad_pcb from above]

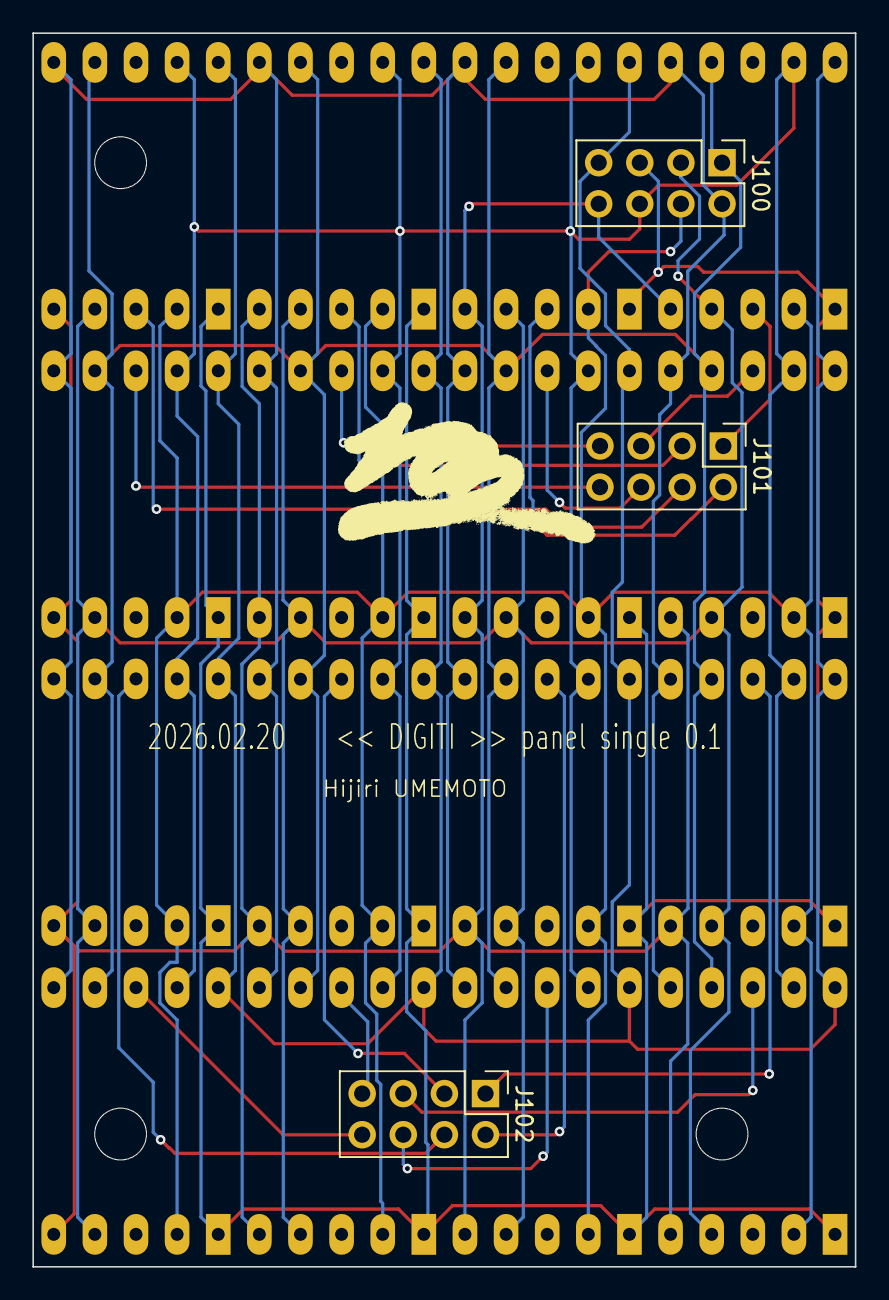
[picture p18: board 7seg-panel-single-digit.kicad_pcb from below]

Board: 2 copper layers, 50.8 x 76.2 mm, 22 parts (3 on the bottom side), 24 nets.

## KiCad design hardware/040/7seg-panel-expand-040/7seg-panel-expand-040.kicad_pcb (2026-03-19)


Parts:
C102: 22uF; C_0603_1608Metric
C105: 0.1uF; C_0603_1608Metric_Pad1.08x0.95mm_HandSolder
C107: 22uF; CP_EIA-3528-21_Kemet-B_HandSolder; not fitted
H102, H103, H104, H105, H106, H107, H108, H109: MountingHole; MountingHole_3.2mm_M3
J101: CH1; Generic_XH_S2B-XH-A-1_1x02_P2.50mm_Horizontal
J102, J104: I2C; JST_XH_B2B-XH-AM_1x02_P2.50mm_Vertical
J103: CH2; Generic_XH_S2B-XH-A-1_1x02_P2.50mm_Horizontal
J105: CH3; Generic_XH_S2B-XH-A-1_1x02_P2.50mm_Horizontal
J106: CH4; Generic_XH_S2B-XH-A-1_1x02_P2.50mm_Horizontal
J107: CH6; Generic_XH_S2B-XH-A-1_1x02_P2.50mm_Horizontal
J109: CH7; Generic_XH_S2B-XH-A-1_1x02_P2.50mm_Horizontal
J111: CH8; Generic_XH_S2B-XH-A-1_1x02_P2.50mm_Horizontal
J113: CH5; Generic_XH_S2B-XH-A-1_1x02_P2.50mm_Horizontal
J117: Conn_02x03_Odd_Even; PinHeader_2x03_P2.54mm_Vertical
J119, J120: +5V; JST_XH_B2B-XH-AM_1x02_P2.50mm_Vertical
JP101: A2; PinHeader_1x03_P2.54mm_Vertical
R103, R104: 4.7kR; R_0603_1608Metric_Pad0.98x0.95mm_HandSolder; not fitted
R107, R108, R109, R110, R111, R112, R113, R114, R115, R116, R117, R118, R119, R120, R121, R122, R123: 4.7kR; R_0603_1608Metric_Pad0.98x0.95mm_HandSolder
U102: TCA9548APWR; TSSOP-24_4.4x7.8mm_P0.65mm

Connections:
EX_SCL: J102.2, J104.2, R103.2, U102.22 (SCL)
EX_SDA: J102.1, J104.1, R104.2, U102.23 (SDA)
GND2: C102.2, C105.2, C107.2, J119.1, J120.1, JP101.1, JP101.2, JP101.3, U102.12 (GND)
unnamed: J117.1, U102.1 (A0)
unnamed: J117.3, U102.2 (A1)
unnamed: J117.5, U102.21 (A2)
unnamed: R123.2, U102.3 (~RESET)
SC0: J101.2, R107.2, U102.5 (SC0)
SC1: J103.2, R109.2, U102.7 (SC1)
SC2: J105.2, R111.2, U102.9 (SC2)
SC3: J106.2, R113.2, U102.11 (SC3)
SC4: J113.2, R115.2, U102.14 (SC4)
SC5: J107.2, R117.2, U102.16 (SC5)
SC6: J109.2, R119.2, U102.18 (SC6)
SC7: J111.2, R121.2, U102.20 (SC7)
SD0: J101.1, R108.2, U102.4 (SD0)
SD1: J103.1, R110.2, U102.6 (SD1)
SD2: J105.1, R112.2, U102.8 (SD2)
SD3: J106.1, R114.2, U102.10 (SD3)
SD4: J113.1, R116.2, U102.13 (SD4)
SD5: J107.1, R118.2, U102.15 (SD5)
SD6: J109.1, R120.2, U102.17 (SD6)
SD7: J111.1, R122.2, U102.19 (SD7)
VCC2: C102.1, C105.1, C107.1, J117.2, J117.4, J117.6, J119.2, J120.2, R103.1, R104.1, R107.1, R108.1, R109.1, R110.1, R111.1, R112.1, R113.1, R114.1, R115.1, R116.1, R117.1, R118.1, R119.1, R120.1, R121.1, R122.1, R123.1, U102.24 (VCC)

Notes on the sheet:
A210 Address 000 0x70 001 0x71 ... 111 0x77
Place jumper resistors if master/expander. If slave, remove them.
Voltage drops may cause malfunction. Make sure if sufficient power supply capacity. I2C address 0x70 is robust against voltage fluctuations.
VCC 5V
Place pull-up resistors on the expander. Remove the resistors if the MCU equipps pull-up resistors or works on the different voltage.
Short the pads if the board doesn't have the expander.
EXTERNAL I2C BUS
The value of each I2C pull-up resistors may be between 4.7k and 10k ohm. If the signal is weak, reduce it.
VDD 1.65V to 5.5V
INTERNAL (EXPANDED) I2C BUS



Board: 2 copper layers, 81.3 x 33.0 mm, 41 parts (14 on the bottom side), 24 nets.

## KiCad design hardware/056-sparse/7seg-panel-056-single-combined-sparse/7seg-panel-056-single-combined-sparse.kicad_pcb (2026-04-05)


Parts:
C100: 22uF; C_0603_1608Metric
C101: 22uF; CP_EIA-3528-21_Kemet-B_HandSolder; not fitted
C102: 0.1uF; C_0603_1608Metric_Pad1.08x0.95mm_HandSolder
D100: 1N4148W; D_SOD-123
H100, H101, H102, H103: MountingHole; MountingHole_3.2mm_M3
J100, J101: +5V; JST_XH_B2B-XH-AM_1x02_P2.50mm_Vertical
J102, J103: I2C; JST_XH_B2B-XH-AM_1x02_P2.50mm_Vertical
J104: Conn_02x03_Odd_Even; PinHeader_2x03_P2.54mm_Vertical
R100, R101, R102: 39kR; R_0603_1608Metric_Pad0.98x0.95mm_HandSolder
U100, U101, U102, U103, U104, U105, U106, U107, U108, U109, U110, U111, U112, U113, U114, U115: OSL10564-IRA; 7SegmentLED_OSL10564
U116: HT16K33-28-SSOPA; SSOP-28_3.9x9.9mm_P0.635mm

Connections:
A_COM0: D100.2 (A), U100.7 (A), U101.7 (A), U102.7 (A), U103.7 (A), U104.7 (A), U105.7 (A), U106.7 (A), U107.7 (A), U108.7 (A), U109.7 (A), U110.7 (A), U111.7 (A), U112.7 (A), U113.7 (A), U114.7 (A), U115.7 (A), U116.2 (COM0/AD)
A_COM1: U100.6 (B), U101.6 (B), U102.6 (B), U103.6 (B), U104.6 (B), U105.6 (B), U106.6 (B), U107.6 (B), U108.6 (B), U109.6 (B), U110.6 (B), U111.6 (B), U112.6 (B), U113.6 (B), U114.6 (B), U115.6 (B), U116.3 (COM1/KS0)
A_COM2: U100.4 (C), U101.4 (C), U102.4 (C), U103.4 (C), U104.4 (C), U105.4 (C), U106.4 (C), U107.4 (C), U108.4 (C), U109.4 (C), U110.4 (C), U111.4 (C), U112.4 (C), U113.4 (C), U114.4 (C), U115.4 (C), U116.4 (COM2/KS1)
A_COM3: U100.2 (D), U101.2 (D), U102.2 (D), U103.2 (D), U104.2 (D), U105.2 (D), U106.2 (D), U107.2 (D), U108.2 (D), U109.2 (D), U110.2 (D), U111.2 (D), U112.2 (D), U113.2 (D), U114.2 (D), U115.2 (D), U116.5 (COM3/KS2)
A_COM4: U100.1 (E), U101.1 (E), U102.1 (E), U103.1 (E), U104.1 (E), U105.1 (E), U106.1 (E), U107.1 (E), U108.1 (E), U109.1 (E), U110.1 (E), U111.1 (E), U112.1 (E), U113.1 (E), U114.1 (E), U115.1 (E), U116.6 (COM4)
A_COM5: U100.9 (F), U101.9 (F), U102.9 (F), U103.9 (F), U104.9 (F), U105.9 (F), U106.9 (F), U107.9 (F), U108.9 (F), U109.9 (F), U110.9 (F), U111.9 (F), U112.9 (F), U113.9 (F), U114.9 (F), U115.9 (F), U116.7 (COM5)
A_COM6: U100.10 (G), U101.10 (G), U102.10 (G), U103.10 (G), U104.10 (G), U105.10 (G), U106.10 (G), U107.10 (G), U108.10 (G), U109.10 (G), U110.10 (G), U111.10 (G), U112.10 (G), U113.10 (G), U114.10 (G), U115.10 (G), U116.8 (COM6)
A_COM7: U100.5 (DP), U101.5 (DP), U102.5 (DP), U103.5 (DP), U104.5 (DP), U105.5 (DP), U106.5 (DP), U107.5 (DP), U108.5 (DP), U109.5 (DP), U110.5 (DP), U111.5 (DP), U112.5 (DP), U113.5 (DP), U114.5 (DP), U115.5 (DP)
A_ROW0: J104.1, U100.3 (CA), U116.25 (ROW0/A2)
A_ROW1: J104.3, U101.3 (CA), U116.24 (ROW1/A1)
A_ROW2: J104.5, U102.3 (CA), U116.23 (ROW2/A0)
A_ROW3: U103.3 (CA), U116.22 (ROW3/K1)
A_ROW4: U104.3 (CA), U116.21 (ROW4/K2)
A_ROW5: U105.3 (CA), U116.20 (ROW5/K3)
A_ROW6: U106.3 (CA), U116.19 (ROW6/K4)
A_ROW7: U107.3 (CA), U116.18 (ROW7/K5)
A_ROW8: U108.3 (CA), U116.17 (ROW9/K6)
A_ROW9: U109.3 (CA), U116.16 (ROW9/K7)
A_ROW10: U110.3 (CA), U116.15 (ROW10/K8)
A_ROW11: U111.3 (CA), U116.14 (ROW11/K9)
A_ROW12: U112.3 (CA), U116.12 (ROW13/K12)
A_ROW13: U113.3 (CA), U116.13 (ROW12/K10)
A_ROW14: U114.3 (CA), U116.10 (ROW15/K13/INT)
A_ROW15: U115.3 (CA), U116.11 (ROW14/K12)
GND: C100.2, C101.2, C102.2, J100.1, J101.1, U116.1 (VCC)
unnamed: D100.1 (K), R100.1, R101.1, R102.1
unnamed: J104.2, R102.2
unnamed: J104.4, R101.2
unnamed: J104.6, R100.2
SCL: J102.2, J103.2, U116.26 (SCL)
SDA: J102.1, J103.1, U116.27 (SDA)
VDD: C100.1, C101.1, C102.1, J100.2, J101.2, U116.28 (VDD)

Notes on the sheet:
VDD min. 4.5V, max. 5.5V
It's advisable to use a small IR diode, such as 1N4148W silicone diode, etc. Shot key diodes may work, but not parfect in high-tempature conditions.
Wiring for Com-Anode.
EXTERNAL I2C BUS
39-47kR
A2 A1 A0

Board: 2 copper layers, 33 parts (0 on the bottom side), 32 nets, no tracks yet.

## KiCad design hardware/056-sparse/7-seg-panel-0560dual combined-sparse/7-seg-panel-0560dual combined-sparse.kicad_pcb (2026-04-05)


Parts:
C103: 22uF; C_0603_1608Metric
C104: 22uF; CP_EIA-3528-21_Kemet-B_HandSolder; not fitted
C106: 0.1uF; C_0603_1608Metric_Pad1.08x0.95mm_HandSolder
D102: 1N4148W; D_SOD-123
H100, H101, H102, H103: MountingHole; MountingHole_3.2mm_M3
J114, J115: +5V; JST_XH_B2B-XH-AM_1x02_P2.50mm_Vertical
J116: Conn_02x03_Odd_Even; PinHeader_2x03_P2.54mm_Vertical
J118, J121: I2C; JST_XH_B2B-XH-AM_1x02_P2.50mm_Vertical
R124, R125, R126: 39kR; R_0603_1608Metric_Pad0.98x0.95mm_HandSolder
U100, U101, U102, U103, U104, U105, U106, U107: SL-9263; DA56-11CGKWA
U116: HT16K33-28-SOPA; SOP-28_8.4x18.16mm_P1.27mm

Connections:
A_COM0: D102.2 (A), U100.7 (a), U101.7 (a), U102.7 (a), U103.7 (a), U104.7 (a), U105.7 (a), U106.7 (a), U107.7 (a), U116.2 (COM0/AD)
A_COM1: U100.6 (b), U101.6 (b), U102.6 (b), U103.6 (b), U104.6 (b), U105.6 (b), U106.6 (b), U107.6 (b), U116.3 (COM1/KS0)
A_COM2: U100.4 (c), U101.4 (c), U102.4 (c), U103.4 (c), U104.4 (c), U105.4 (c), U106.4 (c), U107.4 (c), U116.4 (COM2/KS1)
A_COM3: U100.1 (d), U101.1 (d), U102.1 (d), U103.1 (d), U104.1 (d), U105.1 (d), U106.1 (d), U107.1 (d), U116.5 (COM3/KS2)
A_COM4: U100.3 (e), U101.3 (e), U102.3 (e), U103.3 (e), U104.3 (e), U105.3 (e), U106.3 (e), U107.3 (e), U116.6 (COM4)
A_COM5: U100.8 (f), U101.8 (f), U102.8 (f), U103.8 (f), U104.8 (f), U105.8 (f), U106.8 (f), U107.8 (f), U116.7 (COM5)
A_COM6: U100.9 (g), U101.9 (g), U102.9 (g), U103.9 (g), U104.9 (g), U105.9 (g), U106.9 (g), U107.9 (g), U116.8 (COM6)
A_ROW0: J116.1, U100.10 (CA_D1), U116.25 (ROW0/A2)
A_ROW1: J116.3, U100.5 (CA_D2), U116.24 (ROW1/A1)
A_ROW2: J116.5, U101.10 (CA_D1), U116.23 (ROW2/A0)
A_ROW3: U101.5 (CA_D2), U116.22 (ROW3/K1)
A_ROW4: U102.10 (CA_D1), U116.21 (ROW4/K2)
A_ROW5: U102.5 (CA_D2), U116.20 (ROW5/K3)
A_ROW6: U103.10 (CA_D1), U116.19 (ROW6/K4)
A_ROW7: U103.5 (CA_D2), U116.18 (ROW7/K5)
A_ROW8: U104.10 (CA_D1), U116.17 (ROW9/K6)
A_ROW9: U104.5 (CA_D2), U116.16 (ROW9/K7)
A_ROW10: U105.10 (CA_D1), U116.15 (ROW10/K8)
A_ROW11: U105.5 (CA_D2), U116.14 (ROW11/K9)
A_ROW12: U106.10 (CA_D1), U116.12 (ROW13/K12)
A_ROW13: U106.5 (CA_D2), U116.13 (ROW12/K10)
A_ROW14: U107.10 (CA_D1), U116.10 (ROW15/K13/INT)
A_ROW15: U107.5 (CA_D2), U116.11 (ROW14/K12)
GND: C103.2, C104.2, C106.2, J114.1, J115.1, U116.1 (VCC)
unnamed: D102.1 (K), R124.1, R125.1, R126.1
unnamed: J116.2, R126.2
unnamed: J116.4, R125.2
unnamed: J116.6, R124.2
SCL: J118.2, J121.2, U116.26 (SCL)
SDA: J118.1, J121.1, U116.27 (SDA)
VDD: C103.1, C104.1, C106.1, J114.2, J115.2, U116.28 (VDD)

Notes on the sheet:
VDD min. 4.5V, max. 5.5V
It's advisable to use a small IR diode, such as 1N4148W silicone diode, etc. Shot key diodes may work, but not parfect in high-tempature conditions.
Wiring for Com-Anode.
EXTERNAL I2C BUS
39-47kR
A2 A1 A0

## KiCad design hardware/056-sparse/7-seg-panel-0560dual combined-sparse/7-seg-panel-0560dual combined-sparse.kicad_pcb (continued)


Board: 2 copper layers, 100.0 x 100.0 mm, 25 parts (0 on the bottom side), 31 nets.

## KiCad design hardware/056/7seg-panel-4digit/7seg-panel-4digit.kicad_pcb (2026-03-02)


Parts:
H101, H201, H202: MountingHole; MountingHole_3.2mm_M3
J201, J202, J203: Conn_02x04_Odd_Even; PinHeader_2x04_P2.54mm_Vertical
U101, U102, U103, U104: CA56-12EWA

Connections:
COM0: J201.1, U101.11 (a), U102.11 (a), U103.11 (a), U104.11 (a)
COM1: J201.2, U101.7 (b), U102.7 (b), U103.7 (b), U104.7 (b)
COM2: J201.3, U101.4 (c), U102.4 (c), U103.4 (c), U104.4 (c)
COM3: J201.4, U101.2 (d), U102.2 (d), U103.2 (d), U104.2 (d)
COM4: J201.5, U101.1 (e), U102.1 (e), U103.1 (e), U104.1 (e)
COM5: J201.6, U101.10 (f), U102.10 (f), U103.10 (f), U104.10 (f)
COM6: J201.7, U101.5 (g), U102.5 (g), U103.5 (g), U104.5 (g)
COM7: J201.8, U101.3 (DPX), U102.3 (DPX), U103.3 (DPX), U104.3 (DPX)
ROW0: J202.1, U101.12 (CA1)
ROW1: J202.2, U101.9 (CA2)
ROW2: J202.3, U101.8 (CA3)
ROW3: J202.4, U101.6 (CA4)
ROW4: J202.5, U102.12 (CA1)
ROW5: J202.6, U102.9 (CA2)
ROW6: J202.7, U102.8 (CA3)
ROW7: J202.8, U102.6 (CA4)
ROW8: J203.1, U103.12 (CA1)
ROW9: J203.2, U103.9 (CA2)
ROW10: J203.3, U103.8 (CA3)
ROW11: J203.4, U103.6 (CA4)
ROW12: J203.5, U104.12 (CA1)
ROW13: J203.6, U104.9 (CA2)
ROW14: J203.7, U104.8 (CA3)
ROW15: J203.8, U104.6 (CA4)

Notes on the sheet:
Wiring for Com-Anode.



Board: 2 copper layers, 50.8 x 76.2 mm, 10 parts (3 on the bottom side), 24 nets.

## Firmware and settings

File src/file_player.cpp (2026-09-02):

#include "common.h"
#include "led.h"
#include "playback.h"
#include "main_common.hpp" 
#include "video.h"
#include "file_audio_gst.h"
#include "audio.h"
#include <thread>
#include <mutex>
#include <condition_variable>
#include <deque>
#include <unistd.h>

int main(int argc, char* argv[]) {
    const std::string usage = 
        "Usage: " + std::string(argv[0]) + " <video_file> [config_name] [options]\n"
        "  config_name: 24x4 (default), 12x8, etc. from config.json\n"
        "  options:\n"
        "    --crop, -c: Crop to fit aspect ratio\n"
        "    --stretch, -s: Stretch to fill display\n"
        "    --fit, -f: Fit entire video within display (may add padding) (default)\n"
        "    --threshold min max, -t min max: Set binarization threshold (default: 64 255)\n"
        "    --loop, -l: Repeat video playback (file-player only)\n"
        "    --record-mp4 PATH: Record emulator output to an MP4 file\n"
        "    --config-file PATH: Load settings from a specific config file";

    // common_main_runner を呼び出し、ファイル再生ロジックをラムダ式で渡す
    return common_main_runner(usage, argc, argv,
        [](const std::string& video_path, const DisplayConfig& config, ScalingMode scaling_mode, int min_threshold, int max_threshold, bool debug, bool loop, const std::string& record_mp4_path) {
            std::atomic<bool> stop_flag(false);
            // g_should_exit は共通シグナルハンドラで更新される
            // watch_dog スレッドは不要（再生ループ側で g_should_exit を参照するため）
            
            // 再生関数をラップ
            auto play_once = [&](void) -> int {
                if (config.type == "emulator") {
                    return play_video_stream_emulator(video_path, config, stop_flag, scaling_mode, min_threshold, max_threshold, debug, record_mp4_path, !record_mp4_path.empty());
                } else {
                    return play_video_stream(video_path, config, stop_flag, scaling_mode, min_threshold, max_threshold, debug);
                }
            };

            if (config.type == "emulator") {
                if (loop) {
                    int loop_count = 0;
                    while (!stop_flag && !g_should_exit) {
                        loop_count++;
                        if (debug) std::cerr << "[file_player] emulator loop iteration " << loop_count << std::endl;
                        int rc = play_once();
                        if (debug) std::cerr << "[file_player] play_once returned rc=" << rc << std::endl;
                        if (stop_flag || g_should_exit) break;
                        std::this_thread::sleep_for(std::chrono::milliseconds(100));
                        (void)rc;
                    }
                } else {
                    (void)play_once();
                }
            } else {
                auto play_fileplayer = [&](void) -> int {
                    // 非同期I2Cライターを使った再生（file-player専用）
                    std::atomic<bool> writer_stop(false);
                    std::mutex q_mtx;
                    std::condition_variable q_cv;
                    std::deque<std::vector<uint8_t>> q;

                    // I2Cオープンと初期化はメインスレッドで行い、ライタースレッドは同じfdを使う
                    int i2c_fd = open_i2c_auto(config);
                    if (i2c_fd < 0) {
                        std::cerr << "I2C communication failed: No I2C devices found or access denied." << std::endl;
                        return -1;
                    }
                    if (!initialize_displays(i2c_fd, config)) {
                        std::cerr << "Failed to initialize display modules." << std::endl;
                        close(i2c_fd);
                        return -1;
                    }

                    // ライタースレッド
                    std::thread writer([&]{
                        while (!writer_stop) {
                            std::vector<uint8_t> frame;
                            {
                                std::unique_lock<std::mutex> lk(q_mtx);
                                if (q.empty()) {
                                    q_cv.wait_for(lk, std::chrono::milliseconds(5));
                                    if (q.empty()) continue;
                                }
                                // 最新フレームだけ残す（遅延削減）
                                while (q.size() > 1) q.pop_front();
                                frame = std::move(q.front());
                                q.pop_front();
                            }

                            if (frame.empty()) continue;
                            I2CErrorInfo err;
                            // 非同期でも既存の更新関数を使う（モジュール単位で失敗しても戻る）
                            if (!update_flexible_display(i2c_fd, config, frame, err)) {
                                std::cerr << "[file-player writer] I2C write failed (non-blocking): attempting recovery" << std::endl;
                                // 復旧は試すが、失敗してもループ継続（メインはブロックされない）
                                attempt_i2c_recovery(i2c_fd, config);
                            }
                        }
                    });

                    // --- ビデオ/オーディオ開始とフレーム生成（主ループ） ---
                    cv::VideoCapture cap;
                    if (video_path == "-") {
                        const std::string gst_pipeline = 
                             "fdsrc ! decodebin name=d "
                            "d. ! queue ! videoconvert ! appsink "
                            "d. ! queue ! audioconvert ! audioresample ! autoaudiosink";
                        cap.open(gst_pipeline, cv::CAP_GSTREAMER);
                    } else {
                        cap.open(video_path, cv::CAP_FFMPEG);
                    }
                    if (!cap.isOpened()) {
                        std::cerr << "動画ソースを開けません: " << video_path << std::endl;
                        writer_stop = true; q_cv.notify_all(); writer.join(); close(i2c_fd); return -1;
                    }

                    bool use_ffplay = false;
                    if (const char* e = std::getenv("FILE_AUDIO_USE_FFPLAY")) {
                        if (std::string(e) == "1" || std::string(e) == "true") use_ffplay = true;
                    }
                    if (video_path != "-") {
                        if (use_ffplay) {
                            std::string command = "ffplay -nodisp -autoexit \"" + video_path + "\" > /dev/null 2>&1 &";
                            system(command.c_str());
                        } else {
                            bool inited = audio_init(SAMPLE_RATE, CHANNELS);
                            bool ok = inited && file_audio_start(video_path);
                            if (!ok) {
                                if (inited) audio_cleanup();
                                std::string command = "ffplay -nodisp -autoexit \"" + video_path + "\" > /dev/null 2>&1 &";
                                system(command.c_str());
                                use_ffplay = true;
                            }
                        }
                    }

                    double fps = cap.get(cv::CAP_PROP_FPS);
                    if (fps <= 0) fps = 30.0;
                    auto frame_duration = std::chrono::microseconds(static_cast<long long>(1000000.0 / fps));

                    auto next_frame_time = std::chrono::steady_clock::now();
                    cv::Mat frame;
                    while (!g_should_exit && !stop_flag && cap.read(frame)) {
                        cv::Mat gray;
                        cv::cvtColor(frame, gray, cv::COLOR_BGR2GRAY);
                        cv::Mat bw;
                        cv::threshold(gray, bw, min_threshold, max_threshold, cv::THRESH_BINARY);
                        std::vector<uint8_t> grid;
                        frame_to_grid(bw, config, grid);

                        // enqueue latest frame (非ブロッキング)
                        {
                            std::lock_guard<std::mutex> lk(q_mtx);
                            q.push_back(grid);
                            if (q.size() > 4) q.pop_front();
                        }
                        q_cv.notify_one();

                        next_frame_time += frame_duration;
                        std::this_thread::sleep_until(next_frame_time);
                    }

                    // 停止処理
                    writer_stop = true; q_cv.notify_all();
                    if (writer.joinable()) writer.join();
                    if (video_path != "-") {
                        if (use_ffplay) system("killall ffplay > /dev/null 2>&1"); else { file_audio_stop(); audio_cleanup(); }
                    }
                    cap.release();
                    close(i2c_fd);
                    return 0;
                };

                if (loop) {
                    std::cerr << "[file_player] loop enabled" << std::endl;
                    // 指定があれば動画終了後に繰り返す（stop_flag が立てられたら終了）
                    int loop_count = 0;
                    while (!stop_flag && !g_should_exit) {
                        loop_count++;
                        if (debug) std::cerr << "[file_player] starting loop iteration " << loop_count << std::endl;
                        int rc = play_fileplayer();
                        if (debug) std::cerr << "[file_player] play_fileplayer returned rc=" << rc << std::endl;
                        if (stop_flag) break;
                        if (g_should_exit) break;
                        // 再開前に少し待つ（無限ループ防止）
                        std::this_thread::sleep_for(std::chrono::milliseconds(100));
                        (void)rc; // rc は将来的な利用のために残す
                    }
                    std::cerr << "[file_player] loop exiting after " << loop_count << " iterations" << std::endl;
                } else {
                    (void)play_fileplayer();
                }

                // ここでの待ちは不要。playback ループは g_should_exit を見て終了する。

                // 再生終了時に物理パネルを消灯する（エミュレータでは不要）
                if (config.type != "emulator") {
                    if (!clear_all_displays(config)) {
                        std::cerr << "Warning: failed to clear displays on exit." << std::endl;
                    } else {
                        std::cerr << "Displays cleared on exit." << std::endl;
                    }
                }
            }
        }
    );
}

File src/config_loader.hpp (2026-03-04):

#pragma once

#include <string>
#include <fstream>
#include <vector>
#include <map>
#include <stdexcept>
#include "json.hpp" // nlohmann/json をインクルード
#include "config.h" // 既存のDisplayConfig構造体の定義をインクルード

// JSONをパースするためのヘルパー
using json = nlohmann::json;

// JSONから16進数文字列をintに変換するヘルパー関数
int hex_str_to_int(const std::string& hex_str) {
    return std::stoi(hex_str, nullptr, 16);
}

DisplayConfig load_config_from_json(const std::string& config_name, const std::string& filename = "config.json") {
    std::ifstream f(filename);
    if (!f.is_open()) {
        throw std::runtime_error("Could not open config file: " + filename);
    }
    json data = json::parse(f);

    if (!data["configurations"].contains(config_name)) {
        throw std::runtime_error("Configuration not found: " + config_name);
    }

    const auto& conf_json = data["configurations"][config_name];
    DisplayConfig config;

    config.name = conf_json["name"];
    if (conf_json.contains("type")) {
        config.type = conf_json["type"];
    } else {
        config.type = "physical";
    }

    if (conf_json.contains("buses")) {
        for (const auto& [bus_str, bus_json] : conf_json["buses"].items()) {
            int bus_id = std::stoi(bus_str);
            BusConfig bus_config;
            if (bus_json.contains("tca9548as")) {
                for (const auto& tca_json : bus_json["tca9548as"]) {
                    TCA9548AConfig tca;
                    if (tca_json.contains("address") && !tca_json["address"].is_null()) {
                        tca.address = hex_str_to_int(tca_json["address"]);
                    } else {
                        tca.address = -1;
                    }
                    if (tca_json.contains("channels")) {
                        for (const auto& [ch_str, grid_json] : tca_json["channels"].items()) {
                            int channel = std::stoi(ch_str);
                            std::vector<std::vector<int>> grid;
                            for (const auto& row_json : grid_json) {
                                std::vector<int> row;
                                for (const auto& addr_str : row_json) {
                                    row.push_back(hex_str_to_int(addr_str));
                                }
                                grid.push_back(row);
                            }
                            tca.channels[channel] = grid;
                        }
                    }
                    if (tca_json.contains("rows")) {
                        for (const auto& [row_str, row_config_json] : tca_json["rows"].items()) {
                            int row = std::stoi(row_str);
                            int channel = row_config_json["channel"];
                            int row_offset = row_config_json["row_offset"];
                            int col_offset = row_config_json["col_offset"];
                            tca.rows[row] = {channel, row_offset, col_offset};
                        }
                    }
                    bus_config.tca9548as.push_back(tca);
                }
            }
            config.buses[bus_id] = bus_config;
        }
    }

    config.module_digits_width = conf_json["module_digits_width"];
    config.module_digits_height = conf_json["module_digits_height"];
    config.total_width = conf_json["total_width"];
    config.total_height = conf_json["total_height"];

    // Optional: per-module size overrides
    if (conf_json.contains("module_sizes")) {
        for (const auto& [addr_str, size_json] : conf_json["module_sizes"].items()) {
            int addr = 0;
            try {
                if (addr_str.rfind("0x", 0) == 0 || addr_str.rfind("0X", 0) == 0) {
                    addr = std::stoi(addr_str, nullptr, 16);
                } else {
                    addr = std::stoi(addr_str);
                }
            } catch (...) {
                // ignore invalid keys
                continue;
            }
            if (size_json.is_array() && size_json.size() >= 2) {
                int w = size_json[0];
                int h = size_json[1];
                config.module_sizes_by_address[addr] = {w, h};
            }
        }
    }

    // Optional: per-module column reversal flags
    if (conf_json.contains("module_column_reverse")) {
        for (const auto& [addr_str, val] : conf_json["module_column_reverse"].items()) {
            int addr = 0;
            try {
                if (addr_str.rfind("0x", 0) == 0 || addr_str.rfind("0X", 0) == 0) {
                    addr = std::stoi(addr_str, nullptr, 16);
                } else {
                    addr = std::stoi(addr_str);
                }
            } catch (...) {
                continue;
            }
            bool b = false;
            try { b = static_cast<bool>(val.get<bool>()); } catch(...) { b = false; }
            config.module_column_reverse[addr] = b;
        }
    }
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

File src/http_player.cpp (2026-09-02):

#include "common.h"
#include "playback.h"
#include "main_common.hpp" // ★★★ 共通ヘッダーをインクルード
#include "httplib.h"

#include <vector>
#include <deque>
#include <thread>
#include <string>
#include <atomic>
#include <mutex>
#include <condition_variable>
#include <fstream>
#include <sstream>
#include <dirent.h>

#include <csignal>   // ★★★ signal のために追加 ★★★
#include <map>       // ★★★ エラー分析のために追加 ★★★
#include <utility>   // ★★★ エラー分析のために追加 ★★★
#include <iomanip>   // ★★★ std::hex のために追加 ★★★

// --- グローバル変数 ---
std::deque<std::string> video_queue;
std::string g_currently_playing;
std::atomic<bool> g_stop_current_video(false);
std::mutex queue_mutex;
std::condition_variable queue_cond;
const size_t MAX_FILE_SIZE = 100 * 1024 * 1024;
std::vector<std::string> g_default_videos;
size_t g_next_default_video_index = 0;

// 画像処理パラメータ
ScalingMode g_scaling_mode = ScalingMode::FIT;
int g_min_threshold = 64;
int g_max_threshold = 255;

// I2Cエラー分析用のグローバル変数
std::map<std::pair<int, int>, int> g_error_counts;

// アプリケーション終了用のシグナルハンドラ
void http_player_shutdown_handler(int signal_num) {
    if (signal_num == SIGINT) {
        if (!g_should_exit) {
            std::cout << "\nSIGINT received, shutting down..." << std::endl;
            
            // --- I2C Error Analysis ---
            std::cout << "\n--- I2C Error Analysis ---" << std::endl;
            if (g_error_counts.empty()) {
                std::cout << "No I2C errors were recorded." << std::endl;
            } else {
                for (const auto& [key, count] : g_error_counts) {
                    std::cout << "Channel: " << key.first 
                              << ", Address: 0x" << std::hex << key.second << std::dec
                              << "  => " << count << " errors" << std::endl;
                }
            }
            std::cout << "--------------------------" << std::endl;

            g_should_exit = true;
        }
    }
}


void load_default_videos(const std::string& path, std::vector<std::string>& videos) {
    DIR *dir;
    struct dirent *ent;
    if ((dir = opendir(path.c_str())) != NULL) {
        while ((ent = readdir(dir)) != NULL) {
            std::string filename = ent->d_name;
            if (filename[0] != '.' && (
                filename.length() > 4 && (filename.substr(filename.length() - 4) == ".mp4" || filename.substr(filename.length() - 4) == ".mov")
            )) {
                videos.push_back(path + "/" + filename);
            }
        }
        closedir(dir);
        if (!videos.empty()) std::cout << videos.size() << " default videos loaded from '" << path << "'." << std::endl;
        else std::cout << "No default videos found in '" << path << "'." << std::endl;
    } else {
        std::cerr << "Warning: Could not open default video directory '" << path << "'." << std::endl;
    }
}

void playback_thread_worker(const DisplayConfig& config) { // ★★★ configを引数で受け取る
    while (!g_should_exit) {
        std::string path_to_play;
        {
            std::unique_lock<std::mutex> lock(queue_mutex);
            queue_cond.wait(lock, [&]{ return !video_queue.empty() || !g_default_videos.empty() || g_should_exit; });
            if (g_should_exit) break;
            if (!video_queue.empty()) {
                path_to_play = video_queue.front(); video_queue.pop_front();
            } else if (!g_default_videos.empty()) {
                path_to_play = g_default_videos[g_next_default_video_index];
                g_next_default_video_index = (g_next_default_video_index + 1) % g_default_videos.size();
            }
            if (!path_to_play.empty()) g_currently_playing = path_to_play;
        }

        if (!path_to_play.empty()) {
            if (config.type == "emulator") {
                play_video_stream_emulator(path_to_play, config, g_stop_current_video, g_scaling_mode, g_min_threshold, g_max_threshold);
            } else {
                play_video_stream(path_to_play, config, g_stop_current_video, g_scaling_mode, g_min_threshold, g_max_threshold);
            }
            g_stop_current_video = false; // 次の再生のためにリセット
            {
                std::lock_guard<std::mutex> lock(queue_mutex);
                g_currently_playing = "";
            }
        }
    }
}

// メインスレッドで実行する動画再生ワーカー（GUI表示のため）
void playback_thread_worker_main(const DisplayConfig& config) {
    while (!g_should_exit) {
        std::string path_to_play;
        {
            std::unique_lock<std::mutex> lock(queue_mutex);
            queue_cond.wait(lock, [&]{ return !video_queue.empty() || !g_default_videos.empty() || g_should_exit; });
            if (g_should_exit) break;
            if (!video_queue.empty()) {
                path_to_play = video_queue.front(); video_queue.pop_front();
            } else if (!g_default_videos.empty()) {
                path_to_play = g_default_videos[g_next_default_video_index];
                g_next_default_video_index = (g_next_default_video_index + 1) % g_default_videos.size();
            }
            if (!path_to_play.empty()) g_currently_playing = path_to_play;
        }

        if (!path_to_play.empty()) {
            if (config.type == "emulator") {
                play_video_stream_emulator(path_to_play, config, g_stop_current_video, g_scaling_mode, g_min_threshold, g_max_threshold);
            } else {
                play_video_stream(path_to_play, config, g_stop_current_video, g_scaling_mode, g_min_threshold, g_max_threshold);
            }
            g_stop_current_video = false; // 次の再生のためにリセット
            {
                std::lock_guard<std::mutex> lock(queue_mutex);
                g_currently_playing = "";
            }
        }
    }
}
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

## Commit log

2025-08-22 単一ファイルからモジュール化した。
2025-08-22 モジュール化。
2025-08-24 camera control
2025-09-02 i2c error recovory
2025-09-07 feat: add macOS camera RTP sender script (H.264+Opus, 320x240@15fps, FEC, VTenc fallback)
2025-09-08 obs relay
2025-09-08 PCB version up
    [7seg-led-CuBottom.gbr, 7seg-led-CuTop.gbr, 7seg-led-EdgeCuts.gbr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]
2025-09-16 Ruspberry Pi and multiple i2c bus support
2025-09-17 feat: Refactor config.json to Bus-based structure supporting multiple TCA9548A
    - Update DisplayConfig struct to use buses with TCA9548A lists
    - Modify config_loader.hpp to parse buses configuration
    - Fix LED offset calculations in led.cpp for proper module positioning
    - Correct ROI calculation in video.cpp to prevent out-of-bounds access for D segment
    - Update test_i2c.cpp to display TCA addresses from buses
    - Add README.config.md for configuration documentation
    [video.cpp]
2025-09-17 Optimize video processing and emulator rendering performance
    - Video processing optimizations:
    * Add VideoProcessingCache struct to cache ROI calculations and sampling coordinates
    * Pre-compute sampling coordinate tables to eliminate per-frame calculations
    * Optimize frame_to_grid function to use cached coordinates
    * Reduce computational overhead by ~90% for video-to-LED conversion
    - Emulator rendering optimizations:
    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
2025-09-21 Implement 48x8 LED panel support with rows-based layout
    - Add 48x8 configuration with TCA9548A channel multiplexing
    - Update Makefile for platform-specific builds (ROCK5B/RPi5)
    - Fix tetris.py to support new config structure and rows-based display
    - Update README.config.md with 48x8 example and rows documentation
    - Debug and fix LED display issues for proper 48x8 rendering
    [config_loader.hpp, led.cpp]
2025-09-21 Add comprehensive LED screensaver with multiple animation modes and command-line options
    - Implement IP address display with centering
    - Add breakout game with paddle AI and destructible blocks
    - Add invaders game with cannon and enemy AI
    - Add miyajima modes with count-up and scrolling animations
    - Add clock display mode
    - Add command-line options for mode selection and configuration
    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
2025-09-23 i2c bus selection
2025-10-05 video: FIT/CROP/STRETCH fixes; add --debug flag; document behavior in README
    [file_player.cpp, http_player.cpp, playback.cpp]
2025-10-05 file-player: add debug prints to diagnose --loop behavior
2025-10-05 file-player: remove unnecessary watchdog thread to avoid join blocking after playback
    [file_player.cpp]
2025-10-05 Integrate FIT/CROP/STRETCH fixes, add --debug and file-player --loop; update README
    [http_player.cpp, udp_player.cpp]
2025-10-05 chore: ignore local test media and KiCad fp caches
2025-10-05 chore: add hardware files and config changes
    [7seg-control.kicad_pcb, 7seg-control.kicad_sch, 7seg-led.kicad_pcb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]
2026-03-02 hardware panel 040 size added
    [7seg-panel-4digit.kicad_pcb, 7seg-panel-4digit.kicad_sch, 7seg-panel-control-04in.kicad_pcb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]
2026-03-02 消灯処理
2026-03-02 パネル設定の拡張
2026-03-04 パネル定義追加
2026-03-04 4桁と8桁ごとの処理を行うよう修正
2026-03-04 reverseオプション追加
2026-03-04 逆順の設定を追加
2026-03-19 ファイル再生時の音声と動画の同期確認
    [20260308-040-24x16.kicad_pcb, 7seg-panel-040-display-dual-wide.kicad_pcb, 7seg-panel-040-display-dual-wide.kicad_sch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]
2026-03-19 遅延対策 パイプラインの時間まち
2026-04-05 Add led_sequencer with i2c mapping and README
2026-04-05 hardware: KiCad ファイルの更新と不要ファイルの削除
    [7-seg-panel-0560dual combined-sparse.kicad_pcb, 7-seg-panel-0560dual combined-sparse.kicad_sch, 7seg-panel-040-display-dual-wide.kicad_pcb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]
2026-04-05 Make i2c writes digit-specific (use apply_grid_to_modules); include DP; ALL ON uses 0xFF
2026-04-05 Fix: parse module addresses to integers in apply_grid_to_modules before I2C writes
2026-04-10 added pcb designs
    [20260308-040-24x16.kicad_pcb, 20260309-digiti-control-single_bom.csv, 20260309-digiti-control-single_designators.csv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]
2026-04-15 config only
    [7seg-panel-control-040-dual.kicad_pcb, 7seg-panel-power-040.kicad_pcb]
2026-04-15 file-player: async I2C writer to avoid blocking video
    [file_player.cpp]
2026-04-16 Add led_batch_test.py: batch test lighting segments A..DP on all digits
2026-04-21 Update platform note for Raspberry Pi support
2026-09-03 Clean up hardware directory
    [056-ht1635d-driver.kicad_pcb, 056-ht1635d-driver.kicad_sch, 20260309-digiti-control-single_bom.csv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]
2026-09-06 led batch test updated.
